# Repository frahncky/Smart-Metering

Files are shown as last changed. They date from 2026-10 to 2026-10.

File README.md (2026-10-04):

# Smart-Metering

Analisador trifásico de energia e qualidade de energia com interface gráfica touchscreen.

## Objetivo

Desenvolver um instrumento completo para medição, visualização e registro de grandezas elétricas em sistemas monofásicos e trifásicos, incluindo:

- tensões e correntes RMS por fase;
- potência ativa, reativa e aparente;
- fator de potência;
- frequência;
- energia importada e exportada;
- demanda;
- diagrama fasorial;
- sequência de fases;
- desequilíbrio de tensão e corrente;
- formas de onda;
- THD;
- espectro harmônico;
- registro de afundamentos, elevações, interrupções e outros eventos de qualidade de energia;
- armazenamento histórico;
- comunicação Ethernet, Wi-Fi e RS-485/Modbus;
- interface local em touchscreen de 7".

## Arquitetura inicial

```text
Rede elétrica
   |
   +--> Proteção e condicionamento de tensão ----+
   |                                             |
   +--> TCs / condicionamento de corrente -------+--> ADE9430
                                                        |
                                                        | SPI
                                                        v
                                              MCU de metrologia
                                                        |
                                              Interface isolada
                                                        |
                                                        v
                                                   ESP32-P4
                                                        |
                                            Touchscreen 7" + LVGL

                     +--> microSD
                     +--> RTC
                     +--> Ethernet
                     +--> RS-485 / Modbus
                     +--> Wi-Fi / Bluetooth via coprocessador
```

## Componentes centrais

- **ADE9430** — front-end de medição polifásica e qualidade de energia.
- **MCU ARM** — aquisição do ADE9430, cálculo complementar, gerenciamento metrológico, calibração e eventos.
- **ESP32-P4** — interface gráfica, touchscreen e serviços de alto nível.
- **ESP32-C6** — opção para Wi-Fi/Bluetooth quando necessário.
- **Touchscreen 7"** — alvo inicial: 1024 × 600, interface capacitiva.

A seleção final do MCU ARM, TCs, display, isoladores, fontes e conectores será feita antes do fechamento do esquemático.

## Estrutura do repositório

```text
Smart-Metering/
├── hardware/
│   ├── README.md
│   └── Smart-Metering/
│       ├── Smart-Metering.kicad_pro
│       ├── Smart-Metering.kicad_sch      # folha raiz hierárquica
│       ├── 01_Power_Input.kicad_sch … 09_Power_Supplies.kicad_sch
│       ├── Smart-Metering.kicad_pcb      # layout roteado (todas as ligações feitas; DRC do KiCad pendente)
│       ├── Smart-Metering.kicad_dru      # regras de isolação (clearance/creepage)
│       ├── SmartMetering.kicad_sym       # símbolos próprios
│       ├── sym-lib-table
│       └── 3d/                           # modelos 3D simplificados do projeto (gen3d.py)
├── modelo 3D/                            # gabinete: Onshape (FeatureScripts) e Fusion (montagem, STEP)
├── docs/                                 # arquitetura, requisitos, decisões, layout, revisões
├── AGENTS.md                             # papéis e regras de trabalho dos agentes
└── README.md
```

## Estado

**Fase 2 — esquemático completo da placa de metrologia (rev. 0.1, a revisar no KiCad).**

Todas as 9 folhas estão desenhadas e os sinais entre folhas foram conferidos (223 componentes):

| Folha | Conteúdo |
|---|---|
| `01_Power_Input` | Alimentação pelas fases medidas (OU de diodos, qualquer fase presente) ou entrada auxiliar, por montagem; AC/DC isolado RECOM RAC20-05SK/277 (85–305 VAC, 5 V / 4 A) → `VIN_ACDC` |
| `02_Voltage_Sensing` | 3 fases: fusível + varistor, divisor 1/1001 (5 × 200 kΩ + 1 kΩ), anti-aliasing 7,2 kHz; R201 liga neutro ao GND metrológico |
| `03_Current_Sensing` | IA/IB/IC/IN configuráveis por montagem: TC 333 mV (padrão), Rogowski ou SCT-013 de 1 V; TVS, anti-aliasing 7,2 kHz, pino de identificação; headers internos para conectores M8 de painel |
| `04_ADE9430` | ADE9430 (U401), desacoplamento, cristal 24,576 MHz, reset |
| `05_Metrology_MCU` | STM32F413RHT6 (mesma família da referência da biblioteca ADSW-PQ-CLS), HSE 8 MHz, RTC com LSE + CR2032, EEPROM de calibração 24LC64, SWD, LEDs |
| `06_Isolation` | Barreira reforçada logo após o ADE9430: ISO7762 + ISO7761, MCP3204 (ID dos sensores), ADuM6000 + TPS7A20 → `+3V3_ADE` |
| `07_HMI_Interface` | Conector para a placa HMI (ESP32-P4): +5V com PTC, UART, IRQ e EN |
| `08_Communications` | RS-485/Modbus isolada (ADM2587E) e USB-C de serviço (USB FS + carga) |
| `09_Power_Supplies` | OU de entradas 5 V, carregador chaveado BQ25895 (entrada até 3 A, I2C), `+3V3` (TPS63001) e `+5V` (TPS61022) |

A HMI (ESP32-P4 + ESP32-C6, display 7", Ethernet, Wi-Fi/BT, microSD) fica em placa separada (REQ-010). No protótipo: Espressif ESP32-P4-Function-EV-Board.

Componentes de terceiros usam os símbolos oficiais da biblioteca KiCad 10; a biblioteca `SmartMetering` guarda só os símbolos próprios. Referências numeradas por folha (1xx na folha 01, 2xx na 02, …).

### Próximos passos

Revisão completa em [`docs/REVISAO_ESQUEMATICO.md`](docs/REVISAO_ESQUEMATICO.md); as pendências P1–P9 estão resolvidas.

- Rodar o ERC no KiCad e revisar.
- Confirmações de compra: variante CP-40 do ADE9430, certificação reforçada do ADuM6000, encapsulamento do RAC20-05SK/277.
- Firmware: configurar o BQ25895 por I2C (ICHG, VREG, VINDPM) e desabilitar o VBUS sensing do OTG no STM32.
- Layout da PCB (ver [`docs/LAYOUT.md`](docs/LAYOUT.md)): placa roteada (domínio quente, lado seguro e ilha RS-485) com creepage de 8 mm na barreira; todas as ligações feitas (rev. 0.6); falta preencher as zonas e rodar o DRC do KiCad (inclui creepage); os avisos de largura esperados estão listados no LAYOUT. Todos os componentes têm modelo 3D.

## Bateria interna

Bateria Li-Po plana 1S recarregável, com NTC, carregada pelo BQ25895 com o medidor ligado à rede (folha 09, J901). Autonomia a definir; a meta anterior de 13 horas foi retirada. Ver [bateria e alimentação](docs/INTERNAL_BATTERY.md).

## Método de trabalho

Papéis dos agentes e regras de colaboração: [AGENTS.md](AGENTS.md). Etapas, revisão e rastreabilidade: [docs/WORKFLOW.md](docs/WORKFLOW.md). Decisões de projeto: [docs/DECISIONS.md](docs/DECISIONS.md). Dimensionamentos: [entradas de tensão](docs/VOLTAGE_SENSING.md), [fonte metrológica e clock](docs/POWER_CLOCK.md).

## Referências principais

- Analog Devices ADE9430: https://www.analog.com/en/products/ade9430.html
- Espressif ESP32-P4: https://documentation.espressif.com/esp32-p4_datasheet_en.html

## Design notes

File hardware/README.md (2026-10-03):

# Hardware

## Projeto KiCad

O projeto principal está em:

```text
hardware/Smart-Metering/
```

Arquivos principais:

- `Smart-Metering.kicad_pro`
- `Smart-Metering.kicad_sch`
- `Smart-Metering.kicad_pcb`

## Organização planejada do esquemático

O esquemático será hierárquico.

Folhas previstas:

1. `Power_Input`
2. `Voltage_Sensing`
3. `Current_Sensing`
4. `ADE9430`
5. `Metrology_MCU`
6. `Isolation`
7. `HMI_Interface`
8. `Communications`
9. `Power_Supplies`

A primeira implementação deverá começar por `Power_Supplies`, `Voltage_Sensing`, `Current_Sensing` e `ADE9430`.

## Regras

- manter símbolos e footprints personalizados dentro do repositório;
- não usar caminhos absolutos para bibliotecas próprias;
- registrar no Git os arquivos `.kicad_pro`, `.kicad_sch` e `.kicad_pcb`;
- não registrar backups e arquivos locais do KiCad;
- documentar alterações importantes de hardware antes de iniciar layout.

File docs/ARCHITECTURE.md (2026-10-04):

# Arquitetura do sistema

## 1. Princípio de projeto

O instrumento será dividido em dois domínios funcionais:

1. **domínio metrológico**, responsável pela aquisição elétrica, cálculos e eventos;
2. **domínio HMI/comunicação**, responsável pela tela, gráficos, armazenamento de alto nível e conectividade.

Essa separação evita que carga gráfica, rede ou interface do usuário interfiram na medição.

## 2. Cadeia de medição

### Tensão

Entradas previstas:

- VA;
- VB;
- VC;
- VN.

A entrada deverá conter proteção contra surtos/transientes, limitação, divisor resistivo de precisão e filtro anti-aliasing compatível com o ADE9430.

### Corrente

Entradas previstas:

- IA;
- IB;
- IC;
- IN opcional.

A solução inicial será baseada em transformadores de corrente (TCs). O circuito deverá permitir escolha posterior do TC e do burden sem alterar a arquitetura geral.

### Conversão e metrologia

O ADE9430 será o núcleo de aquisição.

Funções previstas:

- aquisição simultânea polifásica;
- tensão e corrente RMS;
- potências;
- energias;
- frequência;
- fator de potência;
- ângulos;
- formas de onda;
- grandezas necessárias para qualidade de energia.

Comunicação ADE9430 ↔ MCU: **SPI**.

## 3. Processador de metrologia

MCU: **STM32F413RHT6** (Cortex-M4F, 100 MHz, 1,5 MB flash, 320 KB RAM, LQFP-64).

Escolhido por ser da mesma família da plataforma de referência da biblioteca ADSW-PQ-CLS (IEC 61000-4-30 Classe S) da Analog Devices, a NUCLEO-F413ZH, o que reduz o risco de portar a biblioteca.

Responsabilidades:

- configuração e leitura do ADE9430 (SPI1 isolado) e do ADC de identificação dos sensores;
- calibração;
- processamento de formas de onda e análise harmônica complementar;
- sequência e desequilíbrio;
- detecção e registro de eventos com timestamp (RTC interno + LSE + CR2032);
- protocolo com a HMI (USART2) e Modbus RTU (USART3 + RS-485 isolada);
- USB de serviço (USB FS);
- watchdog e autodiagnóstico.

## 4. Isolação

A barreira de isolação reforçada fica **logo após o ADE9430** (folha `06_Isolation`).

- **Domínio metrológico** (potencial da rede, GND = neutro): entradas de tensão e corrente, ADE9430, ADC de identificação dos sensores.
- **Domínio seguro** (`GND_SYS`): MCU de metrologia, ESP32-P4, display, USB-C, Ethernet, RS-485, microSD.

Elementos da barreira:

- isoladores digitais reforçados (ISO7762 + ISO7761, 5 kVrms) para SPI, IRQ0/IRQ1, DREADY, ZX, CF1/CF2 e RESET;
- DC/DC isolado reforçado (≥ 4 kVAC, tensão de trabalho ≥ 300 VAC) + LDO gerando `+3V3_ADE`;
- distância de escoamento ≥ 8 mm sob a barreira, a confirmar pela IEC 61010-1 para CAT III 300 V.

Com isso o MCU pode ser gravado e depurado sem isolação de bancada, e todas as interfaces acessíveis ao usuário ficam no domínio seguro.

## 5. HMI

A HMI fica em **placa separada** (REQ-010), ligada à placa de metrologia pelo conector J701 (+5V, UART, IRQ, EN).

Processador: **ESP32-P4**, com **ESP32-C6** para Wi-Fi 6 e Bluetooth 5.

Protótipo: **Espressif ESP32-P4-Function-EV-Board** com o kit de LCD 7" 1024 × 600 MIPI-DSI. A placa já inclui Ethernet, microSD e USB, cobrindo REQ-007 e REQ-008 do lado da HMI.

Funções:

- LVGL;
- touchscreen;
- gráficos em tempo real;
- formas de onda;
- diagrama fasorial;
- espectro harmônico;
- histórico;
- menus de configuração;
- diagnóstico;
- atualização de firmware.

## 6. Telas planejadas

### Visão geral

- VA/VB/VC;
- IA/IB/IC;
- P/Q/S;
- FP;
- frequência;
- energia;
- demanda;
- THD;
- sequência de fases.

### Formas de onda

- tensões;
- correntes;
- seleção por fase;
- zoom;
- congelamento;
- evento capturado.

### Fasores

- vetores VA/VB/VC;
- vetores IA/IB/IC;
- ângulos;
- sequência ABC/ACB;
- desequilíbrio.

### Harmônicos

- seleção de tensão ou corrente;
- harmônicos por ordem;
- THD;
- tabela e gráfico de barras.

### Qualidade de energia

- sag;
- swell;
- interrupção;
- desequilíbrio;
- eventos;
- tendência;
- registro associado de forma de onda.

### Energia e demanda

- energia ativa;
- energia reativa;
- importação/exportação;
- demanda;
- máximos;
- histórico.

## 7. Interfaces externas

Previstas:

- Ethernet;
- RS-485 / Modbus RTU;
- USB-C de serviço;
- microSD;
- RTC;
- Wi-Fi;
- Bluetooth.

## 8. Ordem de desenvolvimento

1. requisitos elétricos;
2. alimentação;
3. entrada de tensão;
4. entrada de corrente;
5. ADE9430;
6. MCU de metrologia;
7. isolação;
8. comunicação entre placas;
9. ESP32-P4;
10. display/touch;
11. Ethernet/RS-485/Wi-Fi;
12. PCB;
13. firmware metrológico;
14. HMI;
15. calibração e ensaios.

## 9. Alternativas avaliadas

Em 2026-10-03 foi registrada no `main` uma arquitetura de referência alternativa. A rev. 0.1 do esquemático e do layout mantém os componentes já implementados; a tabela fica como registro para revisões futuras.

| Função | Implementado (rev. 0.1) | Alternativa avaliada |
|---|---|---|
| MCU de metrologia | STM32F413RHT6 | MAX32650 |
| Isolamento SPI/sinais | ISO7762 + ISO7761 | ADuM4152 |
| Alimentação isolada do domínio metrológico | ADuM6000 + TPS7A20 | ADuM6424A |
| RS-485 isolado | ADM2587E | ADM2867E |
| RTC | RTC interno do STM32 com LSE e CR2032 | MAX31343 |
| Wi-Fi/Bluetooth (placa HMI) | ESP32-C6 (placa de avaliação do ESP32-P4) | ESP32-C5 |
| Ethernet PHY (placa HMI) | da placa de avaliação do ESP32-P4 | DP83825I |

Os itens da placa HMI (Wi-Fi/Bluetooth, Ethernet, display MIPI-DSI) não afetam a placa de metrologia e podem ser adotados quando a HMI própria for projetada.

## 10. Alimentação e bateria interna

Entrada de 127/220 V AC pelo AC/DC RAC20-05SK/277 (folha 01). Li-Po plana 1S interna e protegida, com carregador BQ25895 com power path; `VSYS` alimenta o `+3V3` (TPS63001), o `+5V` (TPS61022) da HMI e o DC/DC isolado (ADuM6000) do domínio metrológico. Capacidade e autonomia em aberto; a proposta antiga de 13 h com pack 4S foi substituída. O `GND_SYS` (bateria, carregador, HMI) não se liga ao GND metrológico. Detalhes e pendências em `INTERNAL_BATTERY.md`.

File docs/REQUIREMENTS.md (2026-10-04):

# Requisitos iniciais

Documento de requisitos preliminar. Valores metrológicos definitivos serão fechados após a definição da classe de precisão e dos sensores.

## REQ-001 — Topologias elétricas

O instrumento deverá suportar, como objetivo de projeto:

- monofásico;
- trifásico 3 fios;
- trifásico 4 fios.

## REQ-002 — Redes alvo

O primeiro protótipo será orientado às redes:

- 127/220 V;
- 220/380 V;
- 60 Hz.

A faixa final de entrada será definida no dimensionamento do front-end.

## REQ-003 — Canais

Mínimo:

- 3 canais de tensão de fase;
- 3 canais de corrente;
- neutro como referência de tensão.

Desejável:

- canal de corrente de neutro.

## REQ-004 — Grandezas

O equipamento deverá medir ou calcular:

- tensão RMS;
- corrente RMS;
- potência ativa;
- potência reativa;
- potência aparente;
- fator de potência;
- frequência;
- energia ativa;
- energia reativa;
- demanda;
- ângulo de fase;
- sequência de fases;
- desequilíbrio.

## REQ-005 — Qualidade de energia

O projeto deverá prever:

- formas de onda;
- THD de tensão;
- THD de corrente;
- harmônicos individuais;
- afundamentos;
- elevações;
- interrupções;
- eventos com timestamp;
- captura de forma de onda associada ao evento.

O suporte integral à IEC 61000-4-30 Classe S dependerá da implementação e, quando aplicável, da biblioteca específica da Analog Devices.

## REQ-006 — Interface local

O equipamento deverá possuir:

- touchscreen colorido;
- alvo inicial de 7";
- resolução alvo de 1024 × 600;
- interface gráfica responsiva;
- operação sem necessidade de computador externo.

## REQ-007 — Armazenamento

Deverá haver armazenamento local para:

- histórico;
- eventos;
- configurações;
- registros de calibração;
- capturas de formas de onda.

Tecnologia inicial: microSD + memória não volátil interna.

## REQ-008 — Comunicação

Previstas:

- Ethernet;
- RS-485 / Modbus RTU;
- Wi-Fi;
- Bluetooth;
- USB-C para manutenção.

Protocolos adicionais poderão ser definidos posteriormente.

## REQ-009 — Segurança

O projeto deverá contemplar:

- proteção de entrada;
- isolamento adequado;
- fusíveis/proteções quando aplicável;
- separação física entre alta e baixa tensão;
- distâncias de isolação adequadas;
- gabinete que impeça acesso do usuário às partes energizadas.

## REQ-010 — Modularidade

A placa de metrologia deverá ser funcionalmente separável da placa de HMI, permitindo:

- desenvolvimento independente;
- substituição futura da HMI;
- ensaios metrológicos sem interface gráfica;
- redução da interferência entre subsistemas.

## REQ-011 — Alimentação e bateria interna

Entrada nominal de 127 V ou 220 V AC, 60 Hz, sem seletor manual. Bateria interna Li-Po plana recarregável, com proteção própria, sensor de temperatura e gerenciamento automático entre fonte e bateria. Capacidade, dimensões, peso e autonomia serão definidos pelo gabinete e pelo consumo reais. A exigência anterior de 13 horas foi retirada; o uso não fica limitado a salvar dados ou desligar.

O pack deve ser acessível para manutenção, acomodado sem compressão e com folga mecânica conforme o fabricante. Configuração 1S, com tensão de carga compatível com a célula escolhida. Bateria e HMI pertencem ao domínio seguro (`GND_SYS`), sem ligação direta ao GND metrológico referenciado à rede. Carga e descarga devem respeitar os limites térmicos e elétricos do pack.

Implementação: folha 09 (J901, BQ25895, TPS63001, TPS61022) e AC/DC RAC20-05SK/277 na folha 01. Ver `INTERNAL_BATTERY.md`.

## Pendências de definição

- classe de precisão alvo;
- corrente nominal e corrente máxima;
- modelo e relação dos TCs;
- necessidade de corrente de neutro;
- MCU ARM definitivo;
- modelo exato do display;
- estratégia de alimentação;
- topologia de isolação;
- requisitos de certificação;
- gabinete e dimensões mecânicas.

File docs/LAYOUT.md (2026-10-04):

# Layout da placa de metrologia — rev. 0.6 (placa roteada, todas as ligações feitas)

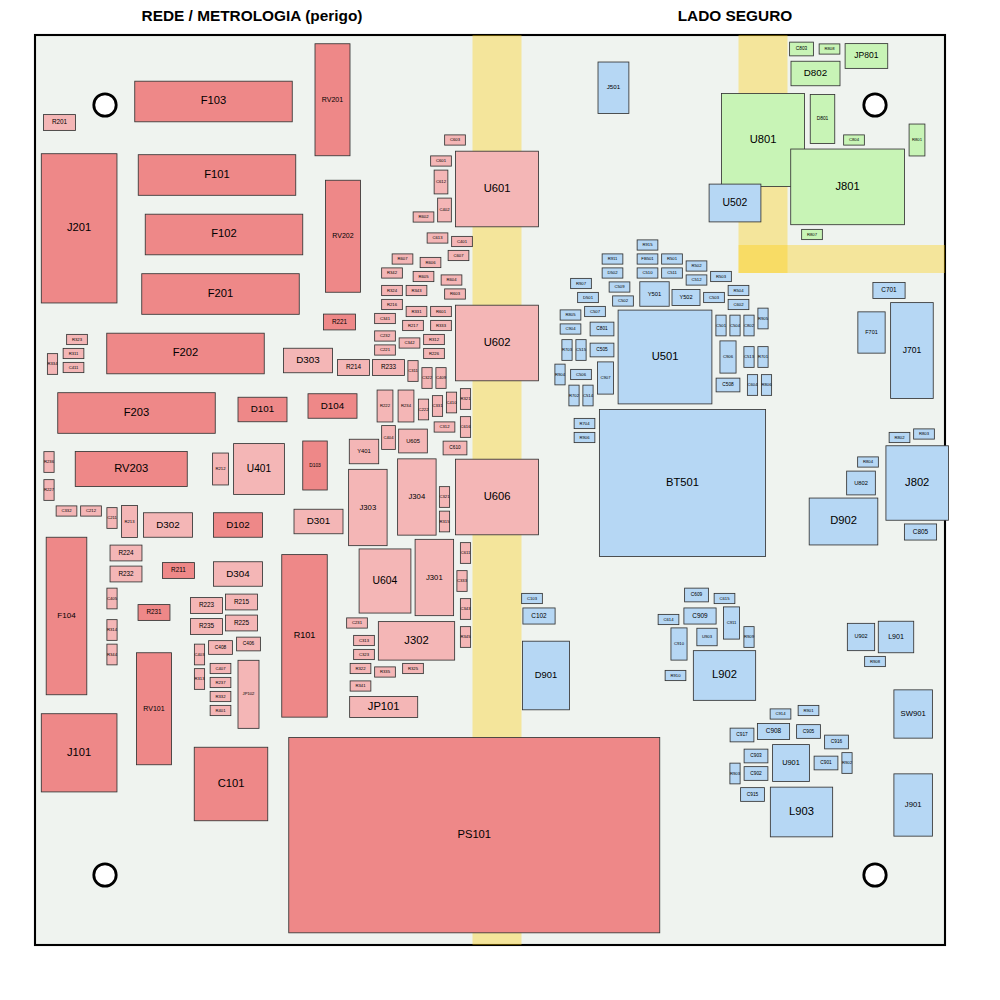
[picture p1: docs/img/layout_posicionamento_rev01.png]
Posicionamento inicial (rev. 0.1, antes dos ajustes para o roteamento)


*Vermelho escuro: nets de rede. Vermelho claro: domínio metrológico (potencial da rede). Azul: domínio seguro. Verde: RS-485 isolada. Amarelo: faixas da barreira (sem cobre).*

## Placa roteada (rev. 0.6)

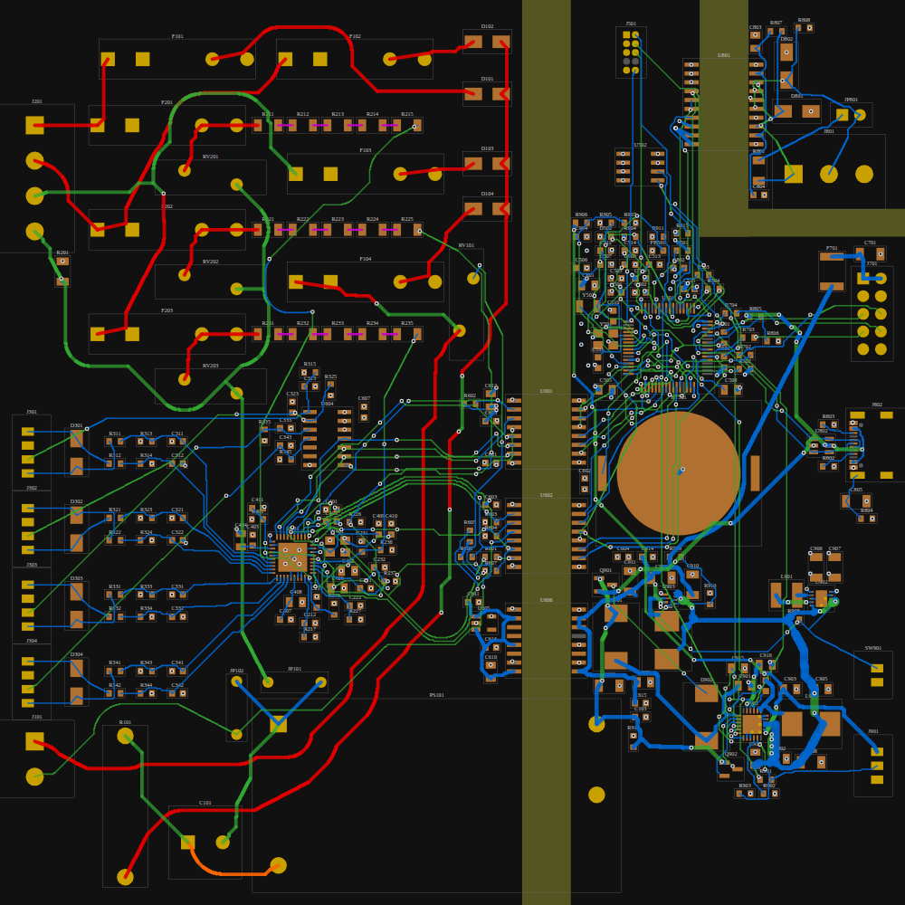
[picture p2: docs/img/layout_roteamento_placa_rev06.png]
Placa inteira


Domínio quente e lado seguro (com a ilha RS-485) roteados com as regras abaixo, a creepage de 8 mm na barreira e as correções da revisão do PR #1. Na rev. 0.5 todas as ligações do esquemático estão feitas (ver "Ligações da rev. 0.5" abaixo).

| Domínio quente | Lado seguro e ilha RS-485 |
|---|---|
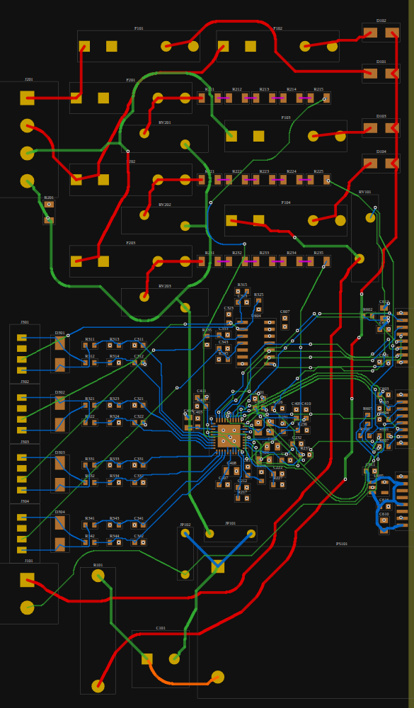
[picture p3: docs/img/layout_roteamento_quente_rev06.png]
Domínio quente
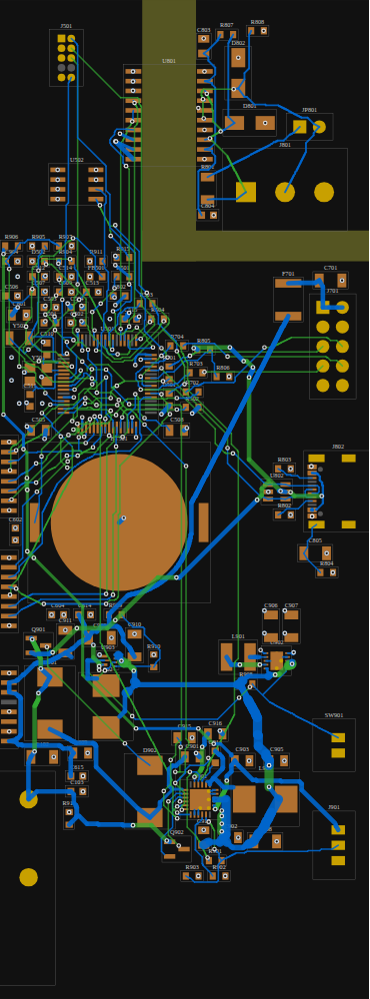
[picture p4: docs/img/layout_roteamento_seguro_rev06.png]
Lado seguro
|  |  |

No lado seguro: GND_SYS e GND_485 em In1.Cu, +3V3 em In2.Cu, trilhas de potência (POWER) de 0,6 mm, estreitadas para a largura do pad (0,2 mm) na saída dos CIs de passo fino (U901, U902, U903, J802). Os CIs de passo fino foram deslocados até 0,05 mm para os pads caírem na grade de roteamento. Alguns trechos curtos usam In2.Cu como camada de sinal quando não havia outro caminho (149 trechos na placa); o plano de In2 é preenchido em volta deles. Nas ligações feitas nos reparos há 100 vias menores (0,45/0,2 mm); as demais vias são de 0,6/0,3 mm. As regras da placa (`.kicad_pro`) aceitam essas vias: diâmetro mínimo 0,45 mm, furo mínimo 0,2 mm.

### Rev. 0.2 (só o domínio quente)

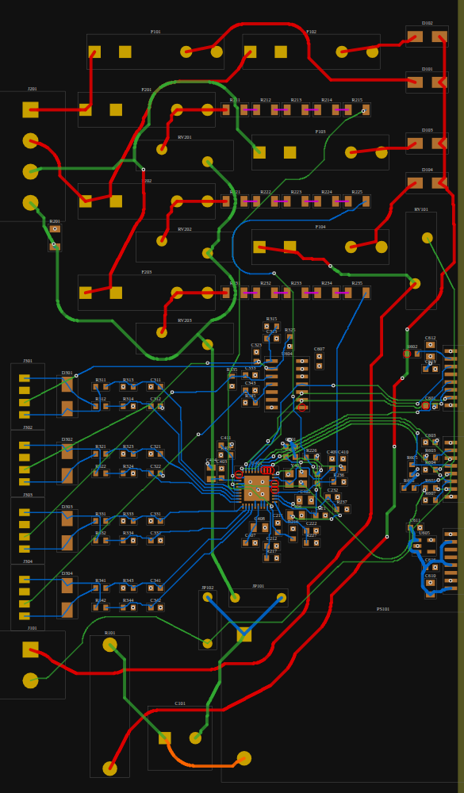
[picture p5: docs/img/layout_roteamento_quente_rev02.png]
Roteamento do domínio quente, rev. 0.2


*Vermelho: rede (MAINS/HVBUS). Magenta: nós internos dos divisores. Azul: sinais do domínio metrológico em F.Cu. Verde: B.Cu. Círculos vermelhos: pads ainda sem ligação.*

O **domínio quente** (à esquerda da barreira) está **roteado em parte**: entradas de rede, fusíveis, varistores, divisores de tensão, entradas de corrente, ADE9430 com desacoplamento, cristal e filtros, lado quente dos isoladores e entrada do PS101, com as ligações pendentes listadas abaixo. O lado seguro e a ilha RS-485 ficam para a próxima etapa.

Regras usadas pelo roteador (iguais ou mais rígidas que as do `.kicad_dru`):

| Situação | Distância mínima |
|---|---|
| Rede ↔ rede de outra fase, rede ↔ domínio metrológico | 3,0 mm (roteado com 3,2 mm) |
| Divisor ↔ divisor de outra fase | 3,0 mm |
| Divisor ↔ sinais do domínio metrológico | 2,0 mm (0,5 mm na mesma fase) |
| Sinais do domínio metrológico entre si | 0,2 mm |
| Trilhas | rede 0,5 mm; divisores 0,3 mm; NEUTRAL/HV_RTN/+5V_ISO 0,5 mm; +3V3_ADE/GND 0,4 mm; sinais 0,2 mm (0,25 mm nos pinos de alimentação do ADE9430) |
| Vias | 0,6 / 0,3 mm |

Decisões de layout:

- **Neutro** em espinha na B.Cu, ligando RV201–RV203, J201 e JP101 por baixo das linhas de fase (que ficam na F.Cu).
- **Retificadores D101–D104** agrupados ao lado de F101–F104, com o catodo comum voltado para a barreira. O barramento retificado desce por uma coluna própria (x ≈ 61 mm) entre os filtros das entradas de tensão e o grupo U604/pull-ups, sem cruzar o ADE9430.
- **ADE9430**: entradas de corrente pelo lado esquerdo (pinos 7–14), tensões pelo lado de baixo e direito, sinais digitais por cima. Pinos de GND ligados direto ao pad exposto, com 5 vias no EP para o plano GND (In1.Cu).
- **Planos**: GND em In1.Cu e +3V3_ADE em In2.Cu no domínio quente; ligações por vias junto de cada pad.

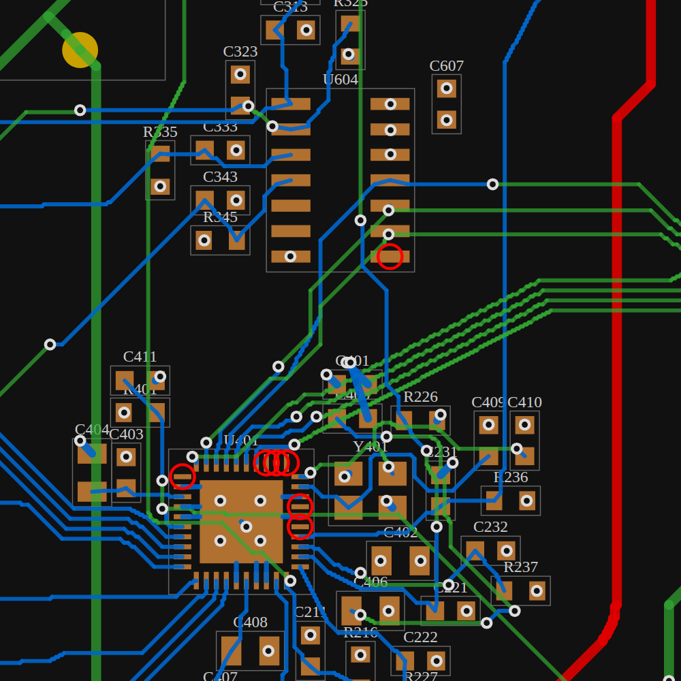
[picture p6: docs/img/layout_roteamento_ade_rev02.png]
Entorno do ADE9430


### Verificação

Verificação geométrica própria da placa inteira (trilha/via contra todo cobre de outro net, barreiras e borda): **0 violações** com as distâncias da tabela acima. Menor distância entre cobre quente e cobre seguro através da barreira (fora as fileiras de pads dos próprios isoladores): **8,02 mm**.

**Falta preencher as zonas (tecla B) e rodar o DRC do KiCad** (inclui creepage e as regras do `.kicad_dru`). O KiCad não roda no ambiente usado para o roteamento; essas duas etapas precisam ser feitas no KiCad local, com os resultados classificados aqui antes de fabricar (`WORKFLOW.md`).

### Rev. 0.6: cristal do MCU e boost de 5 V

Sete componentes mudaram de lugar, sem mexer nos demais. A fonte de verdade das posições e do roteamento é o próprio `Smart-Metering.kicad_pcb`: o gerador e o roteador usados para produzi-lo não estão no repositório, então as próximas mudanças devem ser feitas no KiCad sobre este arquivo.

- **Y501** (cristal HSE de 8 MHz) girado 180° e baixado 0,75 mm, para o HSE_IN (pino 5) e o HSE_OUT (pino 6) do U501 chegarem ao cristal sem se cruzar.
- **C510 e C511** (15 pF, carga do HSE) agora ficam a ~1,7 mm dos pads do Y501; antes estavam a 10–12 mm. HSE_IN tem 1,5 mm e HSE_OUT 5,4 mm, só na F.Cu e sem vias (antes ~10 mm com 3 vias e 3 camadas).
- **C906 e C907** (22 µF, saída de +3V3) saíram de perto do Y501 e foram para o lado do U902, que gera o +3V3.
- **L902** girado e encostado no U903. O SW_5V tem agora 5,7 mm na F.Cu, sem vias: 0,3 mm dentro do courtyard do U903 (saída do pino 2, entre os pinos 1 e 3 com passo de 0,55 mm), um degrau de 0,4 mm na borda e 0,6 mm daí até o pad do indutor. Antes eram ~9 mm de 0,25–0,35 mm com duas vias. O +5V do pino 3 desce para a B.Cu por duas vias de 0,45 mm em paralelo, passando por baixo do SW.

As trilhas que ficaram sob os componentes movidos foram refeitas. Verificação: 0 ligações abertas, 0 violações e 8,02 mm na barreira.

**Saída VSYS do U901:** o L903 foi deslocado 1 mm para a direita, abrindo espaço entre os pinos SYS (15/16) do BQ25895 e o pad CHG_SW do indutor. A saída tem agora 0,75 mm sobre os dois pinos (dentro do courtyard) e 1,2 mm na F.Cu até o C902, em paralelo com o caminho de 1,2 mm da B.Cu (4 vias). Antes, o primeiro trecho tinha 0,4 mm.

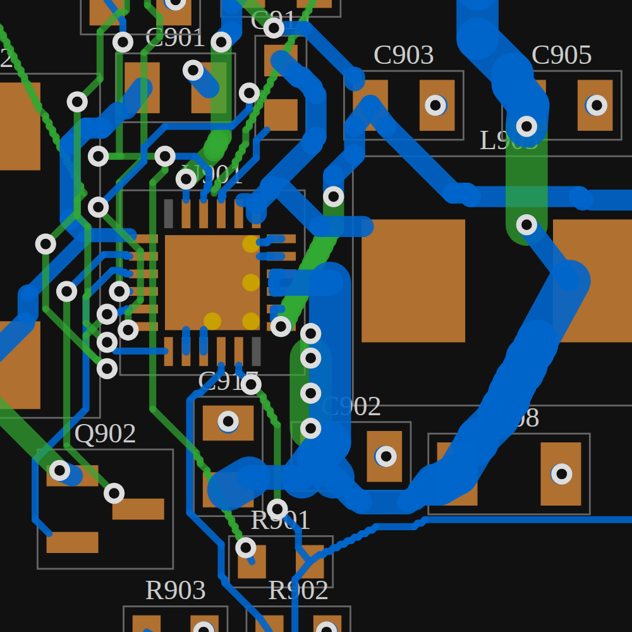
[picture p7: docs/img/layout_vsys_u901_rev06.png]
Saída VSYS do U901


| Cristal do MCU (Y501, C510, C511) | Boost de 5 V (U903, L902) |
|---|---|
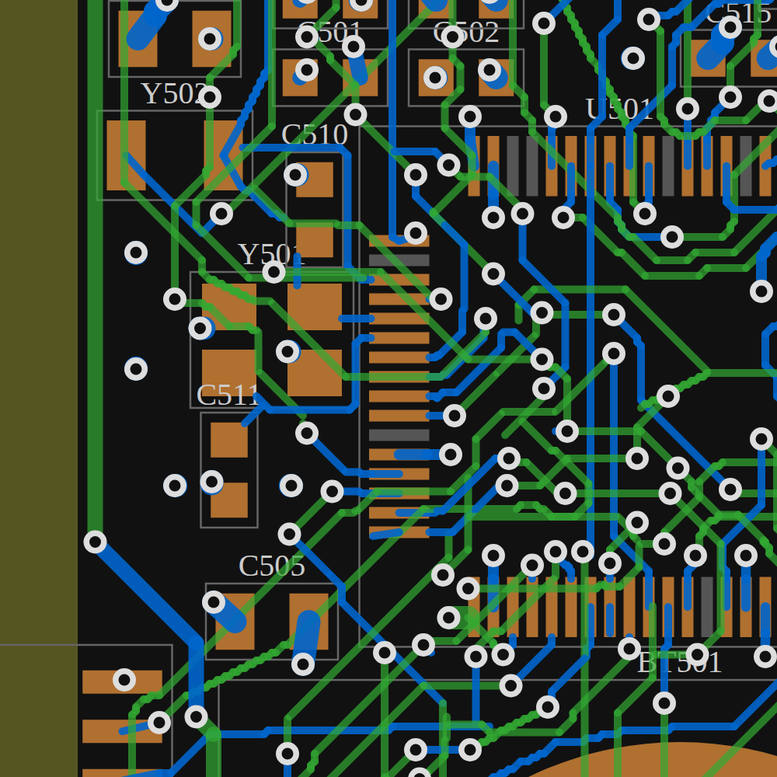
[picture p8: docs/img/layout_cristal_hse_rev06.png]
Cristal HSE
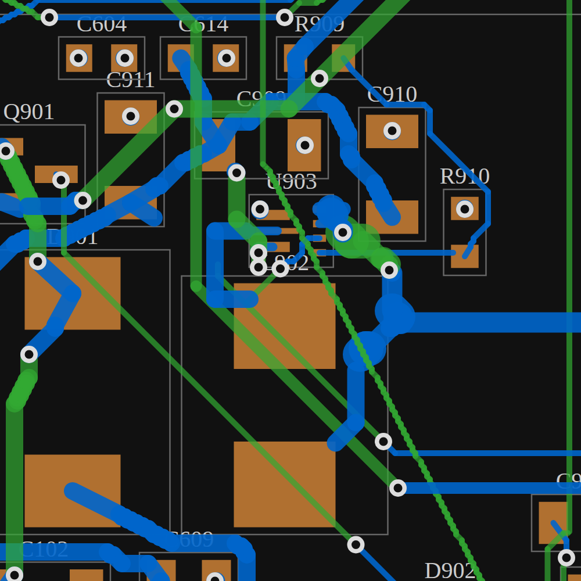
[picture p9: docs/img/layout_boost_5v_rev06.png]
Boost 5 V
|  |  |

### Ligações da rev. 0.5

Na rev. 0.4 havia 10 pads listados como pendentes. Uma verificação de conectividade da placa inteira (cobre de cada net agrupado por contato, vias e planos) achou mais 5 ligações abertas que o roteador tinha dado como feitas: VSYS (U901.15/16 isolados do resto), VBUS (pinos do J802), HSE_IN (C510), VDDA (C506) e +3V3_ADE (R605/R606 sem via para o plano). As 15 foram ligadas por um roteador local em grade de 0,05 mm, que remove e refaz as trilhas vizinhas quando o caminho está fechado (pinos de passo fino do U401, U501 e U901). Cerca de 40 nets vizinhos foram refeitos nessas regiões.

Depois disso: 0 ligações abertas, 0 violações de distância na verificação própria e 8,02 mm de distância mínima entre cobre quente e seguro.

Pontos a revisar no KiCad:

| Net | Situação | Sugestão |
|---|---|---|
| /Power Supplies/VSYS | resolvido na rev. 0.6 (L903 deslocado; saída de 0,75 mm sobre os pinos e 1,2 mm até o C902) | — |
| /Power Supplies/SW_5V | resolvido na rev. 0.6 (L902 junto do U903, 5,7 mm sem vias) | — |
| /Power Supplies/VBAT | ramo até o divisor R906 com ~83 mm de trilha de 0,4 mm (corrente de µA) | aceitável; encurtar se R906 for aproximado do U901 |
| CHG_N | ~73 mm entre U901.4 e o MCU | aceitável (sinal lento) |

As trilhas de VSYS e SW_5V foram alargadas até a maior largura que respeita as distâncias (a maior parte do VSYS ficou com 0,7–1,2 mm).

Regra de largura das trilhas de potência (`.kicad_dru`): mínimo de 0,6 mm para a classe POWER, com exceção de 0,2 mm só dentro do courtyard dos CIs de passo fino (U901, U902, U903, J802), onde o estreitamento até o pad é obrigatório. As demais trilhas POWER foram alargadas para 0,6 mm onde as distâncias permitiam, sem reduzir os 8 mm da barreira.

O DRC do KiCad deve acusar estes trechos POWER abaixo de 0,6 mm (69 trechos na rev. 0.6, para revisar e classificar):

| Net | Trechos | Comprimento | Larguras | Situação |
|---|---|---|---|---|
| /Power Supplies/VBAT | 14 | 80,5 mm | 0,4 mm | ramo até o divisor R906 (µA); aceitável ou mover R906 |
| GND_SYS | 20 | 14,4 mm | 0,25–0,4 mm | ligações curtas a vias do plano; conferir |
| +3V3 | 20 | 10,2 mm | 0,2–0,4 mm | ligações curtas a vias do plano e pinos do MCU; conferir |
| +5V | 8 | 4,5 mm | 0,51–0,54 mm | estreitamento junto a pads; conferir |
| /Power Supplies/VIN_CHG | 1 | 2,4 mm | 0,4 mm | conferir |
| CHG_SW, VSYS, VIN_ACDC | 6 | 0,6 mm | 0,54 mm | estreitamento na entrada de pads |

Próximos passos: preencher as zonas (**B**), rodar o DRC, revisar os pontos onde a rede cruza o domínio metrológico em camadas diferentes (o plano GND em In1.Cu e o +3V3_ADE em In2.Cu passam sob essas trilhas; avaliar recortar os planos sob as trilhas de rede) e conferir os laços de comutação de U606 e U605.

## Estado do posicionamento

`hardware/Smart-Metering/Smart-Metering.kicad_pcb` contém:

- contorno de **130 × 130 mm**, 4 camadas (F.Cu, In1.Cu = GND, In2.Cu = PWR, B.Cu);
- **4 furos M3** a 10 mm das bordas (espaçamento de 110 × 110 mm);
- **226 componentes** com footprints oficiais do KiCad, nets nos pads e vínculo com o esquemático (`path`), de modo que *Tools → Update PCB from Schematic* reconhece todos;
- **posicionamento inicial** por domínio: cada componente fica perto do CI ao qual se liga;
- **faixas de barreira** como áreas proibidas para cobre: 7 mm entre metrologia e lado seguro (x = 75 a 82 mm; os pads dos isoladores SOIC-16W ficam a 7,3 mm entre fileiras) e 7/4 mm em volta da ilha RS-485;
- **planos de terra por domínio** em In1.Cu e B.Cu (GND, GND_SYS, GND_485), ainda sem preenchimento (pressionar **B** no KiCad);
- placa inteira roteada (domínio quente, lado seguro e ilha RS-485), com todas as ligações feitas (rev. 0.6).

Componentes que atravessam a barreira:

| Ref | Função | Lado da rede / isolado | Lado seguro |
|---|---|---|---|
| U601, U602 | isoladores ISO776x | lado 2 / lado 1 | lado 1 / lado 2 |
| U606 | ADuM6000 (alimentação isolada) | pinos 9–16 | pinos 1–8 |
| PS101 | AC/DC RAC20 | entrada (pinos 1, 2) | saída (pinos 4, 5) |
| U801 | ADM2587E (RS-485) | — | lógica (pinos 1–10); barramento (11–20) na ilha |

## Classes de net e regras

Classes definidas em `Smart-Metering.kicad_pro`:

| Classe | Conteúdo | Trilha |
|---|---|---|
| MAINS | fases, nós dos fusíveis, barramento HV, entrada auxiliar | 0,5 mm |
| DIVIDER_A, DIVIDER_B, DIVIDER_C | nós internos das cadeias de resistores dos divisores, uma classe por fase | 0,3 mm |
| HVBUS | barramento retificado da fonte auxiliar (HV_DC) | 0,5 mm |
| HOT | domínio metrológico (GND = neutro) | 0,2 mm |
| ISO485 | barramento RS-485 isolado | 0,25 mm |
| POWER | alimentação do lado seguro (VSYS, +5V, +3V3, comutação dos conversores) | 0,6 mm |
| Default | sinais do lado seguro | 0,2 mm |

Regras em `Smart-Metering.kicad_dru` (valores iniciais, **conferir na IEC 61010-1, CAT III 300 V, grau de poluição 2**):

| Regra | Clearance | Creepage |
|---|---|---|
| Barreira reforçada: HOT/MAINS/HVBUS/DIVIDER_x ↔ lado seguro/ISO485 | 6,0 mm | 8,0 mm |
| Entre as fileiras de pads de U601/U602/U606 (isolação do próprio componente; avaliar fenda sob o encapsulamento) | 6,0 mm | 7,2 mm |
| Rede entre fases e neutro: MAINS ↔ MAINS/HOT | 3,0 mm | 3,0 mm |
| Barramento HV ↔ MAINS/HOT/DIVIDER_x | 3,0 mm | 3,0 mm |
| Divisores de fases diferentes: DIVIDER_x ↔ DIVIDER_y | 3,0 mm | 3,0 mm |
| Divisor ↔ domínio metrológico (exceto o VxP da mesma fase) | 2,0 mm | 2,0 mm |
| Divisor ↔ rede de outras fases | 3,0 mm | 3,0 mm |
| RS-485 isolada ↔ lado seguro | 3,0 mm | — |

Os nós internos dos divisores ficam nas classes DIVIDER_A, DIVIDER_B e DIVIDER_C (uma por fase), para que o DRC do KiCad confira as distâncias entre fases. Na barreira, o roteador mantém o cobre quente até x = 73,65 mm e o seguro a partir de x = 83,2 mm (eixo das trilhas e vias), o que dá ≥ 8 mm também até os pads dos isoladores.

## Antes do roteamento (ajustes manuais)

1. **Placa e gabinete:** ajustar o FeatureScript `modelo 3D/Onshape/SmartMeter_PCBSupports.fs` (metrologia): largura 130 mm, altura 130 mm, furos 110 × 110 mm.
2. **Conectores de borda:** conferir o lado de entrada dos fios dos bornes (J201, J101, J801) e a abertura do USB-C (J802), que devem ficar voltados para fora da placa.
3. **Cadeias dos divisores (R211–R237):** alinhar em linha reta, uma cadeia por fase, com pelo menos 3 mm entre cadeias de fases diferentes.
4. **ADE9430 (U401):**
   - desacoplamentos C401–C408 encostados nos pinos;
   - cristal Y401 a menos de 5 mm;
   - filtros anti-aliasing (C2x1/C2x2, C3x1/C3x2) perto dos pinos de entrada;
   - EP com vias para o GND.
5. **Conversores chaveados** (U901, U902, U903, U606): laço de comutação curto, conforme o layout recomendado de cada datasheet. Vias térmicas nos pads expostos.
6. **ADuM6000 (isoPower):** seguir as regras de EMI do datasheet (capacitância de costura entre GND e GND_SYS através da barreira, se a norma permitir).
7. **Retorno do AC/DC (HV_RTN):** trilha própria até o borne do neutro, sem passar pelo plano GND metrológico.

## Ordem sugerida de roteamento

1. Rede e fonte: entradas, fusíveis, varistores e PS101, com trilhas largas e distâncias de rede.
2. Núcleo metrológico: ADE9430, divisores, entradas de corrente e filtros.
3. Barreira: isoladores, U606 e LDO U605.
4. Lado seguro: MCU, alimentação (BQ25895, TPS63001, TPS61022), USB, HMI, RS-485.
5. Preencher zonas (B), rodar DRC (inclui creepage) e corrigir.

## Modelos 3D

Todos os footprints de componentes têm modelo 3D; só os furos de fixação H1–H4 não têm. No KiCad: Ver → Visualizador 3D; para o gabinete no Onshape: Arquivo → Exportar → STEP.

- modelos oficiais da biblioteca do KiCad (`${KICAD10_3DMODEL_DIR}`) para a maioria dos componentes;
- U401 (ADE9430), U902 (TPS63001) e F701 usam modelos equivalentes da biblioteca oficial (QFN-40 6×6, VSON-10 3×3 e caixa 1812), porque os modelos próprios desses footprints não existem na biblioteca;
- PS101 (RAC20-xxSK), F101–F104/F201–F203 (clipes Littelfuse 111 com fusível 5×20), L902/L903 (Bourns SRP7028A) e U903 (VQFN-7 2×2) usam modelos simplificados do projeto em `hardware/Smart-Metering/3d/`, gerados por `gen3d.py` (CadQuery) a partir das dimensões de datasheet. Altura do PS101 adotada: 23 mm (conferir no datasheet da RECOM antes de fechar o gabinete).

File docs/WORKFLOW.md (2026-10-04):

# Método de desenvolvimento

## Etapas e critérios de saída

| Etapa | Evidência necessária para concluir |
| --- | --- |
| Requisitos | Faixas, topologias, precisão alvo e condições de uso definidas; incertezas identificadas |
| Dimensionamento | Cálculos de nominal/pior caso, tolerâncias e limites dos componentes com fontes oficiais |
| Esquemático | Revisão visual, pinagem e netlist conferidas; ERC classificado; erros de conexão resolvidos |
| Layout | Footprints conferidos; regras de isolação e mecânica definidas; DRC e revisão de retorno de corrente |
| Protótipo | Plano de ensaios, pontos de teste e critérios de aceitação registrados; condições para energização verificadas |
| Firmware e calibração | Aquisição e protocolos testados; ganho/fase calibrados com referência conhecida; resultados registrados |

O avanço é por bloco: uma folha concluída não libera todo o instrumento. Requisitos ainda abertos devem permanecer identificados, com impacto e próxima ação.

## Ciclo de trabalho

1. Coordenador registra objetivo e arquivos atribuídos, após verificar alterações locais.
2. Executor implementa uma alteração funcional delimitada e registra decisões.
3. Revisor independente examina evidências, cálculos e conexões, sem editar o trabalho revisado.
4. Executor corrige achados; coordenador repete apenas os checks afetados e integra os resultados.
5. Registrar resultado, limitações e próximo passo. Commits funcionais são preparados quando solicitados; não incluir mudanças locais não relacionadas.

## Prioridades de revisão

- **P0:** risco imediato ou ação que deve ser interrompida.
- **P1:** erro que bloqueia funcionamento, layout ou energização do bloco.
- **P2:** precisão, robustez ou coerência que precisa ser corrigida antes da conclusão da etapa.
- **P3:** melhoria de documentação ou organização.

Um aviso ERC pode representar problema real e um comando com código de saída zero pode conter erros. Não silenciar regras para obter um relatório limpo. Exceções devem ter justificativa específica.

## Rastreabilidade

Estado da `main` (PRs #1 e #2).

| Requisito | Implementação/evidência | Estado |
| --- | --- | --- |
| REQ-001 topologias | Folha 02; `VOLTAGE_SENSING.md` | 3P4W implementado; 3 fios (sem R201) pendente de validação |
| REQ-002 redes | Divisor 5 × 200 kΩ + 1 kΩ (1/1001), 127/220 V fase-neutro | Dimensionado e roteado; sem ensaio físico |
| REQ-003 canais | VAP/VAN, VBP/VBN, VCP/VCN; IA/IB/IC/IN (folha 03) | Tensão e corrente implementadas; TCs a escolher |
| REQ-004/005 metrologia e qualidade | ADE9430 (folha 04), MCU STM32F413 (folha 05) | Hardware completo; firmware e ensaios pendentes |
| REQ-009 segurança | Folhas 01, 02 e 06; regras de isolação em `Smart-Metering.kicad_dru` | Barreira com creepage de 8 mm no layout; DRC do KiCad e IEC 61010-1 pendentes |
| REQ-010 modularidade | Placa HMI separada (J701) | Interface implementada |
| REQ-011 alimentação/bateria | Folha 09, J901; `INTERNAL_BATTERY.md` | Carregador e power path implementados; pack e ~CE (D-011) pendentes |
| Layout | `Smart-Metering.kicad_pcb`; `LAYOUT.md` | Roteado, todas as ligações feitas (rev. 0.6); zonas e DRC do KiCad pendentes |

## Decisões

Registrar escolhas em `DECISIONS.md`, com contexto, alternativa relevante, consequência e condição de revisão. Para testes de bancada, registrar fonte/instrumento, configuração, resultado medido e limite de aceitação; não substituir medição por cálculo ideal.

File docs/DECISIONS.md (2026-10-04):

# Registro de decisões

Estado de cada decisão em relação ao esquemático e ao layout da `main` (PRs #1 e #2, outubro de 2026).

## D-001 — Separar metrologia e HMI

Estado: implementado.

ADE9430 e MCU de metrologia (STM32F413) fazem a aquisição; a HMI (ESP32-P4) fica em placa separada, ligada por J701. Objetivo: reduzir a interferência da carga gráfica e da rede na aquisição. Ver `ARCHITECTURE.md`.

## D-002 — Iniciar tensão em 3P4W

Estado: implementado no esquemático e no layout, sem ensaio físico.

Três canais fase-neutro com divisor 5 × 200 kΩ + 1 kΩ (1/1001) e filtros de 22 nF (~7,2 kHz). Ganho de tensão 1. Neutro ligado ao GND metrológico por R201 (0 Ω). A versão anterior usava 3 × 330 kΩ (1/991). A topologia sem neutro (R201 não montado) continua pendente de validação. Ver `VOLTAGE_SENSING.md`.

## D-003 — Revisão independente e edição exclusiva por arquivo

Estado: adotado.

Executores e revisores têm responsabilidades separadas. O coordenador integra as mudanças; um único executor modifica cada arquivo KiCad por vez. Isso evita conflitos em arquivos estruturados e permite conferir a implementação com evidência independente. Ver `AGENTS.md` e `WORKFLOW.md`.

## D-004 — Regulador dedicado ao ADE9430

Estado: implementado.

U605 TPS7A2033PDBVR gera `+3V3_ADE` a partir de `+5V_ISO`, a saída do DC/DC isolado U606 ADuM6000. O conector de alimentação externa de protótipo (J1) da versão anterior saiu. Ver `POWER_CLOCK.md`.

## D-005 — Cristal 3225 com CL de 8 pF

Estado: implementado no esquemático (Y401, C409/C410 = 10 pF C0G); confirmação comercial pendente.

Y401: Abracon ABM8-24.576MHZ-8-D1X-T, com sinais nos pinos 1/3 e terra nos pinos 2/4. C409/C410 de 10 pF pressupõem 2 pF de parasita por pino; ajustar depois do layout e do ensaio. Disponibilidade, carga e erro total de frequência ainda precisam ser confirmados.

## D-006 — Li-Po plana interna, sem meta de 13 h

Estado: carregador e power path implementados; pack, capacidade e autonomia pendentes.

Pack 1S protegido com NTC no J901, carregador BQ25895 com power path, `VSYS` alimentando os conversores. Substitui a proposta anterior de pack LiFePO4 4S externo. Ver `INTERNAL_BATTERY.md`.

## D-007 — MCU de metrologia STM32F413

Estado: implementado.

STM32F413RHT6 (mesma família da referência da biblioteca ADSW-PQ-CLS da ADI), com RTC próprio (LSE + CR2032), EEPROM de calibração 24LC64 e SWD. O MAX32650 foi avaliado como alternativa (`ARCHITECTURE.md`, seção 9).

## D-008 — Barreira logo após o ADE9430

Estado: implementado.

ISO7762 + ISO7761 (sinais) e ADuM6000 + TPS7A2033 (alimentação) isolam o domínio metrológico. O MCU, o USB e a HMI ficam no domínio seguro. Creepage mínima de 8 mm na barreira, conferida no layout. As alternativas ADuM4152/ADuM6424A estão em `ARCHITECTURE.md`, seção 9.

## D-009 — AC/DC RECOM RAC20-05SK/277

Estado: implementado.

A RAC20 aceita 85–305 VAC e cobre 220 V +20 % (264 V) com margem. A HLK-20M05 (85–265 VAC) foi considerada e não foi adotada.

## D-010 — Prioridade do AC/DC e detecção da fonte USB

Estado: implementado (revisão do PR #1).

Q901 corta o VBUS quando o AC/DC está presente; Q902 une D+/D− do BQ25895 só com o AC/DC (DCP, 3 A). Só pelo USB-C, a entrada fica limitada a 500 mA por hardware.

## D-011 — Carga desabilitada até a configuração (proposta)

Estado: pendente (P1).

Hoje ~CE está em GND e o BQ25895 carrega com os valores padrão antes do firmware. Proposta: ~CE em GPIO do MCU com pull-up. Ver `INTERNAL_BATTERY.md`.

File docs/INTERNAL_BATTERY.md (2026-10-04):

# Bateria interna e alimentação

## Decisão confirmada

Bateria Li-Po plana, integrada ao gabinete e recarregada com o medidor ligado à rede de 127/220 V. Não existe mais o requisito de 13 h. Capacidade e autonomia continuam abertas; o projeto não pressupõe tela sempre apagada nem uso apenas para salvar dados no desligamento.

Configuração: pack 1S protegido (tipicamente 3,7 V nominal, 4,2 V de carga), com NTC de 10 kΩ. Não usar pack 4S de 12,8 V nem bateria externa de 20 Ah como referência.

## Arquitetura implementada (folhas 01, 06, 07 e 09)

Rede → fusíveis e varistores → PS101 RECOM RAC20-05SK/277 (85–305 VAC, 5 V / 4 A) → `VIN_ACDC` → U901 BQ25895 (carregador chaveado com power path NVDC) → `VSYS` →
- U902 TPS63001 (buck-boost) → `+3V3` (MCU e lógica do lado seguro);
- U903 TPS61022 (boost) → `+5V` → F701 (PTC 2 A) → `+5V_HMI` (placa HMI, J701) e U606 ADuM6000 → domínio metrológico isolado.

- **Bateria:** J901 (JST PH de 3 vias): 1 = BAT+ (`VBAT`), 2 = NTC (`BAT_NTC`), 3 = BAT− (`GND_SYS`). Os polos são os terminais protegidos do pack (P+/P−), não a célula bruta.
- **NTC:** divisor do TS a partir do REGN, R901 = 5,23 kΩ (REGN-TS) e R903 = 30,1 kΩ (TS-GND), para NTC 103AT de 10 kΩ.
- **Limite de entrada:** R902 = 120 Ω no ILIM, ~3,0 A.
- **Detecção da fonte:** Q902 une D+/D− do BQ25895 só com o AC/DC presente (DCP, 3 A); só pelo USB-C a entrada fica em 500 mA. Q901 corta o VBUS quando o AC/DC está presente.
- **Medição:** `VBAT_SENSE` = VBAT/2 (R906/R907) para o ADC do MCU, além do ADC interno do BQ25895.
- **Liga/desliga:** SW901 desliga os conversores (PWR_EN).
- **Domínios:** bateria, carregador e HMI ficam no `GND_SYS`, o domínio seguro (o `GND_HMI` da proposta anterior). Nenhuma ligação direta com o GND metrológico, que é o neutro.

O sistema funciona sem bateria quando há rede (NVDC).

## Pendências

- **P1 — carga habilitada por hardware na partida:** hoje ~CE do BQ25895 está em GND, então o carregador começa com os valores padrão (ICHG 2,048 A, VREG 4,208 V) antes de o firmware configurar o pack. Proposta: ligar ~CE a um GPIO do MCU com pull-up, deixando a carga desabilitada até a configuração por I2C, com readback e watchdog.
- **P2 — corte físico de carga:** com EN baixo, o TPS61022 não desconecta a saída (o caminho indutor + diodo de corpo mantém `+5V` ≈ VSYS). Avaliar uma chave de carga em `+5V_HMI` se a HMI precisar ficar realmente desligada.
- **P2 — pack e NTC:** escolher pack, capacidade, conector (corrente nominal e polarização) e a curva real do NTC; conferir os limites do TS.
- **P2 — consumo real:** medir consumo e picos da HMI (tela e backlight) para fechar autonomia, corrente de carga e dimensionamento de conectores e trilhas.

## Candidatos avaliados

| Função | Implementado | Alternativa avaliada |
| --- | --- | --- |
| AC/DC | RECOM RAC20-05SK/277: 85–305 VAC, cobre 264 VAC (+20 %) | Hi-Link HLK-20M05: 85–265 VAC, margem pequena em 220 V +20 % |
| Carregador 1S | BQ25895RTW | — |
| Boost 5 V | TPS61022: chave de 8 A, compensação interna | TPS61088 |

## Partida e firmware

Configurar ICHG, VREG e VINDPM por I2C (sugestão: ICHG 1,0 A, VREG 4,20 V, VINDPM absoluto 4,2 V por causa da queda nos diodos D901/D902). Não substituir o NTC por resistor fixo. Implementar supervisão de bateria baixa, histerese e desligamento controlado antes do corte da proteção do pack. Testar a transição rede/bateria sem perda de aquisição, sem assumir.

## Exemplo de autonomia

A 10 W de carga, 3 V de bateria e 85 % de eficiência, a corrente é ~3,9 A antes de perdas e picos. Um pack 1S de 3 Ah a 3,7 V tem 11,1 Wh: ~0,94 h ideais a 10 W, antes de reserva, corte, envelhecimento e temperatura. Isto não fixa capacidade nem garante duração.

## Histórico

A proposta anterior (branch `minhas-alteracoes`) criava uma folha `10_Battery_Interface` só com os conectores do pack (J2) e do NTC (J3), sem carregador. Na versão implementada, a interface da bateria é o J901 da folha 09, já ligado ao BQ25895.

## Fontes oficiais

- [TI BQ25895, limites e registradores](https://www.ti.com/lit/ds/symlink/bq25895.pdf).
- [TI TPS61022](https://www.ti.com/lit/ds/symlink/tps61022.pdf).
- [RECOM RAC20-K](https://recom-power.com/pdf/Powerline_AC-DC/RAC20-K.pdf).
- [Hi-Link HLK-20M05](https://www.hlktech.net/index.php?id=125).
- [TI, caminho de descarga do boost com EN baixo](https://e2e.ti.com/support/power-management-group/power-management/f/power-management-forum/649719/tps61088-shut-down-problem).

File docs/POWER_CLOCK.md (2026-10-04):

# Fonte metrológica e clock do ADE9430

## Alimentação do domínio metrológico

Cadeia implementada (folhas 06 e 09):

`+5V` (domínio seguro, U903 TPS61022) → U606 ADuM6000 (DC/DC isolado isoPower, 5 kVrms) → `+5V_ISO` → U605 TPS7A2033PDBVR → `+3V3_ADE`

- U605 (SOT-23-5): 1 IN e 3 EN em `+5V_ISO`, 2 GND, 5 OUT em `+3V3_ADE`. Capacitores: C611 1 µF na entrada, C612 10 µF e C613 100 nF na saída. Desacoplamentos do ADE9430 (C401–C408) junto dos pinos.
- O TPS7A20 opera com entrada até 6 V e tem tolerância de saída de ±1,5 % (3,2505–3,3495 V), dentro dos 2,97–3,63 V do ADE9430.
- Consumo do domínio metrológico (ADE9430 + lado 2 dos isoladores + MCP3204) estimado abaixo de 100 mA; o ADuM6000 fornece até ~500 mW.
- Estimativa térmica do U605 (RθJA = 187,1 °C/W da placa de referência TI): a 5,25 V e 50 mA, ~97,5 mW e ΔT ~18 °C; a 100 mA, ~195 mW e ΔT ~36 °C. Recalcular com a corrente real e o gabinete.

O GND do domínio metrológico é o neutro (ver `VOLTAGE_SENSING.md`). Nenhum retorno da HMI ou do USB se liga a ele: toda comunicação passa por U601/U602 e a alimentação pelo U606.

## Cristal

Y401: Abracon ABM8-24.576MHZ-8-D1X-T, 3,2 × 2,5 mm, quatro pads (sinais 1/3, terras 2/4). Configuração da família Abracon: CL 8 pF, fundamental, ESR máx. 50 Ω, C0 máx. 3 pF, tolerância ±10 ppm, estabilidade ±20 ppm (−40/+85 °C), drive máx. 100 µW. Confirmar disponibilidade e land pattern antes da compra.

C409/C410: 10 pF C0G 1 % (decisão D-005). Hipótese: capacitância interna de 4 pF e parasita de 2 pF por pino, CL = (10 + 4 + 2)/2 = 8 pF. Ajustar se os parasitas medidos forem outros. Pelo manual da ADI, gmcrit ~0,577 mA/V com ESR 50 Ω e CL + C0 = 11 pF; com gm mínimo de 5 mA/V, margem ~8,7×. Isso não valida partida ou drive em bancada.

Tolerância + estabilidade somam 30 ppm; envelhecimento (±2 ppm) e erro de carga são adicionais. A calibração de frequência continua necessária conforme a precisão final.

## Reset

R401 10 kΩ de pull-up e C411 1 µF: constante de ~10 ms na partida. O MCU também pode reiniciar o ADE9430 pelo isolador U602 (RESET_DRV → R601 1 kΩ → RESET_ADE). Validar com as rampas reais da fonte.

## Histórico

Na versão anterior (branch `minhas-alteracoes`), o ADE9430 era alimentado por 5 V externo num conector de protótipo (J1) com o mesmo regulador TPS7A2033. A versão implementada alimenta o domínio metrológico pelo ADuM6000 a partir do lado seguro.

## Fontes oficiais

- [TI TPS7A20 Rev. H, seções 4, 5 e 6](https://www.ti.com/lit/ds/symlink/tps7a20.pdf): pinagem DBV, capacitores, limites e térmica.
- [ADE9430 Rev. 0, tabela 1](https://www.analog.com/media/en/technical-documentation/data-sheets/ade9430.pdf): alimentação, consumo e clock.
- [Manual ADI, Crystal Selection e Load Capacitor Calculation](https://wiki.analog.com/resources/eval/user-guides/ade9430).
- [Abracon ABM8, especificações e part numbering](https://abracon.com/Resonators/abm8.pdf).

Nenhuma simulação ou medição física foi executada.

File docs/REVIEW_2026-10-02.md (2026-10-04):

# Revisão independente — 2026-10-02

> **Histórico.** Esta revisão se refere à versão anterior do esquemático (branch `minhas-alteracoes`, antes do PR #1), com U1/Y1 e divisores de 330 kΩ. O esquemático atual da `main` foi revisado em `REVISAO_ESQUEMATICO.md`. A decisão sobre o cristal (D-005) foi incorporada à `main`.

Dois agentes trabalharam somente em leitura: um revisou hardware e cálculos; outro classificou o ERC. O coordenador integrou a correção e repetiu ERC e netlist no KiCad 10.0.3. Não houve revisão do PCB, simulação ou ensaio de bancada.

## Correção integrada

P1: os pads GND 2/4 do cristal Y1 estavam desconectados por inversão vertical no símbolo. Corrigida a geometria na biblioteca local e na cópia incorporada. A netlist XML confirma ambos em GND e os seis sinais de tensão ligados a U1. O ERC passou de 147 (18 erros, 129 avisos) para 142 (13 erros, 129 avisos): eliminados uma etiqueta solta, dois pinos desconectados e dois erros de alimentação associados a Y1.

## ERC restante

| Tipo | Erros | Avisos | Ação |
| --- | --- | --- | --- |
| pin_not_driven | 11 | 0 | Implementar oito entradas de corrente e três entradas SPI do MCU |
| power_pin_not_driven | 2 | 0 | Implementar/verificar fonte real de 3V3 e GND; não inserir flags para esconder ausência de fonte |
| endpoint_off_grid | 0 | 72 | Normalizar grade sem alterar conectividade; passo 1,905 mm no ADE exige revisão |
| footprint_link_issues | 0 | 35 | Resolver configuração das bibliotecas padrão e conferir footprints antes do layout |
| isolated_pin_label | 0 | 21 | Completar interfaces de corrente, MCU e conectores de tensão; decidir saídas opcionais |
| multiple_net_names | 0 | 1 | VN_SENSE e GND são a mesma rede por decisão documentada; padronizar nomenclatura |

Os avisos de bibliotecas vieram da configuração do ambiente de validação e não demonstram, por si só, ausência dos arquivos na instalação. Quatro checks constam como ignorados no relatório: etiqueta global única, junção de quatro pontos, modelo SPICE e filtros de footprint. Folhas vazias sem violações não são blocos concluídos.

## Achados ainda abertos

- P1: alimentação, MCU/SPI, correntes, conectores, proteção e isolação ainda incompletos; bloqueiam liberação do instrumento.
- P2: Y1 precisa de fabricante/modelo, tolerância, ESR e capacitância de carga. C9/C10 de 18 pF dependem do cristal e dos parasitas; não aprovados nesta revisão.
- P2: reset RC de 10 kΩ/1 µF tem constante nominal de 10 ms; validar partida com rampas da fonte e reinicialização pelo MCU.
- P2: fechar MPN dos resistores de alta tensão e qualificações de pulso, tensão e derating antes da BOM final.

## Conferências positivas

Pinagem ADE9430 1–41 conferida contra tabela 6 do datasheet. Divisor 1/991, saída ideal a 264 V de 266,40 mV RMS / 376,75 mV pico, corte nominal de 7,24 kHz e dissipação aproximada de 23,4 mW por resistor de 330 kΩ conferidos. Não representam precisão medida ou aprovação para energização.

Fonte técnica: [ADE9430 datasheet Rev. 0, tabelas 1 e 6](https://www.analog.com/media/en/technical-documentation/data-sheets/ade9430.pdf).

Próxima tarefa: definir fonte metrológica e cristal exato; depois implementar MCU/SPI e dimensionar TCs/burden. Não avançar ao layout com estas pendências de conexão.

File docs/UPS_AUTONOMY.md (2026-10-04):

# Dimensionamento UPS anterior — substituído

A meta de 13 horas e a proposta LiFePO4 4S 20 Ah foram retiradas pelo usuário. Não usar estes números para BOM, compra, gabinete ou validação. O requisito atual é bateria LiPo plana interna leve, com autonomia a definir. Ver [INTERNAL_BATTERY.md](INTERNAL_BATTERY.md) e REQ-011.

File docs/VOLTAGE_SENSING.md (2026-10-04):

# Entradas de tensão — dimensionamento

Implementadas na folha `02_Voltage_Sensing.kicad_sch`: três canais fase-neutro para sistemas 3P4W de 127/220 V e 220/380 V, 60 Hz. As etiquetas VAP/VAN, VBP/VBN e VCP/VCN ligam os divisores aos canais de tensão do ADE9430 (U401).

## Dimensionamento

Por fase:
- fusível (F201–F203) e varistor (RV201–RV203) na entrada, folha 02;
- cadeia de cinco resistores de 200 kΩ, 0,1 %, 1206 (R2k1–R2k5), e resistor inferior de 1 kΩ, 0,1 % (R2k6). Razão ideal 1/1001;
- capacitor de 22 nF C0G (C2k1) na entrada positiva; a entrada negativa recebe 1 kΩ (R2k7) e 22 nF (C2k2) para casar impedância e fase;
- ganho do PGA de tensão: 1.

A cadeia de cinco resistores divide a tensão de trabalho e aumenta a distância de escoamento ao longo do divisor no layout (ver `LAYOUT.md`). A resistência de Thévenin vista pela entrada é ~999 Ω, o que dá corte nominal de ~7,24 kHz com 22 nF. A impedância do ADC, as tolerâncias e os parasitas exigem calibração de ganho e fase.

| Tensão fase-neutro | Saída ideal RMS | Pico senoidal ideal |
| --- | --- | --- |
| 127 V | 126,9 mV | 179,4 mV |
| 220 V | 219,8 mV | 310,8 mV |
| 242 V (+10 %) | 241,8 mV | 341,9 mV |
| 264 V (+20 %) | 263,7 mV | 373,0 mV |

O datasheet especifica ±0,6 V por pino e ±1 V diferencial com ganho 1. Os cálculos consideram senoide e não qualificam o circuito para transientes. Em 264 V, cada resistor de 200 kΩ dissipa ~13,9 mW e fica com ~52,7 V RMS (~74,6 V de pico). Especificação: 1206, ≥ 0,25 W, tensão de trabalho ≥ 200 V, TC ≤ 25 ppm/K. Confirmar tensão de pulso e derating no datasheet do resistor escolhido antes de fechar a BOM.

## Referência e pendências

O neutro liga ao GND metrológico por R201 (0 Ω), montado em 3F+N e 1F+N: todo o domínio do ADE9430 fica referenciado à rede. Em rede de três fios sem neutro, R201 não é montado e o GND assume o neutro artificial formado pelos divisores; essa topologia ainda precisa de validação. O valor 380 V é fase-fase no sistema 220/380 V, não a tensão destas entradas.

Antes de energizar: conferir categoria de medição, proteção de surtos, classificação dos componentes e as distâncias no PCB (regras em `Smart-Metering.kicad_dru`).

## Histórico

A versão anterior desta folha (branch `minhas-alteracoes`, 02/10) usava três resistores de 330 kΩ por fase (razão 1/991). A versão implementada usa 5 × 200 kΩ + 1 kΩ, com o mesmo filtro de 7,2 kHz.

## Fontes

- [ADE9430 — datasheet Rev. 0, tabela 1](https://www.analog.com/media/en/technical-documentation/data-sheets/ade9430.pdf).
- [Manual técnico — configuração analógica, filtros e exemplo de calibração](https://wiki.analog.com/resources/eval/user-guides/ade9430).

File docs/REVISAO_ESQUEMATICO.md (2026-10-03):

# Revisão do esquemático — rev. 0.1

Data: 2026-10-03. Escopo: as 9 folhas de `hardware/Smart-Metering/` (placa de metrologia).

## 1. Método

O KiCad não está disponível no ambiente onde a revisão foi feita, então o ERC do KiCad **ainda precisa ser rodado**. No lugar dele:

1. **Netlist global** montado diretamente dos arquivos `.kicad_sch` (215 componentes, 680 pinos, 176 nets), com labels globais entre folhas e labels locais por folha.
2. **Verificações automáticas**: pinos sem ligação, nets de alimentação sem fonte, saídas em conflito, entradas sem acionamento, domínios de terra (isolação) e footprints inexistentes.
3. **Conferência com a biblioteca oficial do KiCad** (símbolos e footprints, gitlab.com/kicad/libraries).
4. **Revisão de engenharia** folha por folha: faixas, valores, orçamento de potência e segurança.

## 2. Resultado das verificações automáticas (após correções)

| Verificação | Resultado |
|---|---|
| Pinos sem ligação e sem flag de não conectado | nenhum |
| Nets de alimentação sem fonte (ERC "power input not driven") | nenhuma (PWR_FLAG adicionados) |
| Nets com mais de uma saída | nenhuma (MISO do ADE9430 marcado como tri-state) |
| Entradas sem acionamento | nenhuma |
| Isolação: componentes que unem terras diferentes | só as barreiras previstas: PS101, PS601, U601, U602, U801 |
| Footprints inexistentes na biblioteca oficial | nenhum |
| Referências duplicadas | nenhuma |

Domínios de terra encontrados:

- `GND` + `HV_RTN`: domínio metrológico e entrada de energia, no potencial da rede;
- `GND_SYS`: domínio seguro;
- `GND_485`: barramento RS-485 isolado.

## 3. Correções feitas nesta revisão

| # | Folha | Problema | Correção |
|---|---|---|---|
| 1 | 04 | Footprint do ADE9430 (`LFCSP-40-1EP_6x6mm…EP4.5x4.5mm`) **não existe** na biblioteca KiCad | Trocado por `QFN-40-1EP_6x6mm_P0.5mm_EP4.6x4.6mm` (ver pendência P1) |
| 2 | 04/06 | MISO do ADE9430 e Dout do MCP3204 no mesmo net, ambos como saída (conflito no ERC) | Pino MISO do símbolo ADE9430 passa a tri-state |
| 3 | 01 | Símbolo genérico do AC/DC com AC/L e AC/N trocados em relação ao IRM-10-5 real | Símbolo e footprint oficiais `Converter_ACDC:IRM-10-5` |
| 4 | 01, 05, 08, 09 | Seis nets de alimentação sem fonte declarada (HV_DC, HV_RTN, VBAT_RTC, VDDA, GND_485, VIN_CHG) | PWR_FLAG em cada uma |
| 5 | 01, 02 | Fusíveis e varistores sem footprint | Porta-fusível 5×20 mm (fusíveis cerâmicos de 500 VAC) e varistor de disco 15,5 mm |
| 6 | 09 | Indutores sem footprint | L901 Bourns SRN4018 (2,2 µH), L902 Bourns SRP7028A (2,2 µH, Isat alto) |
| 7 | 09 | SW901 sem footprint | Chave no painel, ligada por conector JST PH de 2 vias |
| 8 | 08 | RS-485 sem polarização de fail-safe | R807/R808 (680 Ω, não montados por padrão) |
| 9 | 01 | Retorno do AC/DC (ruído de comutação) compartilha o neutro com o GND metrológico | Nota de layout: HV_RTN em trilha própria até o borne |
| 10 | 08 | Detecção de VBUS do STM32 espera 5 V em PA9, mas o divisor entrega 3,3 V | Nota de firmware: desabilitar VBUS sensing do OTG e ler PA9 como GPIO |

Antes desta revisão, já tinham sido corrigidos ao trocar símbolos desenhados de memória pelos oficiais:

- BQ24074, pino 15: era ITERM, não SYSOFF; agora tem R911;
- ISO774x, TPS63021 e TPS61023 substituídos por equivalentes com símbolo oficial.

## 4. Revisão de engenharia por folha

### 01 — Entrada de energia
- OU de diodos: o instrumento segue alimentado com qualquer fase presente. ✔
- R101 (22 Ω): energia de partida em C101 ≈ V²C/2R = 0,012 A²s, abaixo do I²t de um fusível T250mA. ✔
- **Risco — tensão máxima do IRM-10-5:** em CC ele aceita até 370 V. Uma elevação de 20 % sobre 220 V (264 V) dá 373 V de pico no barramento, no limite. Ver P5.

### 02 — Tensão
- Divisor de 1/1001: 220 V dá 0,311 V de pico no pino. O limite de projeto de 0,5 V de pico permite medir até cerca de 354 Vrms. ✔
- Cinco resistores 1206 em série: cada um vê no máximo cerca de 100 V de pico na faixa de medição, abaixo dos 200 V nominais. ✔
- Filtro anti-aliasing: 999 Ω com 22 nF, corte em 7,2 kHz, igual ao dos canais de corrente. ✔

### 03 — Corrente
- Ra // Rb ≈ 1 kΩ nas três opções de sensor, então o filtro fica em 7,2 kHz em todas. ✔
- SCT-013 de 1 V: o divisor 2k49/1k65 atenua por 0,40, deixando folga de 1,8× sobre a corrente nominal. ✔
- Os contatos de J301–J304 ficam no potencial da rede, então o conector precisa ser à prova de toque. Ver P3.

### 04 — ADE9430
- PM0/PM1 em GND (modo normal) e PULL_HIGH em +3V3_ADE. ✔
- IRQ0/IRQ1 e CFx têm pull-ups na folha 06. ✔
- Ver P1 e P2.

### 05 — MCU
- O STM32F413 tem SPI1, timers, USART2/3 e USB FS nos pinos atribuídos.
- Para o USB, o HSE de 8 MHz permite gerar 48 MHz pelo PLL.
- RTC com LSE de 32,768 kHz e CR2032 direto no pino VBAT (faixa de 1,65 a 3,6 V). ✔
- Calibração: sem EEPROM externa, os coeficientes ficam na flash interna. Ver P9.

### 06 — Isolação
- ISO7762 + ISO7761 reforçados de 5 kVrms. Sem alimentação, as saídas ficam em nível alto: SS desativado e RESET solto. ✔
- TPS7A2033 (300 mA) para menos de 100 mA de carga. ✔
- Ver P4 (PS601).

### 07 — Interface HMI
- +5V protegido por PTC de 2 A; linhas de sinal com 33 Ω. ✔
- Ver P8: a placa ESP32-P4-Function-EV-Board precisa aceitar 5 V pelo conector.

### 08 — Comunicações
- ADM2587E: alimentação isolada interna (Visoout → Visoin), DE e ~RE unidos. ✔
- USB-C com CC de 5,1 kΩ: recebe só 5 V, sem negociação PD. ✔

### 09 — Alimentação
- **Orçamento de potência:**

  | Item | Potência |
  |---|---|
  | Placa HMI com LCD | ~3,5 W em +5V |
  | PS601 | ~0,4 W |
  | +3V3 (MCU, isoladores, ADM2587E) | ~0,9 W |
  | **Total em VSYS** | **~5,2 W ≈ 1,16 A a 4,5 V** |

  O BQ24074 limita a entrada em 1,48 A, então sobram só cerca de 0,3 A para carregar a bateria: uma carga completa leva mais de 8 h com a tela ligada. Em picos de consumo a bateria complementa a entrada. **Não é falha de segurança, mas limita o uso portátil.** Ver P6.
- **Dissipação do BQ24074:** cerca de (4,55 − 3,7) V × 0,89 A ≈ 0,8 W no VQFN-16. Precisa de vias térmicas no pad.
- **Margem do TPS61089:** com entrada de 4,55 V e saída de 5,04 V, a margem é pequena, mas o conversor ainda trabalha como boost. ✔
- Ver P7 (valores do TPS61089).

## 5. Pendências — situação

| # | Item | Situação |
|---|---|---|
| P1 | Pad exposto do ADE9430 | **Resolvida por projeto:** footprint com EP de 4,15 mm (Texas RHA0040B VQFN-40 6×6), compatível com as variantes CP-40 de 6×6 mm da ADI (EP de 3,9 a 4,7 mm). Ainda vale confirmar a variante no datasheet antes de pedir a PCB. |
| P2 | MISO do ADE9430 e NC1/NC2 | **Resolvida:** com SS alto, o ADE9430 para de acionar o MISO e liga um pull-up fraco de 100 kΩ, então compartilhar com o MCP3204 é seguro. O datasheet recomenda NC1/NC2 em GND, como já está. |
| P3 | Conector dos sensores de corrente | **Resolvida:** J301–J304 são headers internos JST PH de 4 vias, cabeados até conectores M8 fêmea de 4 vias no painel (IEC 61076-2-104, contatos à prova de toque). |
| P4 | DC/DC isolado do domínio metrológico | **Resolvida:** U606 ADuM6000 (isoPower, 5 kVrms, até 500 mW; símbolo oficial). Os módulos 5 V → 5 V da biblioteca têm só 1–3 kVDC. Confirmar no datasheet a certificação reforçada e a tensão de trabalho. |
| P5 | Faixa de entrada do AC/DC | **Resolvida:** PS101 = RECOM RAC20-05SK/277 (85–305 VAC / 120–430 VDC, 20 W). 264 VAC (+20 %) dá 373 Vpk, dentro do limite. Fusíveis T500mA, R101 de 3 W e C101 de 10 µF/450 V. Confirmar com a RECOM que a /277 usa o mesmo encapsulamento. |
| P6 | Carregador | **Resolvida** (BQ25895, seção 6). Com o RAC20, o limite de entrada subiu para 3 A (R902 = 120 Ω). |
| P7 | Valores do TPS61089 | **Resolvida:** substituído pelo TPS61022 (chave de 8 A, compensação interna). Só usa divisor de realimentação (732k/100k → 5,0 V), indutor de 1 µH e capacitores. |
| P8 | Alimentar a placa EV pela interface | **Resolvida:** o J1 da ESP32-P4-Function-EV-Board tem 5 V nos pinos 2 e 4, previstos para embarcar a placa num sistema maior. Alimentar por eles com o USB-C da placa EV desconectado. O mapeamento J701 → J1 segue o esquema da placa EV. |
| P9 | EEPROM de calibração | **Resolvida:** U502 24LC64 (0x50) no I2C1, junto com o BQ25895 (0x6A). |
| P10 | ERC e labels globais | **Parcial:** labels globais usados numa só folha viraram locais (0 restantes). O ERC do KiCad ainda precisa ser rodado. |

## 6. Alterações após a revisão

### Carregador: BQ24074 → BQ25895 (resolve P6)

| | Antes (BQ24074) | Depois (BQ25895) |
|---|---|---|
| Tipo | linear | chaveado, 1,5 MHz, power path NVDC |
| Limite de entrada | 1,48 A | ≈ 3,0 A (R902 = 120 Ω; RAC20-05SK/277 fornece 4 A) |
| Carga com a tela ligada | ~0,3 A (> 8 h para 2500 mAh) | ~0,85 A (~3 h) |
| Dissipação no CI | ~0,8 W | baixa (conversão chaveada) |
| Configuração | resistores | registradores via I2C (MCU PB6/PB7) |
| Telemetria | ~PGOOD, ~CHG | ~INT, STAT e ADC interno (VBUS, VBAT, VSYS, ICHG) |

Detalhes:

- **Detecção de carregador:** D+ e D− do BQ25895 unidos (CHG_DPDM), para ele se reconhecer ligado a um carregador dedicado (DCP) e não ficar limitado em 500 mA.
- **Sensor de temperatura:** divisor do NTC (R901 30,1 kΩ / R903 5,23 kΩ, a partir de REGN) para um NTC de 10 kΩ. Conferir com a tabela do datasheet.
- **Componentes externos:** L903 2,2 µH, C914 bootstrap 47 nF, REGN 4,7 µF, PMID 10 µF, SYS 2 × 10 µF, BAT 10 µF.
- **Diodos de entrada:** D901/D902 trocados para SS54 em SMC, de 5 A, para a corrente maior.
- **ERC:** PWR_FLAG em VSYS, porque o pino SYS do símbolo oficial é passivo.
- **Firmware:** na inicialização, configurar por I2C:
  - corrente de carga (sugestão: 1,0 A);
  - tensão de fim de carga (4,20 V);
  - VINDPM absoluto em cerca de 4,2 V, por causa da queda nos diodos de entrada.

  Também ler ~INT para eventos de entrada e bateria.
- **Folha 05:** PC2 passa a receber CHG_INT_N, e PB6/PB7 viram I2C1.

Alternativa não adotada: usar o boost OTG do BQ25895 para gerar o +5V e eliminar o TPS61089. Isso exige que o MCU troque de modo quando a rede cai, o que deixa a HMI sem alimentação por alguns milissegundos.

### Resolução das pendências P1–P10

- 01: PS101 → RAC20-05SK/277; F101–F104 T500mA; R101 22 Ω 3 W; C101 10 µF/450 V.
- 03: J301–J304 com footprint JST PH 4 vias (cabo até o M8 do painel).
- 04: footprint do ADE9430 com EP de 4,15 mm; AVDDOUT, DVDDOUT, REF_ADE, XIN_ADE e XOUT_ADE como labels locais.
- 05: U502 24LC64 + C515.
- 06: PS601 → U606 ADuM6000 (RC_SEL em VDD1, RC_IN em GND1, V_SEL em V_ISO) com desacoplamento.
- 09: U903 TPS61089 → TPS61022 (L902 de 1 µH, 3 × 22 µF na saída); R902 = 120 Ω (entrada de 3 A).
- Projeto: 223 componentes; todas as verificações automáticas sem erro; todos os footprints existem na biblioteca oficial.

## 7. Correções da revisão do PR #1

| Ponto | Problema | Correção |
|---|---|---|
| Divisor do TS (U901) | R901 (REGN-TS) e R903 (TS-GND) estavam trocados: com o NTC de 10 kΩ, TS ficava em ~10 % de REGN e o BQ25895 suspendia a carga por sobretemperatura | R901 = 5,23 kΩ (REGN-TS) e R903 = 30,1 kΩ (TS-GND, em paralelo com o NTC), como na aplicação típica: TS ≈ 59 % de REGN a 25 °C |
| Detecção da fonte pelo BQ25895 | D+/D- unidos sempre: qualquer fonte virava DCP (3 A), inclusive uma porta USB de PC (500/900 mA) | Q902 (2N7002) une D+/D- só com VIN_ACDC presente. Só pelo USB-C: D+/D- soltos, detecção SDP/desconhecida, 500 mA |
| OU de diodos AC/DC + USB | Com as duas fontes, a de maior tensão supria a placa, podendo ser a porta USB | Q901 (AO3401A) corta o VBUS quando VIN_ACDC está presente (R912 = 100 kΩ mantém Q901 ligado e Q902 desligado sem o AC/DC) |
| Regras do DRC | Divisores sem regra entre fases nem contra o domínio metrológico; barramento HV só com clearance; creepage da barreira 6,4 mm contra os 8 mm documentados | Classes DIVIDER_A/B/C, regras 3,0 mm entre fases e 2,0 mm contra o domínio metrológico, HVBUS com clearance e creepage, creepage da barreira 8,0 mm (ver `docs/LAYOUT.md`) |
| Projeto KiCad | `top_level_sheets` apontava para `creepage.kicad_sch` (resto do modelo) | Aponta para `Smart-Metering.kicad_sch` |

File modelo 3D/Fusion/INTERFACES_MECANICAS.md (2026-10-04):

# Smart Metering — interfaces mecânicas

Versão de referência: montagens/20261003_173930_283634.
Arquivo principal: SmartMeter_Interfaces_Mecanicas.f3d.

## Resultado verificado no Autodesk Fusion

11 componentes, 12 corpos com volume positivo. Os 55 pares de componentes foram analisados pela API de interferência do Fusion e apresentaram volume de sobreposição zero. Contatos entre faces são permitidos. O relatório completo está em interferencias.json na pasta versionada. Esta verificação geométrica não comprova resistência, isolamento elétrico ou adequação à fabricação.

## Alterações

- Bandeja: quatro furos de 3,2 mm e apoios correspondentes no gabinete, com alojamentos de insertos de 4,6 mm.
- Três suportes separados: metrologia, HMI e comunicação. Furações de fixação compatíveis com a bandeja; comunicação sobre apoios da HMI.
- Moldura: abertura de 202 × 127 mm e fixação correspondente no painel frontal e gabinete.
- Pés: posicionados sob o gabinete, com furos correspondentes na parede inferior.
- Grade: posicionada sobre o gabinete, com abertura e furações correspondentes na parede superior.

Os suportes são adaptadores mecânicos provisórios, não modelos das placas eletrônicas reais. A distância livre entre a base da HMI e o suporte de comunicação é de 9 mm; depende das alturas dos componentes e conectores. As folgas laterais entre suportes e divisória são geométricas, não distâncias de isolamento elétrico certificadas.

## Arquivos e edição

A pasta oficial é `modelo 3D/Fusion` (relativa à raiz do repositório).
O gerador da montagem é SmartMeterAssembly/SmartMeterAssembly.py; suas dimensões ficam em geometry_interfaces.json e as posições em mounting.json, na mesma subpasta. Executar esse script no Fusion cria um novo documento e exporta uma nova pasta versionada em montagens. Alterações manuais no F3D não retornam automaticamente ao gerador.

geometry.json preserva a geometria de origem; geometry_fit.json preserva a revisão anterior. Os arquivos originais do GitHub e suas exportações continuam separados desta variante.

## Pendências para fechar os encaixes

Selecionar os modelos e obter desenhos dimensionais da tela, das placas e da bateria interna leve. Verificar conectores, cabos, alturas e acesso aos parafusos. Definir material, tolerâncias de impressão, parafusos, insertos e espessura do painel de instalação antes de fabricar. Os diâmetros atuais dos alojamentos são provisórios e devem seguir o fabricante dos insertos escolhidos.

## Ordem preliminar de montagem

Com o gabinete aberto pela frente, instalar fixações dos pés e da grade que precisem de acesso interno. Fixar a bandeja nos quatro apoios; instalar suporte de metrologia, suporte HMI e, depois, suporte de comunicação. Instalar a tela e seu suporte após definir o módulo real. Fechar o painel frontal e montar a moldura. Confirmar o acesso às ferramentas e aos cabos com os componentes reais antes de liberar a fabricação.

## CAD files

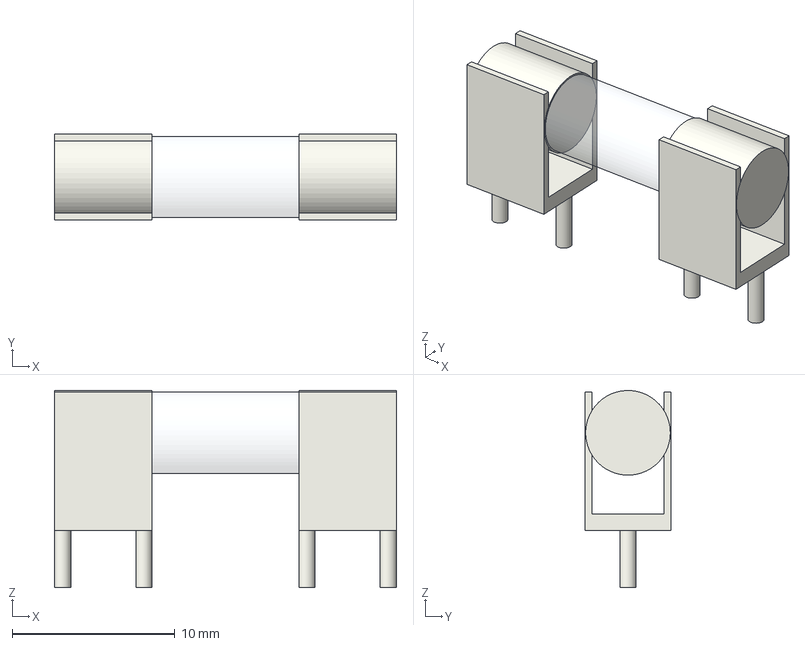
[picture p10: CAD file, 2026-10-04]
hardware/Smart-Metering/3d/Fuseholder_Littelfuse_111_5x20.step
21.0 x 5.30 x 12.1 mm
clipe-0.5
pino0.0
pino5.0
clipe14.5
pino15.0
pino20.0
vidro
tampa1
tampa2

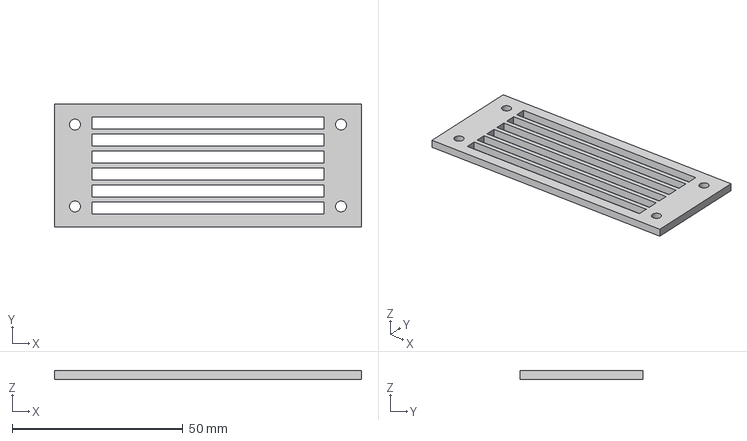
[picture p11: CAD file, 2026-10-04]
modelo 3D/Fusion/exportados/20261003_144653_400378/SmartMeter_VentilationGrille.step
90.0 x 36.0 x 2.50 mm

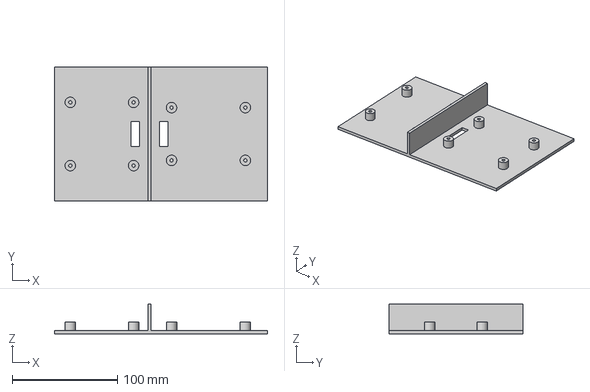
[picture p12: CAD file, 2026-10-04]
modelo 3D/Fusion/historico/exportacao_inicial_20261003_144724/SmartMeter_InternalTray.step
202.0 x 127.0 x 28.0 mm

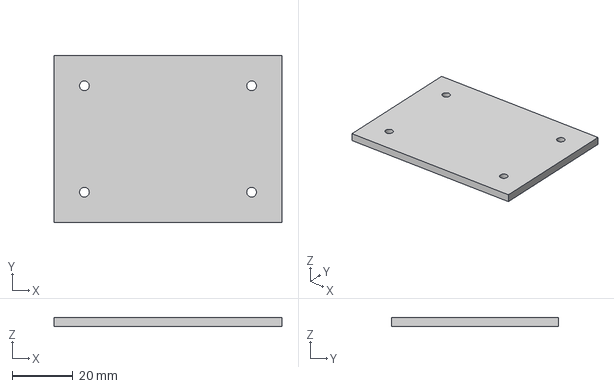
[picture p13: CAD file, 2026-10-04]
modelo 3D/Fusion/montagens/20261003_151619_561311/SmartMeter_CommCarrier.step
75.0 x 55.0 x 3.00 mm

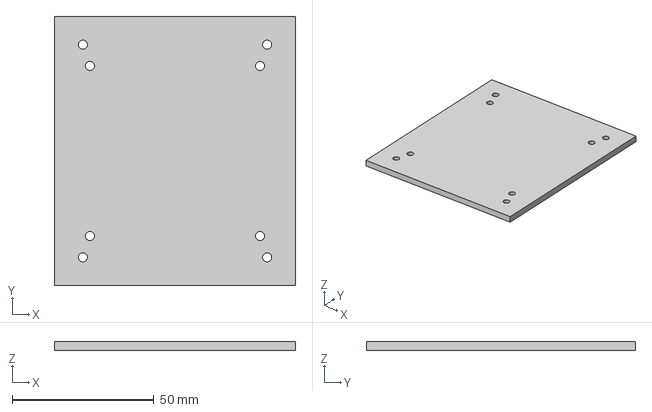
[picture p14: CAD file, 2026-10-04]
modelo 3D/Fusion/montagens/20261003_173930_283634/SmartMeter_MetrologyCarrier.step
85.0 x 95.0 x 3.00 mm

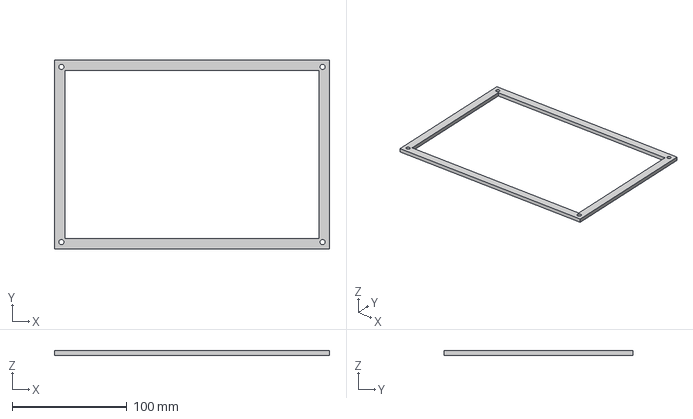
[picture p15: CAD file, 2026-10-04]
modelo 3D/Fusion/SmartMeter_PanelMountFrame.step
240.0 x 165.0 x 4.00 mm

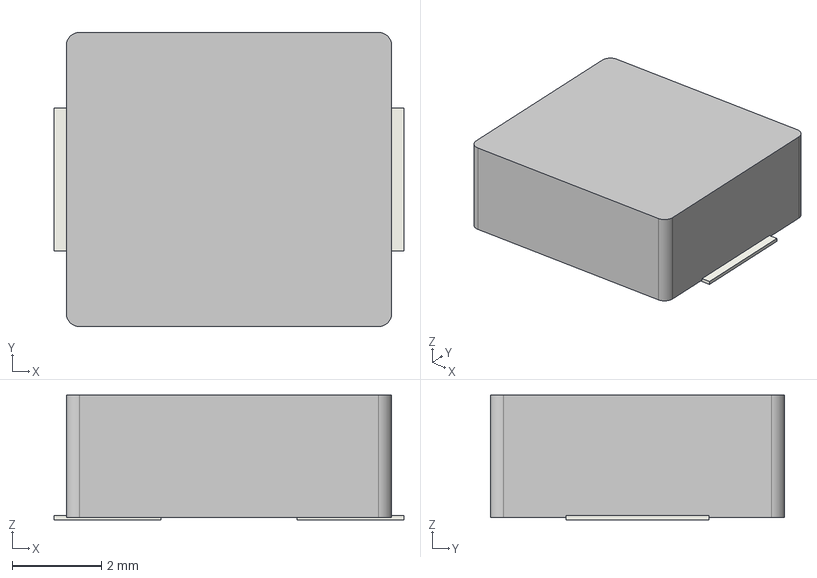
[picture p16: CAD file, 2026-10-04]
hardware/Smart-Metering/3d/Bourns_SRP7028A_7.3x6.6mm.step
7.85 x 6.60 x 2.80 mm
corpo
term-2.725
term2.725

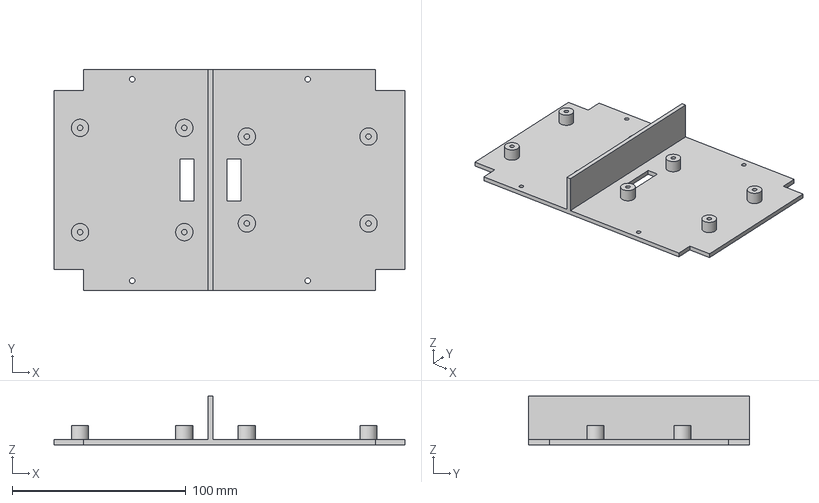
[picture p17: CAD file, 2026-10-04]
modelo 3D/Fusion/montagens/20261003_151619_561311/SmartMeter_InternalTray.step
202.0 x 127.0 x 28.0 mm

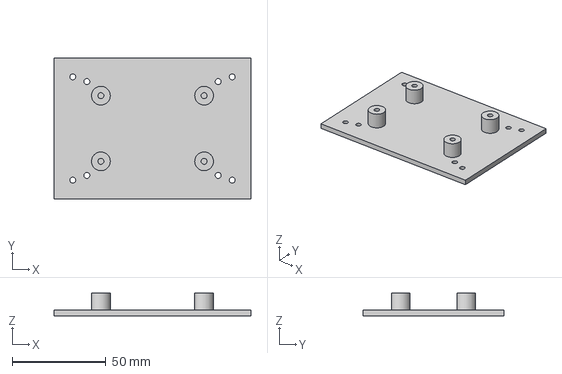
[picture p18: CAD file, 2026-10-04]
modelo 3D/Fusion/montagens/20261003_173930_283634/SmartMeter_HmiCarrier.step
105.0 x 75.0 x 12.0 mm

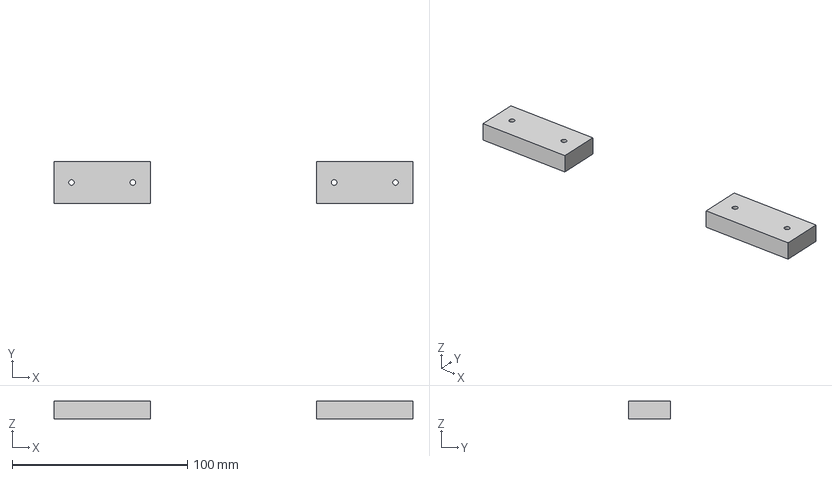
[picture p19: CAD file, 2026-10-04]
modelo 3D/Fusion/SmartMeter_DesktopFeet.step
205.0 x 24.0 x 10.0 mm

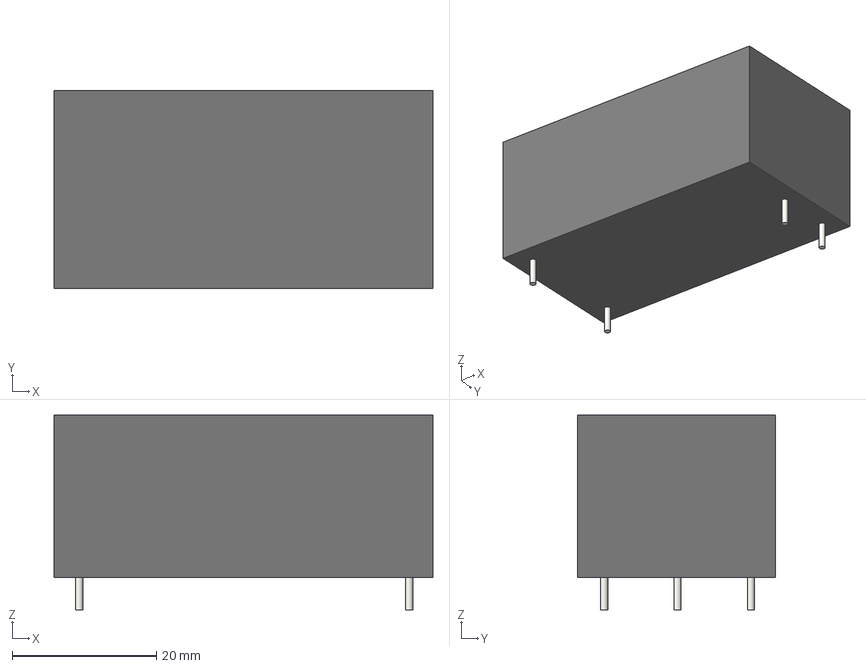
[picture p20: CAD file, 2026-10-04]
hardware/Smart-Metering/3d/Recom_RAC20-xxSK_THT.step
52.5 x 27.4 x 27.0 mm
corpo
pino0
pino1
pino2
pino3

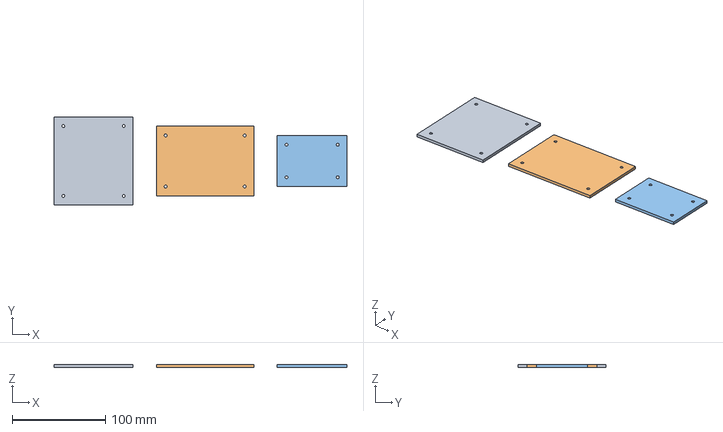
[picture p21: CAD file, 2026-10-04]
modelo 3D/Fusion/exportados/20261003_144653_400378/SmartMeter_PCBSupports.step
315.0 x 95.0 x 3.00 mm

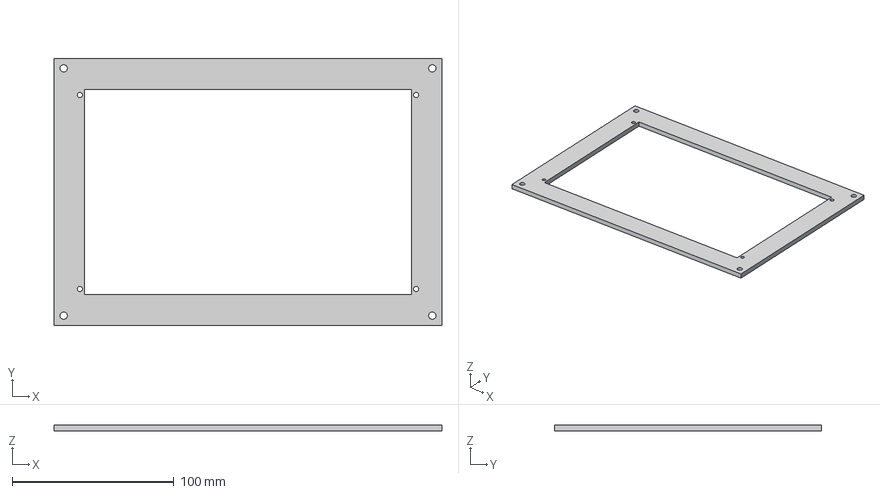
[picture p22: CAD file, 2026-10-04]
modelo 3D/Fusion/montagens/20261003_173930_283634/SmartMeter_PanelMountFrame.step
240.0 x 165.0 x 4.00 mm

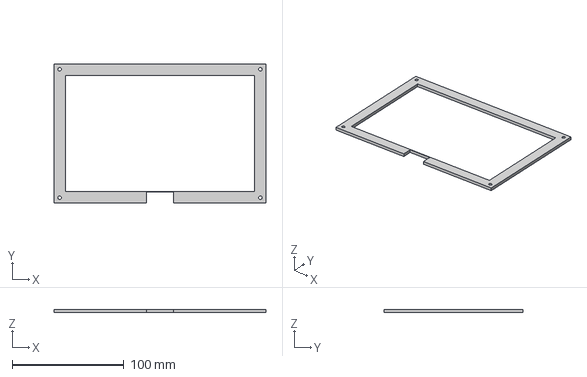
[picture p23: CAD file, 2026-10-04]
modelo 3D/Fusion/SmartMeter_DisplayBracket.step
190.0 x 125.0 x 3.00 mm

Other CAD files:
modelo 3D/Fusion/exportados/20261003_144653_400378/SmartMeter_InternalTray.step
modelo 3D/Fusion/historico/exportacao_inicial_20261003_144724/SmartMeter_VentilationGrille.step
modelo 3D/Fusion/historico/exportacao_inicial_20261003_144724/SmartMeter_PCBSupports.step
modelo 3D/Fusion/montagens/20261003_151619_561311/SmartMeter_HmiCarrier.step
hardware/Smart-Metering/3d/Texas_RWU0007A_VQFN-7_2x2mm.step
modelo 3D/Fusion/SmartMeter_FrontPanel.step
modelo 3D/Fusion/SmartMeter_Github.f3d
modelo 3D/Fusion/SmartMeter_Interfaces_Mecanicas.f3d
modelo 3D/Fusion/SmartMeter_InternalTray.step
modelo 3D/Fusion/SmartMeter_Montagem_Revisada.f3d
modelo 3D/Fusion/SmartMeter_RearHousing.step
modelo 3D/Fusion/SmartMeter_RearPanel.step
modelo 3D/Fusion/exportados/20261003_144653_400378/SmartMeter_FrontPanel.step
modelo 3D/Fusion/exportados/20261003_144653_400378/SmartMeter_Github.f3d
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

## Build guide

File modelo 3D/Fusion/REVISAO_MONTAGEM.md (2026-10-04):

# Revisão da montagem — resultado verificado

Pasta oficial: `modelo 3D/Fusion` (relativa à raiz do repositório).

## Versões

- Originais: nove FeatureScripts em Onshape e geometry.json. O gerador Fusion preserva sua geometria padrão.
- Montagem original diagnosticada: montagens/20261003_144344_814599; o Fusion confirmou interferências de 743,0495 mm³ entre carcaça e suporte da tela, e 942,4778 mm³ entre carcaça e bandeja.
- Variante revisada: montagens/20261003_144531_822532. Pilares recuados em 3 mm, alojamentos de insertos iniciando em Z3, quatro alívios de canto 17×12 mm na base da bandeja. Folga nominal mínima dos pilares à bandeja: 1 mm.

## Verificação

Todos os sólidos finais com volume positivo e posições registradas. Análise nativa do Fusion dos dez pares das cinco peças principais: zero interpenetração volumétrica na variante. Revisão independente confirmou coerência das dimensões e do relatório. Contatos coincidentes foram excluídos da análise.

## Correção do gerador

Cortes agora usam somente participantBodies do próprio componente. Uniões usam corpos e alvo explicitamente do próprio componente. A primeira versão afetava peças alheias e gerou exportações inválidas; as exportações antigas e os relatórios sem diagnóstico não devem ser usados para fabricação.

## Pendências

Não há montagem aprovada para fabricação. Fixação da bandeja, padrões dos suportes de PCB, retenção da moldura de painel, interfaces dos pés/grade, dimensões reais da eletrônica, display e bateria, tolerâncias e folgas elétricas continuam pendentes. Os quatro acessórios são mostrados ao lado, sem posição final definida.

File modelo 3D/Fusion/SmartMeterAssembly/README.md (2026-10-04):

# Gerador de montagem Smart Metering

Pasta oficial: `modelo 3D/Fusion/SmartMeterAssembly`.

Execute SmartMeterAssembly.py pelo painel Scripts e complementos do Autodesk Fusion. A versão atual lê geometry_interfaces.json e mounting.json, gera 11 componentes e exporta F3D, 11 arquivos STEP e interferencias.json para uma nova pasta montagens. O arquivo SmartMeter_Interfaces_Mecanicas.f3d contém a montagem; SmartMeter_Vista_Interna.f3d permite inspecionar os suportes.

A exportação verificada em 20261003_173930_283634 contém 12 sólidos válidos e 55 verificações sem sobreposição volumétrica. Leia ../INTERFACES_MECANICAS.md para as alterações e pendências.

geometry.json mantém a referência original e geometry_fit.json mantém a revisão anterior. Alterações manuais no F3D não são sincronizadas com os arquivos de parâmetros. Tela, placas e bateria reais ainda precisam de modelos e dimensões definidos.

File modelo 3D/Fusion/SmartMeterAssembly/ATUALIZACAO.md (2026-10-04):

Verificador atualizado para Design.analyzeInterference. O relatório anterior que declarou todas as peças sem interferência é inconclusivo: contradiz as dimensões das peças. O novo verificador marca contradições e falhas como não verificadas. Sintaxe verificada; execução da API pendente.

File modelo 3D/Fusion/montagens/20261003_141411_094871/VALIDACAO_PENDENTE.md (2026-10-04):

# Validação pendente
O relatório interferencias.json desta execução usou a primeira versão do verificador e não deve ser considerado aprovação de encaixe. Sua classificação sem sobreposição contradiz a revisão dimensional. O script oficial SmartMeterAssembly foi atualizado para a análise nativa do Fusion. É necessária nova execução para produzir um relatório válido; os modelos existentes foram preservados.

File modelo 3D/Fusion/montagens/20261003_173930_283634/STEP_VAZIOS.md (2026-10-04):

# STEP vazios nesta exportação

`SmartMeter_FrontPanel.step` e `SmartMeter_RearHousing.step` desta pasta (e de `20261003_151619_561311`) não têm sólido: o script ocultava essas duas peças para a vista interna antes de exportar os STEP.

O `SmartMeterAssembly.py` agora exporta todos os STEP antes de ocultar as peças. Rode o script de novo no Fusion para gerar uma exportação completa. Até lá, a geometria isolada das duas peças está nos STEP da raiz de `modelo 3D/Fusion/`.

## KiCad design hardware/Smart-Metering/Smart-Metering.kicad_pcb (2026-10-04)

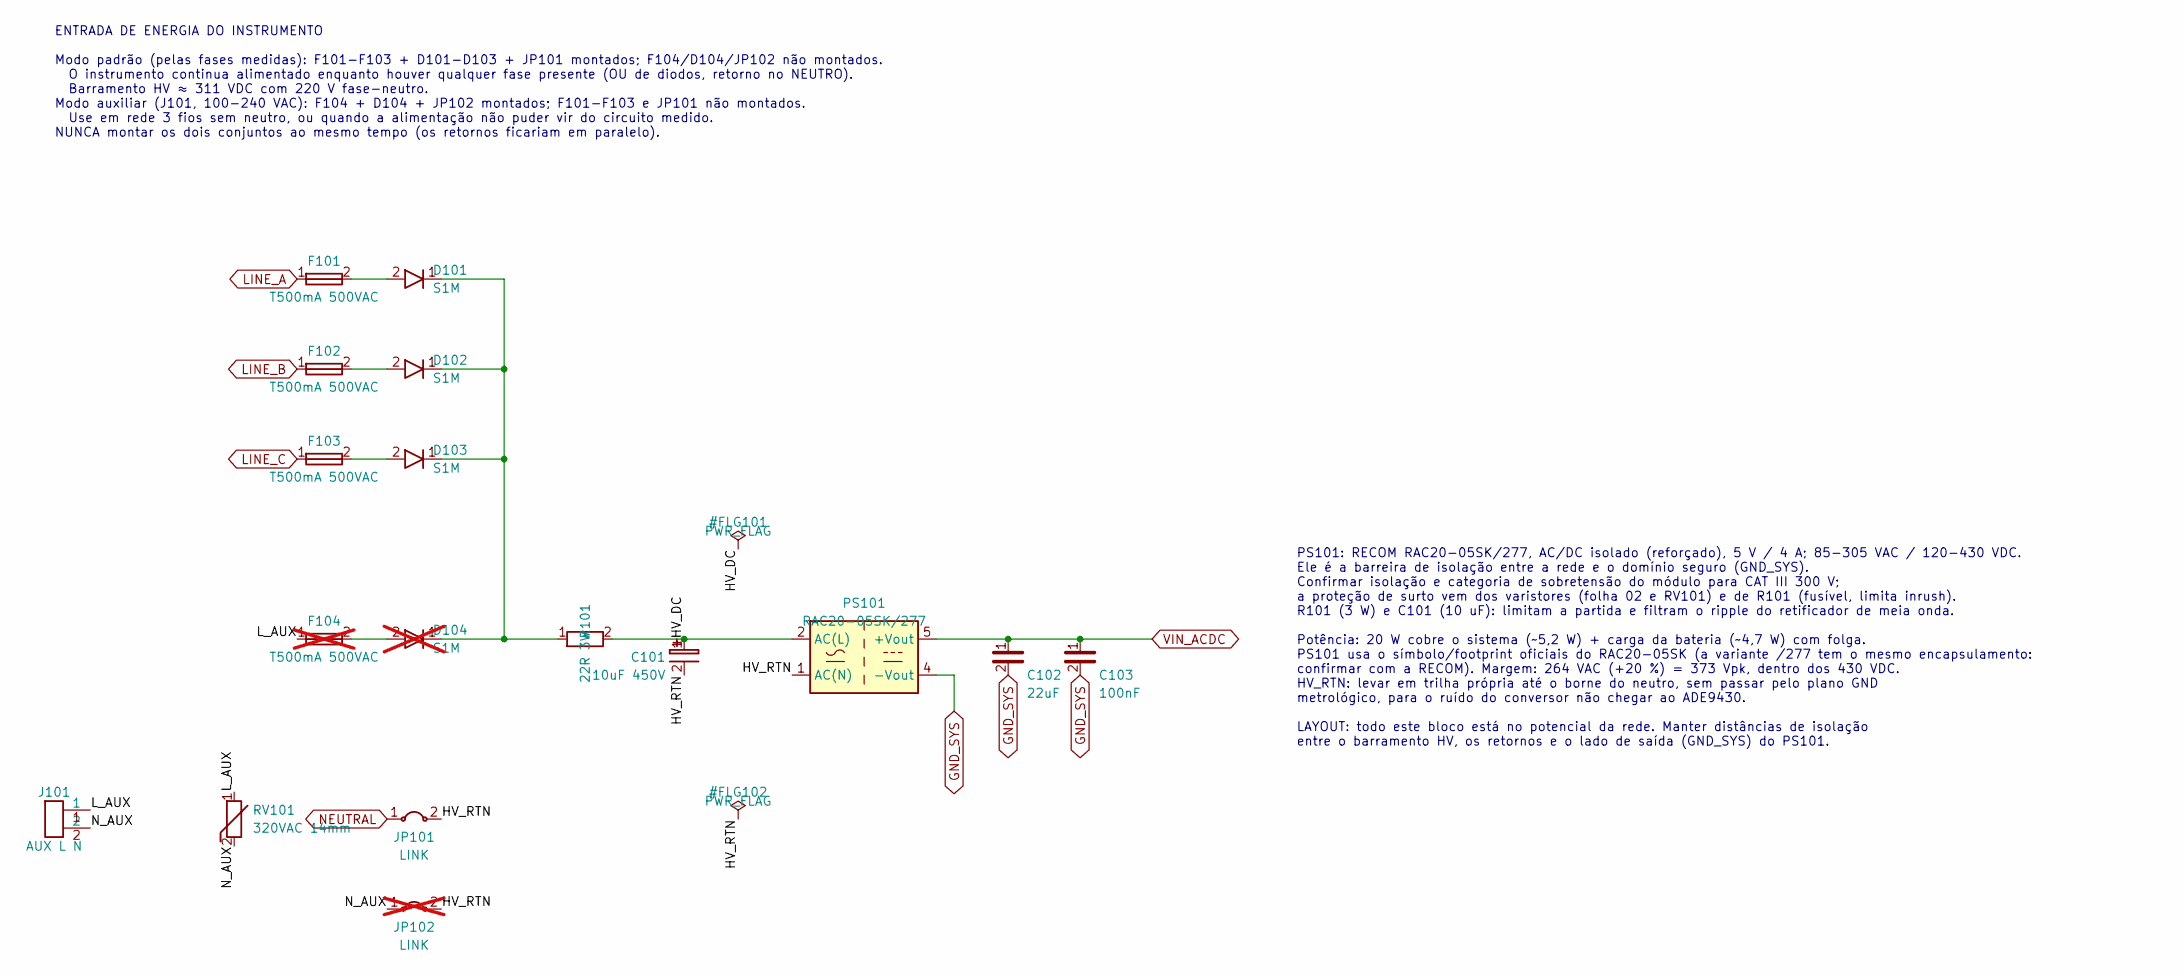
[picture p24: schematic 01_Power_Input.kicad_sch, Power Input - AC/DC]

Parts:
C101: 10uF 450V; CP_Radial_D10.0mm_P5.00mm
C102: 22uF; C_1206_3216Metric
C103: 100nF; C_0603_1608Metric
D101, D102, D103: S1M; D_SMA
D104: S1M; D_SMA; not fitted
F101, F102, F103: T500mA 500VAC; Fuseholder_Clip-5x20mm_Littelfuse_111_Inline_P20.00x5.00mm_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
F104: T500mA 500VAC; Fuseholder_Clip-5x20mm_Littelfuse_111_Inline_P20.00x5.00mm_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; not fitted
J101: AUX L N; TerminalBlock_Phoenix_MKDS-1,5-2-5.08_1x02_P5.08mm_Horizont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
JP101: LINK; R_Axial_DIN0207_L6.3mm_D2.5mm_P7.62mm_Horizontal
JP102: LINK; R_Axial_DIN0207_L6.3mm_D2.5mm_P7.62mm_Horizontal; not fitted
PS101: RAC20-05SK/277; Converter_ACDC_Recom_RAC20-xxSK_THT
R101: 22R 3W; R_Axial_DIN0617_L17.0mm_D6.0mm_P20.32mm_Horizontal
RV101: 320VAC 14mm; RV_Disc_D15.5mm_W4.5mm_P7.5mm

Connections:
/Power Input/HV_DC: C101.1 (+), PS101.2 (AC(L)), R101.2
/Power Input/HV_RTN: C101.2 (-), JP101.2, JP102.2, PS101.1 (AC(N))
/Power Input/L_AUX: F104.1, J101.1, RV101.1
/Power Input/N_AUX: J101.2, JP102.1, RV101.2
GND_SYS: C102.2, C103.2, PS101.4 (-Vout); also elsewhere on the board
LINE_A: F101.1; also elsewhere on the board
LINE_B: F102.1; also elsewhere on the board
LINE_C: F103.1; also elsewhere on the board
NEUTRAL: JP101.1; also elsewhere on the board
unnamed: D101.1 (K), D102.1 (K), D103.1 (K), D104.1 (K), R101.1
unnamed: D101.2 (A), F101.2
unnamed: D102.2 (A), F102.2
unnamed: D103.2 (A), F103.2
unnamed: D104.2 (A), F104.2
VIN_ACDC: C102.1, C103.1, PS101.5 (+Vout); also elsewhere on the board

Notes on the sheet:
ENTRADA DE ENERGIA DO INSTRUMENTO Modo padrão (pelas fases medidas): F101-F103 + D101-D103 + JP101 montados; F104/D104/JP102 não montados. O instrumento continua alimentado enquanto houver qualquer fase presente (OU de diodos, retorno no NEUTRO). Barramento HV ≈ 311 VDC com 220 V fase-neutro. Modo 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
PS101: RECOM RAC20-05SK/277, AC/DC isolado (reforçado), 5 V / 4 A; 85-305 VAC / 120-430 VDC. Ele é a barreira de isolação entre a rede e o domínio seguro (GND_SYS). Confirmar isolação e categoria de sobretensão do módulo para CAT III 300 V; a proteção de surto vem dos varistores (folha 02 e RV101) 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

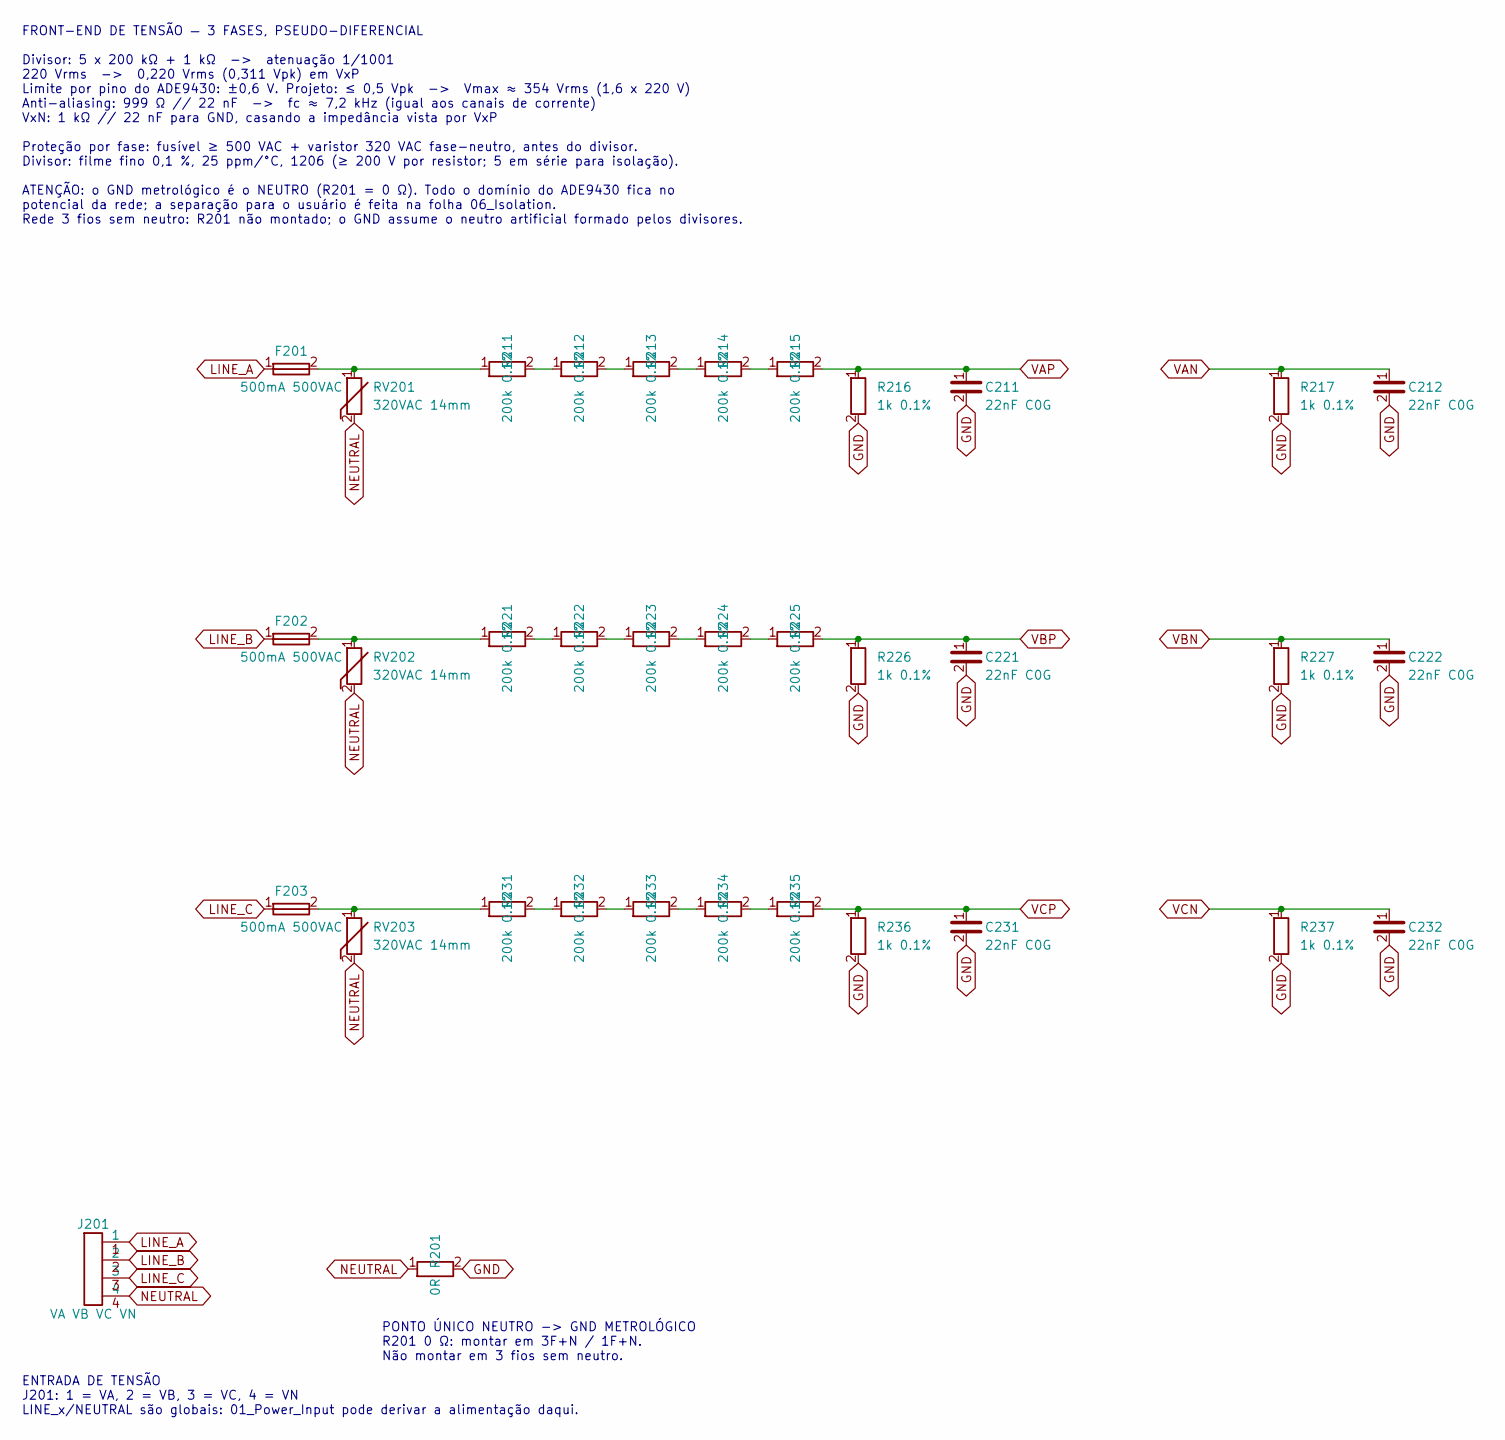
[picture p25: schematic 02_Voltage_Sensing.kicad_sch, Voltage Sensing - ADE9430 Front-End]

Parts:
C211, C212, C221, C222, C231, C232: 22nF C0G; C_0603_1608Metric
F201, F202, F203: 500mA 500VAC; Fuseholder_Clip-5x20mm_Littelfuse_111_Inline_P20.00x5.00mm_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
J201: VA VB VC VN; TerminalBlock_Phoenix_MKDS-1,5-4-5.08_1x04_P5.08mm_Horizont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
R201: 0R; R_1206_3216Metric
R211, R212, R213, R214, R215, R221, R222, R223, R224, R225, R231, R232, R233, R234, R235: 200k 0.1%; R_1206_3216Metric
R216, R217, R226, R227, R236, R237: 1k 0.1%; R_0603_1608Metric
RV201, RV202, RV203: 320VAC 14mm; RV_Disc_D15.5mm_W4.5mm_P7.5mm

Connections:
GND: C211.2, C212.2, C221.2, C222.2, C231.2, C232.2, R201.2, R216.2, R217.2, R226.2, R227.2, R236.2, R237.2; also elsewhere on the board
LINE_A: F201.1, J201.1; also elsewhere on the board
LINE_B: F202.1, J201.2; also elsewhere on the board
LINE_C: F203.1, J201.3; also elsewhere on the board
NEUTRAL: J201.4, R201.1, RV201.2, RV202.2, RV203.2; also elsewhere on the board
unnamed: F201.2, R211.1, RV201.1
unnamed: F202.2, R221.1, RV202.1
unnamed: F203.2, R231.1, RV203.1
unnamed: R211.2, R212.1
unnamed: R212.2, R213.1
unnamed: R213.2, R214.1
unnamed: R214.2, R215.1
unnamed: R221.2, R222.1
unnamed: R222.2, R223.1
unnamed: R223.2, R224.1
unnamed: R224.2, R225.1
unnamed: R231.2, R232.1
unnamed: R232.2, R233.1
unnamed: R233.2, R234.1
unnamed: R234.2, R235.1
VAN: C212.1, R217.1; also elsewhere on the board
VAP: C211.1, R215.2, R216.1; also elsewhere on the board
VBN: C222.1, R227.1; also elsewhere on the board
VBP: C221.1, R225.2, R226.1; also elsewhere on the board
VCN: C232.1, R237.1; also elsewhere on the board
VCP: C231.1, R235.2, R236.1; also elsewhere on the board

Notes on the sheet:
FRONT-END DE TENSÃO — 3 FASES, PSEUDO-DIFERENCIAL Divisor: 5 x 200 kΩ + 1 kΩ -> atenuação 1/1001 220 Vrms -> 0,220 Vrms (0,311 Vpk) em VxP Limite por pino do ADE9430: ±0,6 V. Projeto: ≤ 0,5 Vpk -> Vmax ≈ 354 Vrms (1,6 x 220 V) Anti-aliasing: 999 Ω // 22 nF -> fc ≈ 7,2 kHz (igual aos canais de corre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
ENTRADA DE TENSÃO J201: 1 = VA, 2 = VB, 3 = VC, 4 = VN LINE_x/NEUTRAL são globais: 01_Power_Input pode derivar a alimentação daqui.
PONTO ÚNICO NEUTRO -> GND METROLÓGICO R201 0 Ω: montar em 3F+N / 1F+N. Não montar em 3 fios sem neutro.

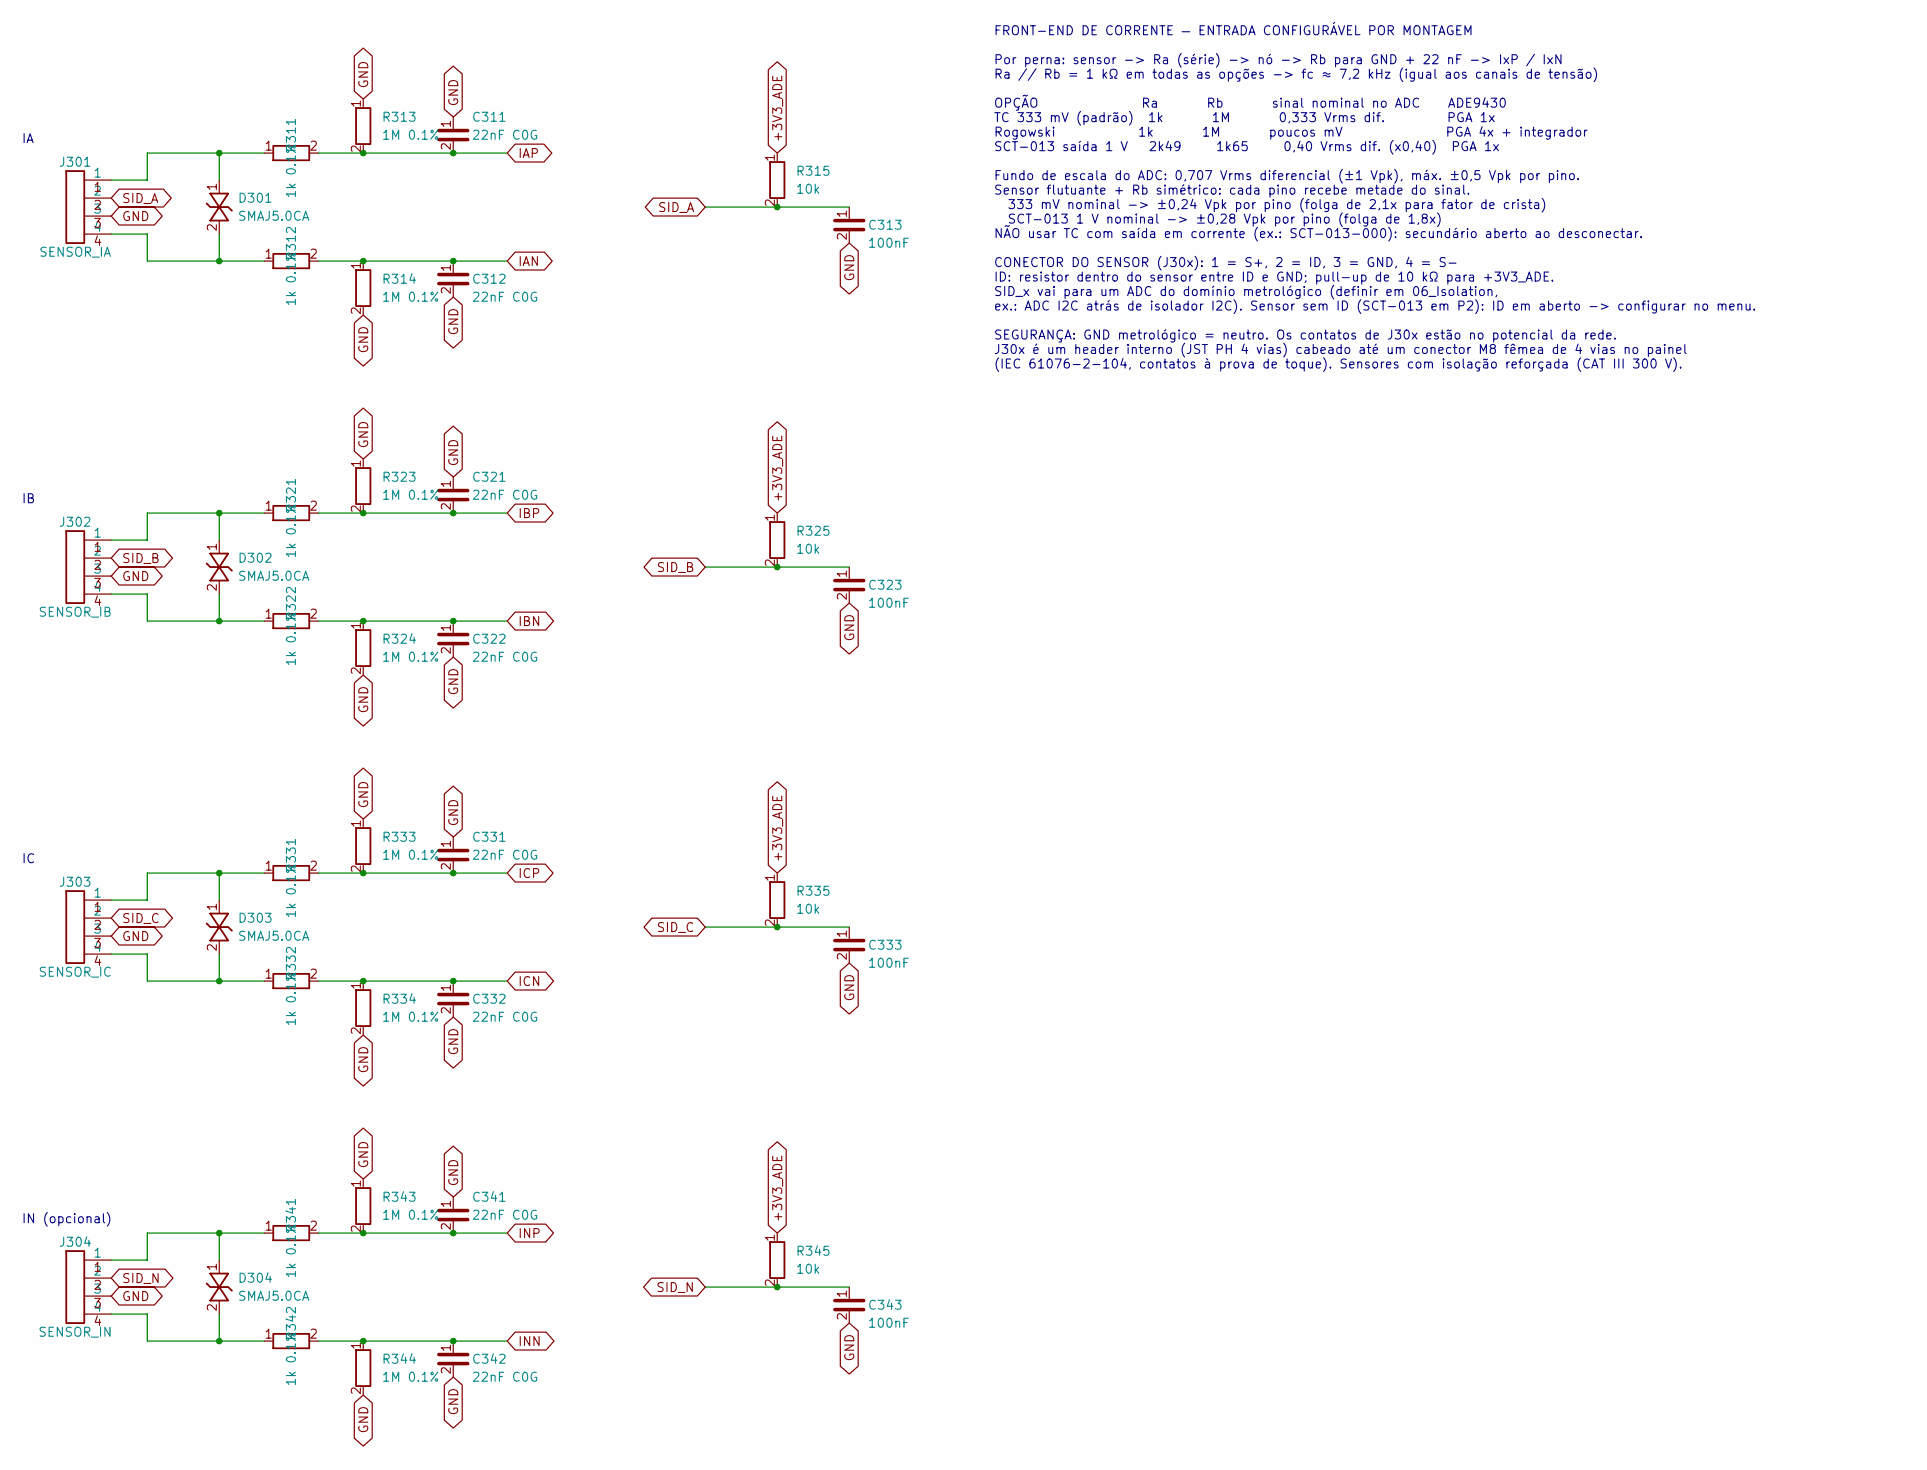
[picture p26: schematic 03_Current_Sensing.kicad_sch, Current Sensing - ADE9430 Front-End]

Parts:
C311, C312, C321, C322, C331, C332, C341, C342: 22nF C0G; C_0603_1608Metric
C313, C323, C333, C343: 100nF; C_0603_1608Metric
D301, D302, D303, D304: SMAJ5.0CA; D_SMA
J301: SENSOR_IA; JST_PH_B4B-PH-K_1x04_P2.00mm_Vertical
J302: SENSOR_IB; JST_PH_B4B-PH-K_1x04_P2.00mm_Vertical
J303: SENSOR_IC; JST_PH_B4B-PH-K_1x04_P2.00mm_Vertical
J304: SENSOR_IN; JST_PH_B4B-PH-K_1x04_P2.00mm_Vertical
R311, R312, R321, R322, R331, R332, R341, R342: 1k 0.1%; R_0603_1608Metric
R313, R314, R323, R324, R333, R334, R343, R344: 1M 0.1%; R_0603_1608Metric
R315, R325, R335, R345: 10k; R_0603_1608Metric

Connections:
+3V3_ADE: R315.1, R325.1, R335.1, R345.1; also elsewhere on the board
GND: C311.1, C312.2, C313.2, C321.1, C322.2, C323.2, C331.1, C332.2, C333.2, C341.1, C342.2, C343.2, J301.3, J302.3, J303.3, J304.3, R313.1, R314.2, R323.1, R324.2, R333.1, R334.2, R343.1, R344.2; also elsewhere on the board
IAN: C312.1, R312.2, R314.1; also elsewhere on the board
IAP: C311.2, R311.2, R313.2; also elsewhere on the board
IBN: C322.1, R322.2, R324.1; also elsewhere on the board
IBP: C321.2, R321.2, R323.2; also elsewhere on the board
ICN: C332.1, R332.2, R334.1; also elsewhere on the board
ICP: C331.2, R331.2, R333.2; also elsewhere on the board
INN: C342.1, R342.2, R344.1; also elsewhere on the board
INP: C341.2, R341.2, R343.2; also elsewhere on the board
unnamed: D301.1, J301.1, R311.1
unnamed: D301.2, J301.4, R312.1
unnamed: D302.1, J302.1, R321.1
unnamed: D302.2, J302.4, R322.1
unnamed: D303.1, J303.1, R331.1
unnamed: D303.2, J303.4, R332.1
unnamed: D304.1, J304.1, R341.1
unnamed: D304.2, J304.4, R342.1
SID_A: C313.1, J301.2, R315.2; also elsewhere on the board
SID_B: C323.1, J302.2, R325.2; also elsewhere on the board
SID_C: C333.1, J303.2, R335.2; also elsewhere on the board
SID_N: C343.1, J304.2, R345.2; also elsewhere on the board

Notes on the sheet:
FRONT-END DE CORRENTE — ENTRADA CONFIGURÁVEL POR MONTAGEM Por perna: sensor -> Ra (série) -> nó -> Rb para GND + 22 nF -> IxP / IxN Ra // Rb = 1 kΩ em todas as opções -> fc ≈ 7,2 kHz (igual aos canais de tensão) OPÇÃO Ra Rb sinal nominal no ADC ADE9430 TC 333 mV (padrão) 1k 1M 0,333 Vrms dif. PGA 1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
IN (opcional)

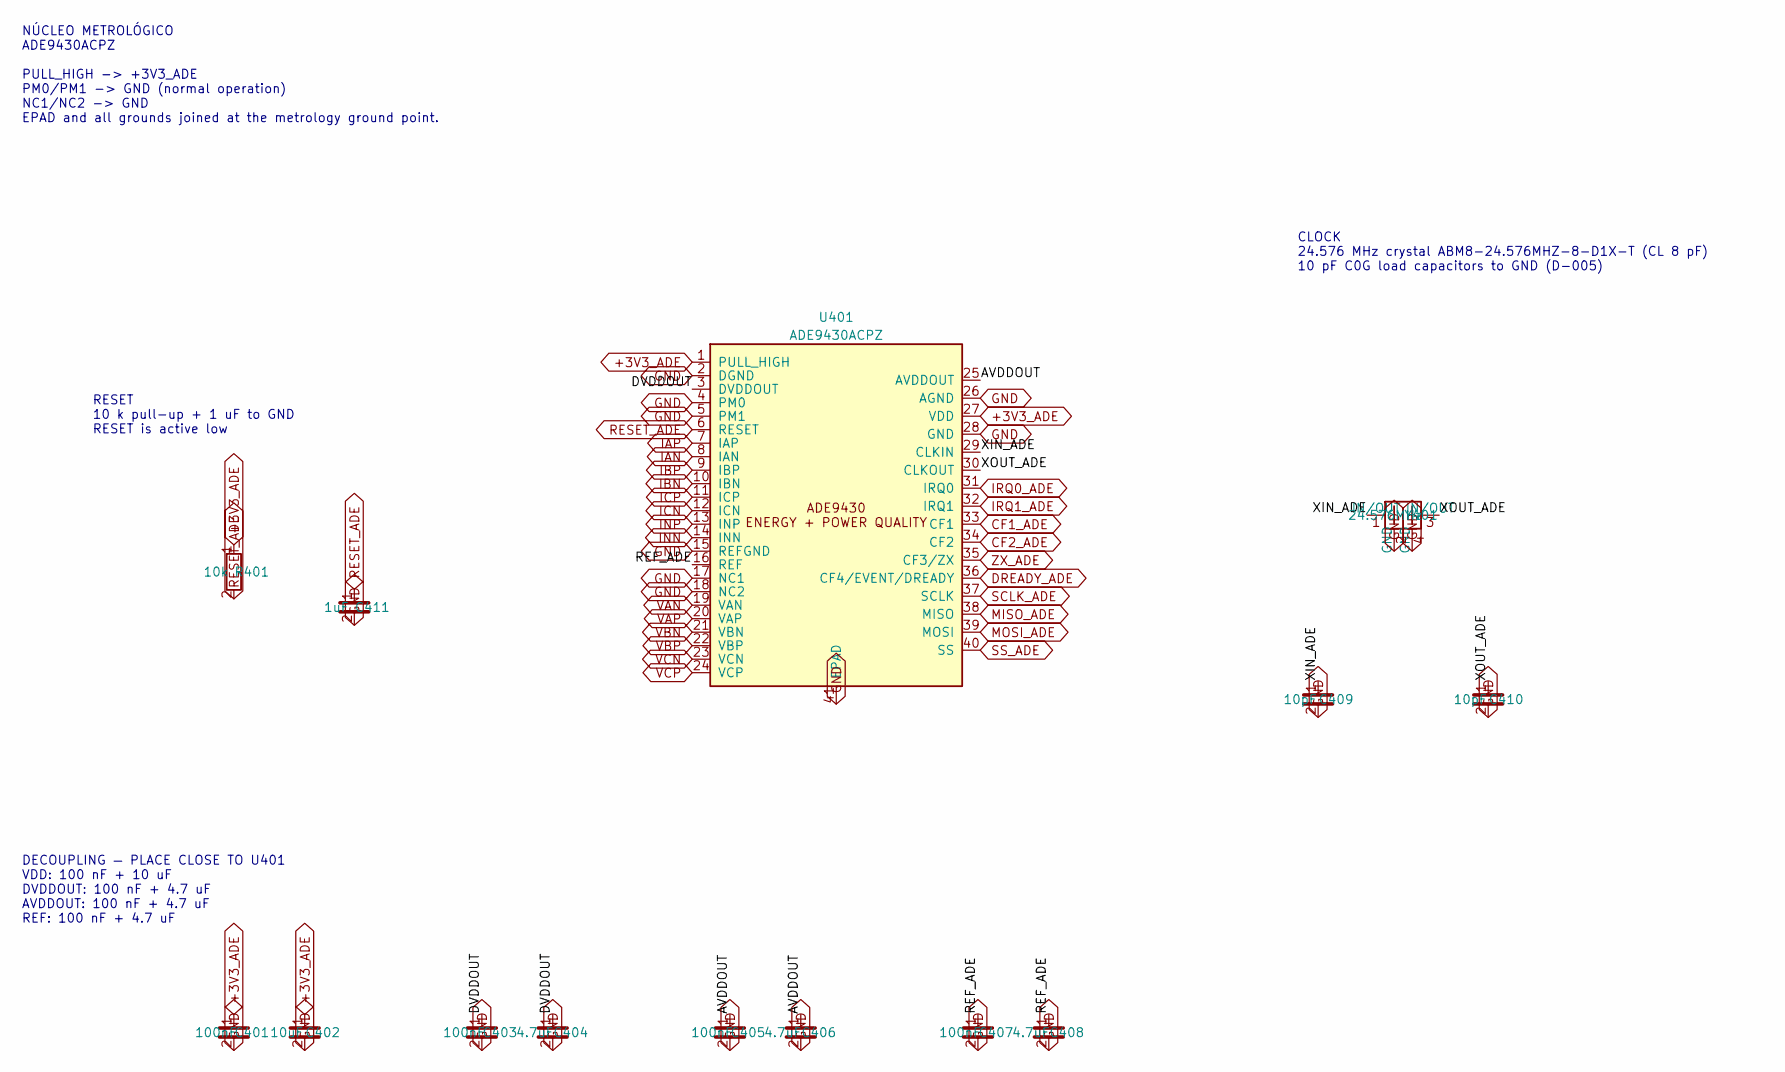
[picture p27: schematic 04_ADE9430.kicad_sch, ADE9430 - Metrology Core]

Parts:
C401, C403, C405, C407: 100nF; C_0603_1608Metric
C402: 10uF; C_0805_2012Metric
C404, C406, C408: 4.7uF; C_0805_2012Metric
C409, C410: 10pF; C_0603_1608Metric
C411: 1uF; C_0603_1608Metric
R401: 10k; R_0603_1608Metric
U401: ADE9430ACPZ; Texas_RHA0040B_VQFN-40-1EP_6x6mm_P0.5mm_EP4.15x4.15mm
Y401: 24.576MHz; Crystal_SMD_3225-4Pin_3.2x2.5mm

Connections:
+3V3_ADE: C401.1, C402.1, R401.1, U401.1 (PULL_HIGH), U401.27 (VDD); also elsewhere on the board
/ADE9430/AVDDOUT: C405.1, C406.1, U401.25 (AVDDOUT)
/ADE9430/DVDDOUT: C403.1, C404.1, U401.3 (DVDDOUT)
/ADE9430/REF_ADE: C407.1, C408.1, U401.16 (REF)
/ADE9430/XIN_ADE: C409.1, U401.29 (CLKIN), Y401.1 (IN/OUT)
/ADE9430/XOUT_ADE: C410.1, U401.30 (CLKOUT), Y401.3 (IN/OUT)
CF1_ADE: U401.33 (CF1); also elsewhere on the board
CF2_ADE: U401.34 (CF2); also elsewhere on the board
DREADY_ADE: U401.36 (CF4/EVENT/DREADY); also elsewhere on the board
GND: C401.2, C402.2, C403.2, C404.2, C405.2, C406.2, C407.2, C408.2, C409.2, C410.2, C411.2, U401.2 (DGND), U401.4 (PM0), U401.5 (PM1), U401.15 (REFGND), U401.17 (NC1), U401.18 (NC2), U401.26 (AGND), U401.28 (GND), U401.41 (EPAD), Y401.2 (GND), Y401.4 (GND); also elsewhere on the board
IAN: U401.8 (IAN); also elsewhere on the board
IAP: U401.7 (IAP); also elsewhere on the board
IBN: U401.10 (IBN); also elsewhere on the board
IBP: U401.9 (IBP); also elsewhere on the board
ICN: U401.12 (ICN); also elsewhere on the board
ICP: U401.11 (ICP); also elsewhere on the board
INN: U401.14 (INN); also elsewhere on the board
INP: U401.13 (INP); also elsewhere on the board
IRQ0_ADE: U401.31 (IRQ0); also elsewhere on the board
IRQ1_ADE: U401.32 (IRQ1); also elsewhere on the board
MISO_ADE: U401.38 (MISO); also elsewhere on the board
MOSI_ADE: U401.39 (MOSI); also elsewhere on the board
RESET_ADE: C411.1, R401.2, U401.6 (RESET); also elsewhere on the board
SCLK_ADE: U401.37 (SCLK); also elsewhere on the board
SS_ADE: U401.40 (SS); also elsewhere on the board
VAN: U401.19 (VAN); also elsewhere on the board
VAP: U401.20 (VAP); also elsewhere on the board
VBN: U401.21 (VBN); also elsewhere on the board
VBP: U401.22 (VBP); also elsewhere on the board
VCN: U401.23 (VCN); also elsewhere on the board
VCP: U401.24 (VCP); also elsewhere on the board
ZX_ADE: U401.35 (CF3/ZX); also elsewhere on the board

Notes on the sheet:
NÚCLEO METROLÓGICO ADE9430ACPZ PULL_HIGH -> +3V3_ADE PM0/PM1 -> GND (normal operation) NC1/NC2 -> GND EPAD and all grounds joined at the metrology ground point.
DECOUPLING — PLACE CLOSE TO U401 VDD: 100 nF + 10 uF DVDDOUT: 100 nF + 4.7 uF AVDDOUT: 100 nF + 4.7 uF REF: 100 nF + 4.7 uF
CLOCK 24.576 MHz crystal ABM8-24.576MHZ-8-D1X-T (CL 8 pF) 10 pF C0G load capacitors to GND (D-005)
RESET 10 k pull-up + 1 uF to GND RESET is active low

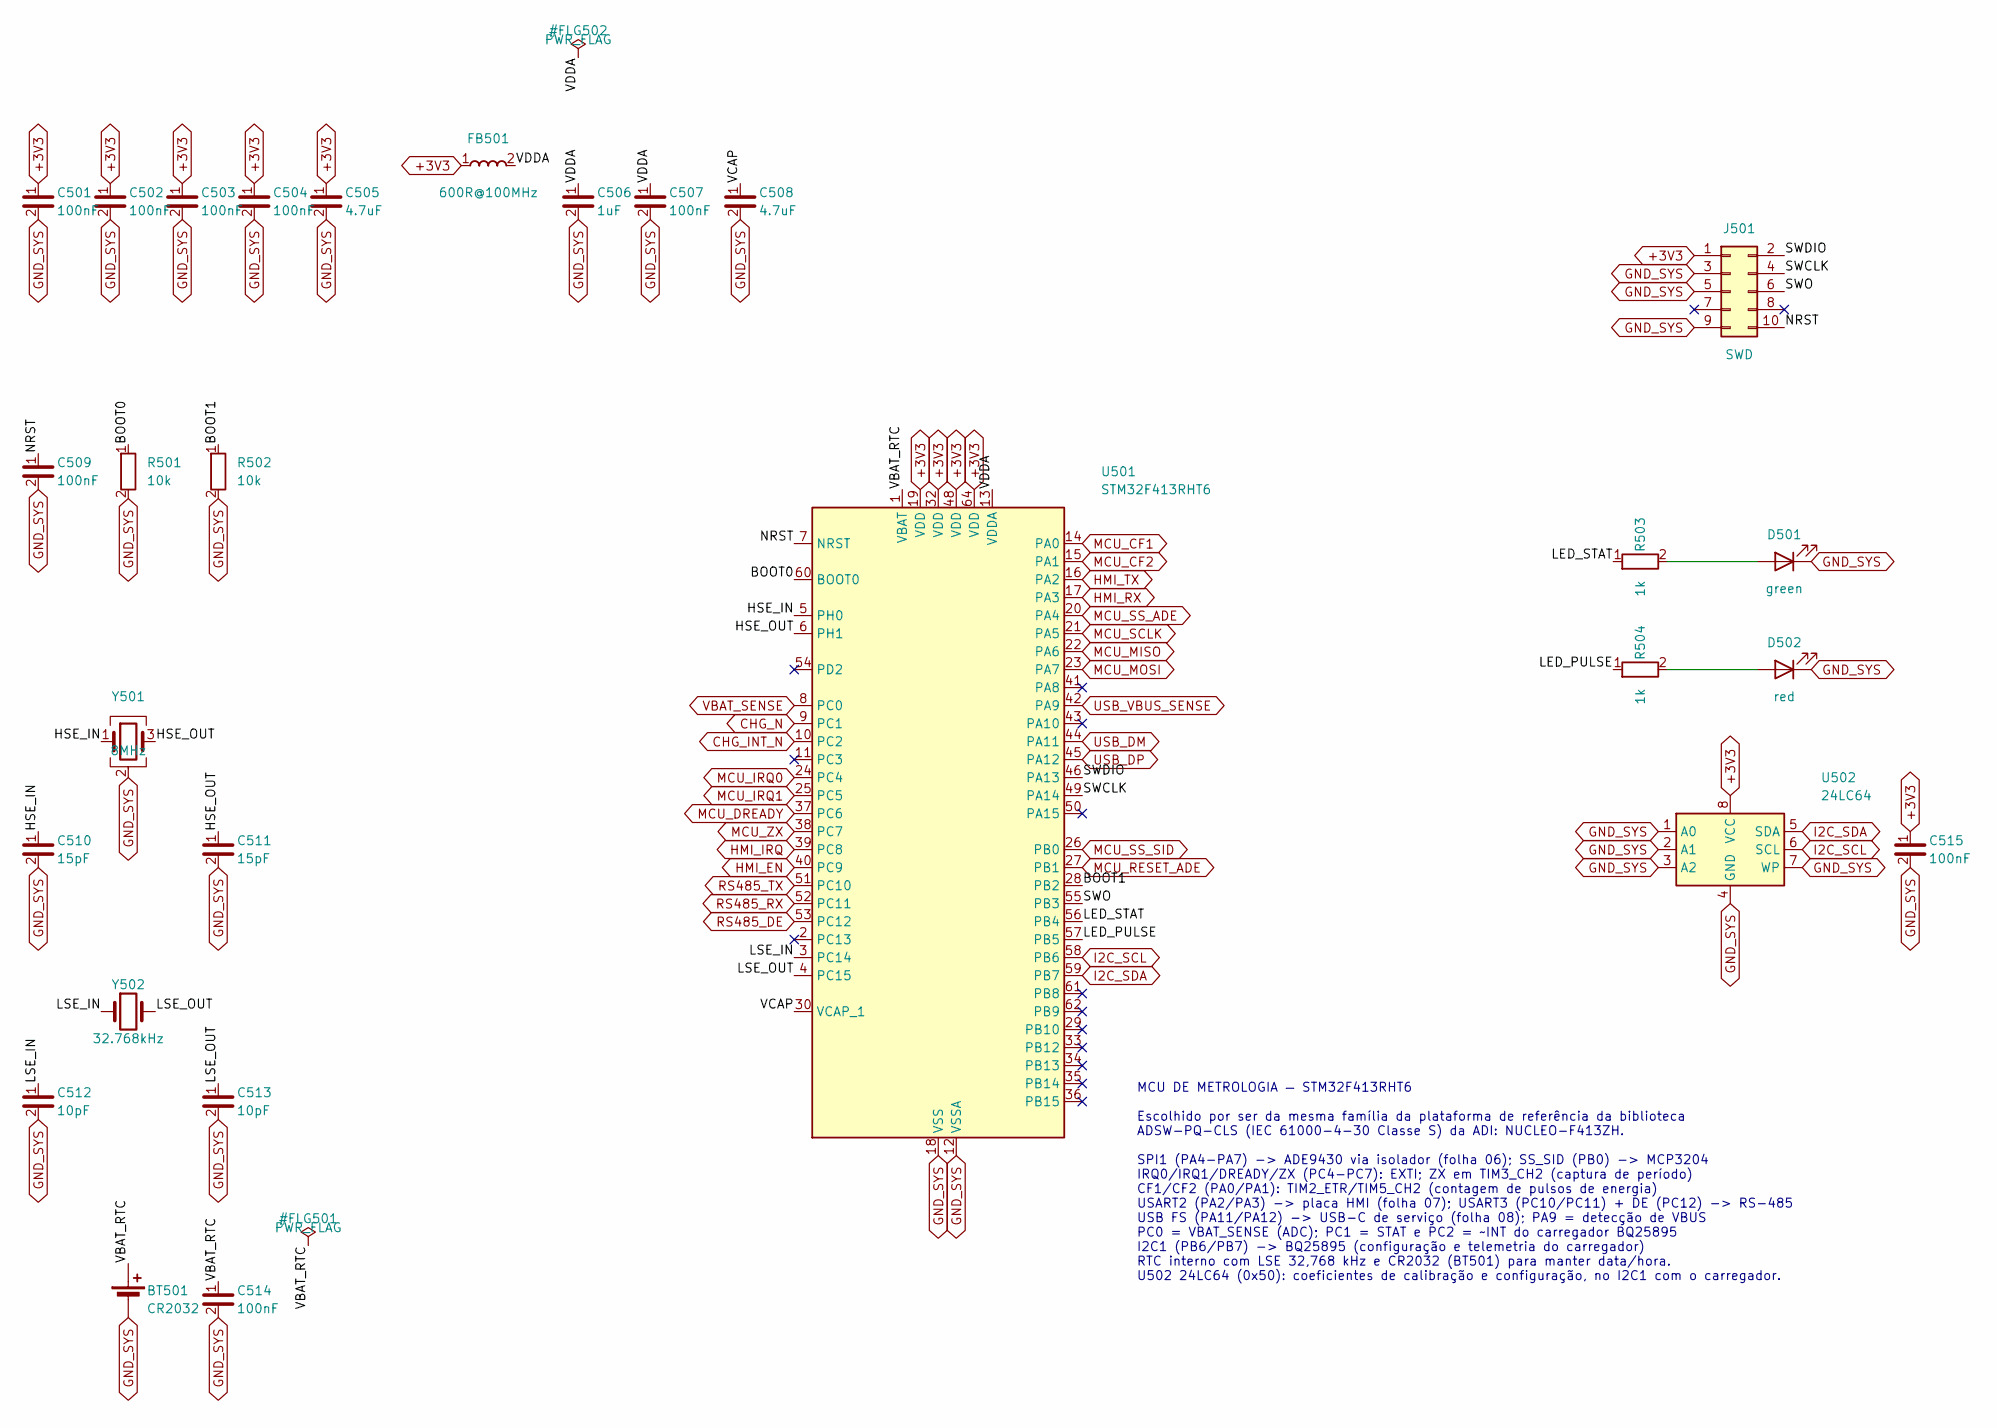
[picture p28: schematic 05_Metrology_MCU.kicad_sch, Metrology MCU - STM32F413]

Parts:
BT501: CR2032; BatteryHolder_Keystone_3034_1x20mm
C501, C502, C503, C504, C507, C509, C514, C515: 100nF; C_0603_1608Metric
C505, C508: 4.7uF; C_0805_2012Metric
C506: 1uF; C_0603_1608Metric
C510, C511: 15pF; C_0603_1608Metric
C512, C513: 10pF; C_0603_1608Metric
D501: green; LED_0603_1608Metric
D502: red; LED_0603_1608Metric
FB501: 600R@100MHz; L_0603_1608Metric
J501: SWD; PinHeader_2x05_P1.27mm_Vertical
R501, R502: 10k; R_0603_1608Metric
R503, R504: 1k; R_0603_1608Metric
U501: STM32F413RHT6; LQFP-64_10x10mm_P0.5mm
U502: 24LC64; SOIC-8_3.9x4.9mm_P1.27mm
Y501: 8MHz; Crystal_SMD_3225-4Pin_3.2x2.5mm
Y502: 32.768kHz; Crystal_SMD_3215-2Pin_3.2x1.5mm

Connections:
+3V3: C501.1, C502.1, C503.1, C504.1, C505.1, C515.1, FB501.1, J501.1, U501.19 (VDD), U501.32 (VDD), U501.48 (VDD), U501.64 (VDD), U502.8 (VCC); also elsewhere on the board
/Metrology MCU/BOOT0: R501.1, U501.60 (BOOT0)
/Metrology MCU/BOOT1: R502.1, U501.28 (PB2)
/Metrology MCU/HSE_IN: C510.1, U501.5 (PH0), Y501.1
/Metrology MCU/HSE_OUT: C511.1, U501.6 (PH1), Y501.3
/Metrology MCU/LED_PULSE: R504.1, U501.57 (PB5)
/Metrology MCU/LED_STAT: R503.1, U501.56 (PB4)
/Metrology MCU/LSE_IN: C512.1, U501.3 (PC14), Y502.1
/Metrology MCU/LSE_OUT: C513.1, U501.4 (PC15), Y502.2
/Metrology MCU/NRST: C509.1, J501.10, U501.7 (NRST)
/Metrology MCU/SWCLK: J501.4, U501.49 (PA14)
/Metrology MCU/SWDIO: J501.2, U501.46 (PA13)
/Metrology MCU/SWO: J501.6, U501.55 (PB3)
/Metrology MCU/VBAT_RTC: BT501.1 (+), C514.1, U501.1 (VBAT)
/Metrology MCU/VCAP: C508.1, U501.30 (VCAP_1)
/Metrology MCU/VDDA: C506.1, C507.1, FB501.2, U501.13 (VDDA)
CHG_INT_N: U501.10 (PC2); also elsewhere on the board
CHG_N: U501.9 (PC1); also elsewhere on the board
GND_SYS: BT501.2 (-), C501.2, C502.2, C503.2, C504.2, C505.2, C506.2, C507.2, C508.2, C509.2, C510.2, C511.2, C512.2, C513.2, C514.2, C515.2, D501.1 (K), D502.1 (K), J501.3, J501.5, J501.9, R501.2, R502.2, U501.12 (VSSA), U501.18 (VSS), U501.31 (VSS), U501.47 (VSS), U501.63 (VSS), U502.1 (A0), U502.2 (A1), U502.3 (A2), U502.4 (GND), U502.7 (WP), Y501.2 (G), Y501.4 (G); also elsewhere on the board
HMI_EN: U501.40 (PC9); also elsewhere on the board
HMI_IRQ: U501.39 (PC8); also elsewhere on the board
HMI_RX: U501.17 (PA3); also elsewhere on the board
HMI_TX: U501.16 (PA2); also elsewhere on the board
I2C_SCL: U501.58 (PB6), U502.6 (SCL); also elsewhere on the board
I2C_SDA: U501.59 (PB7), U502.5 (SDA); also elsewhere on the board
MCU_CF1: U501.14 (PA0); also elsewhere on the board
MCU_CF2: U501.15 (PA1); also elsewhere on the board
MCU_DREADY: U501.37 (PC6); also elsewhere on the board
MCU_IRQ0: U501.24 (PC4); also elsewhere on the board
MCU_IRQ1: U501.25 (PC5); also elsewhere on the board
MCU_MISO: U501.22 (PA6); also elsewhere on the board
MCU_MOSI: U501.23 (PA7); also elsewhere on the board
MCU_RESET_ADE: U501.27 (PB1); also elsewhere on the board
MCU_SCLK: U501.21 (PA5); also elsewhere on the board
MCU_SS_ADE: U501.20 (PA4); also elsewhere on the board
MCU_SS_SID: U501.26 (PB0); also elsewhere on the board
MCU_ZX: U501.38 (PC7); also elsewhere on the board
unnamed: D501.2 (A), R503.2
unnamed: D502.2 (A), R504.2
RS485_DE: U501.53 (PC12); also elsewhere on the board
RS485_RX: U501.52 (PC11); also elsewhere on the board
RS485_TX: U501.51 (PC10); also elsewhere on the board
USB_DM: U501.44 (PA11); also elsewhere on the board
USB_DP: U501.45 (PA12); also elsewhere on the board
USB_VBUS_SENSE: U501.42 (PA9); also elsewhere on the board
VBAT_SENSE: U501.8 (PC0); also elsewhere on the board

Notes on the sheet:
MCU DE METROLOGIA — STM32F413RHT6 Escolhido por ser da mesma família da plataforma de referência da biblioteca ADSW-PQ-CLS (IEC 61000-4-30 Classe S) da ADI: NUCLEO-F413ZH. SPI1 (PA4-PA7) -> ADE9430 via isolador (folha 06); SS_SID (PB0) -> MCP3204 IRQ0/IRQ1/DREADY/ZX (PC4-PC7): EXTI; ZX em TIM3_CH2 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

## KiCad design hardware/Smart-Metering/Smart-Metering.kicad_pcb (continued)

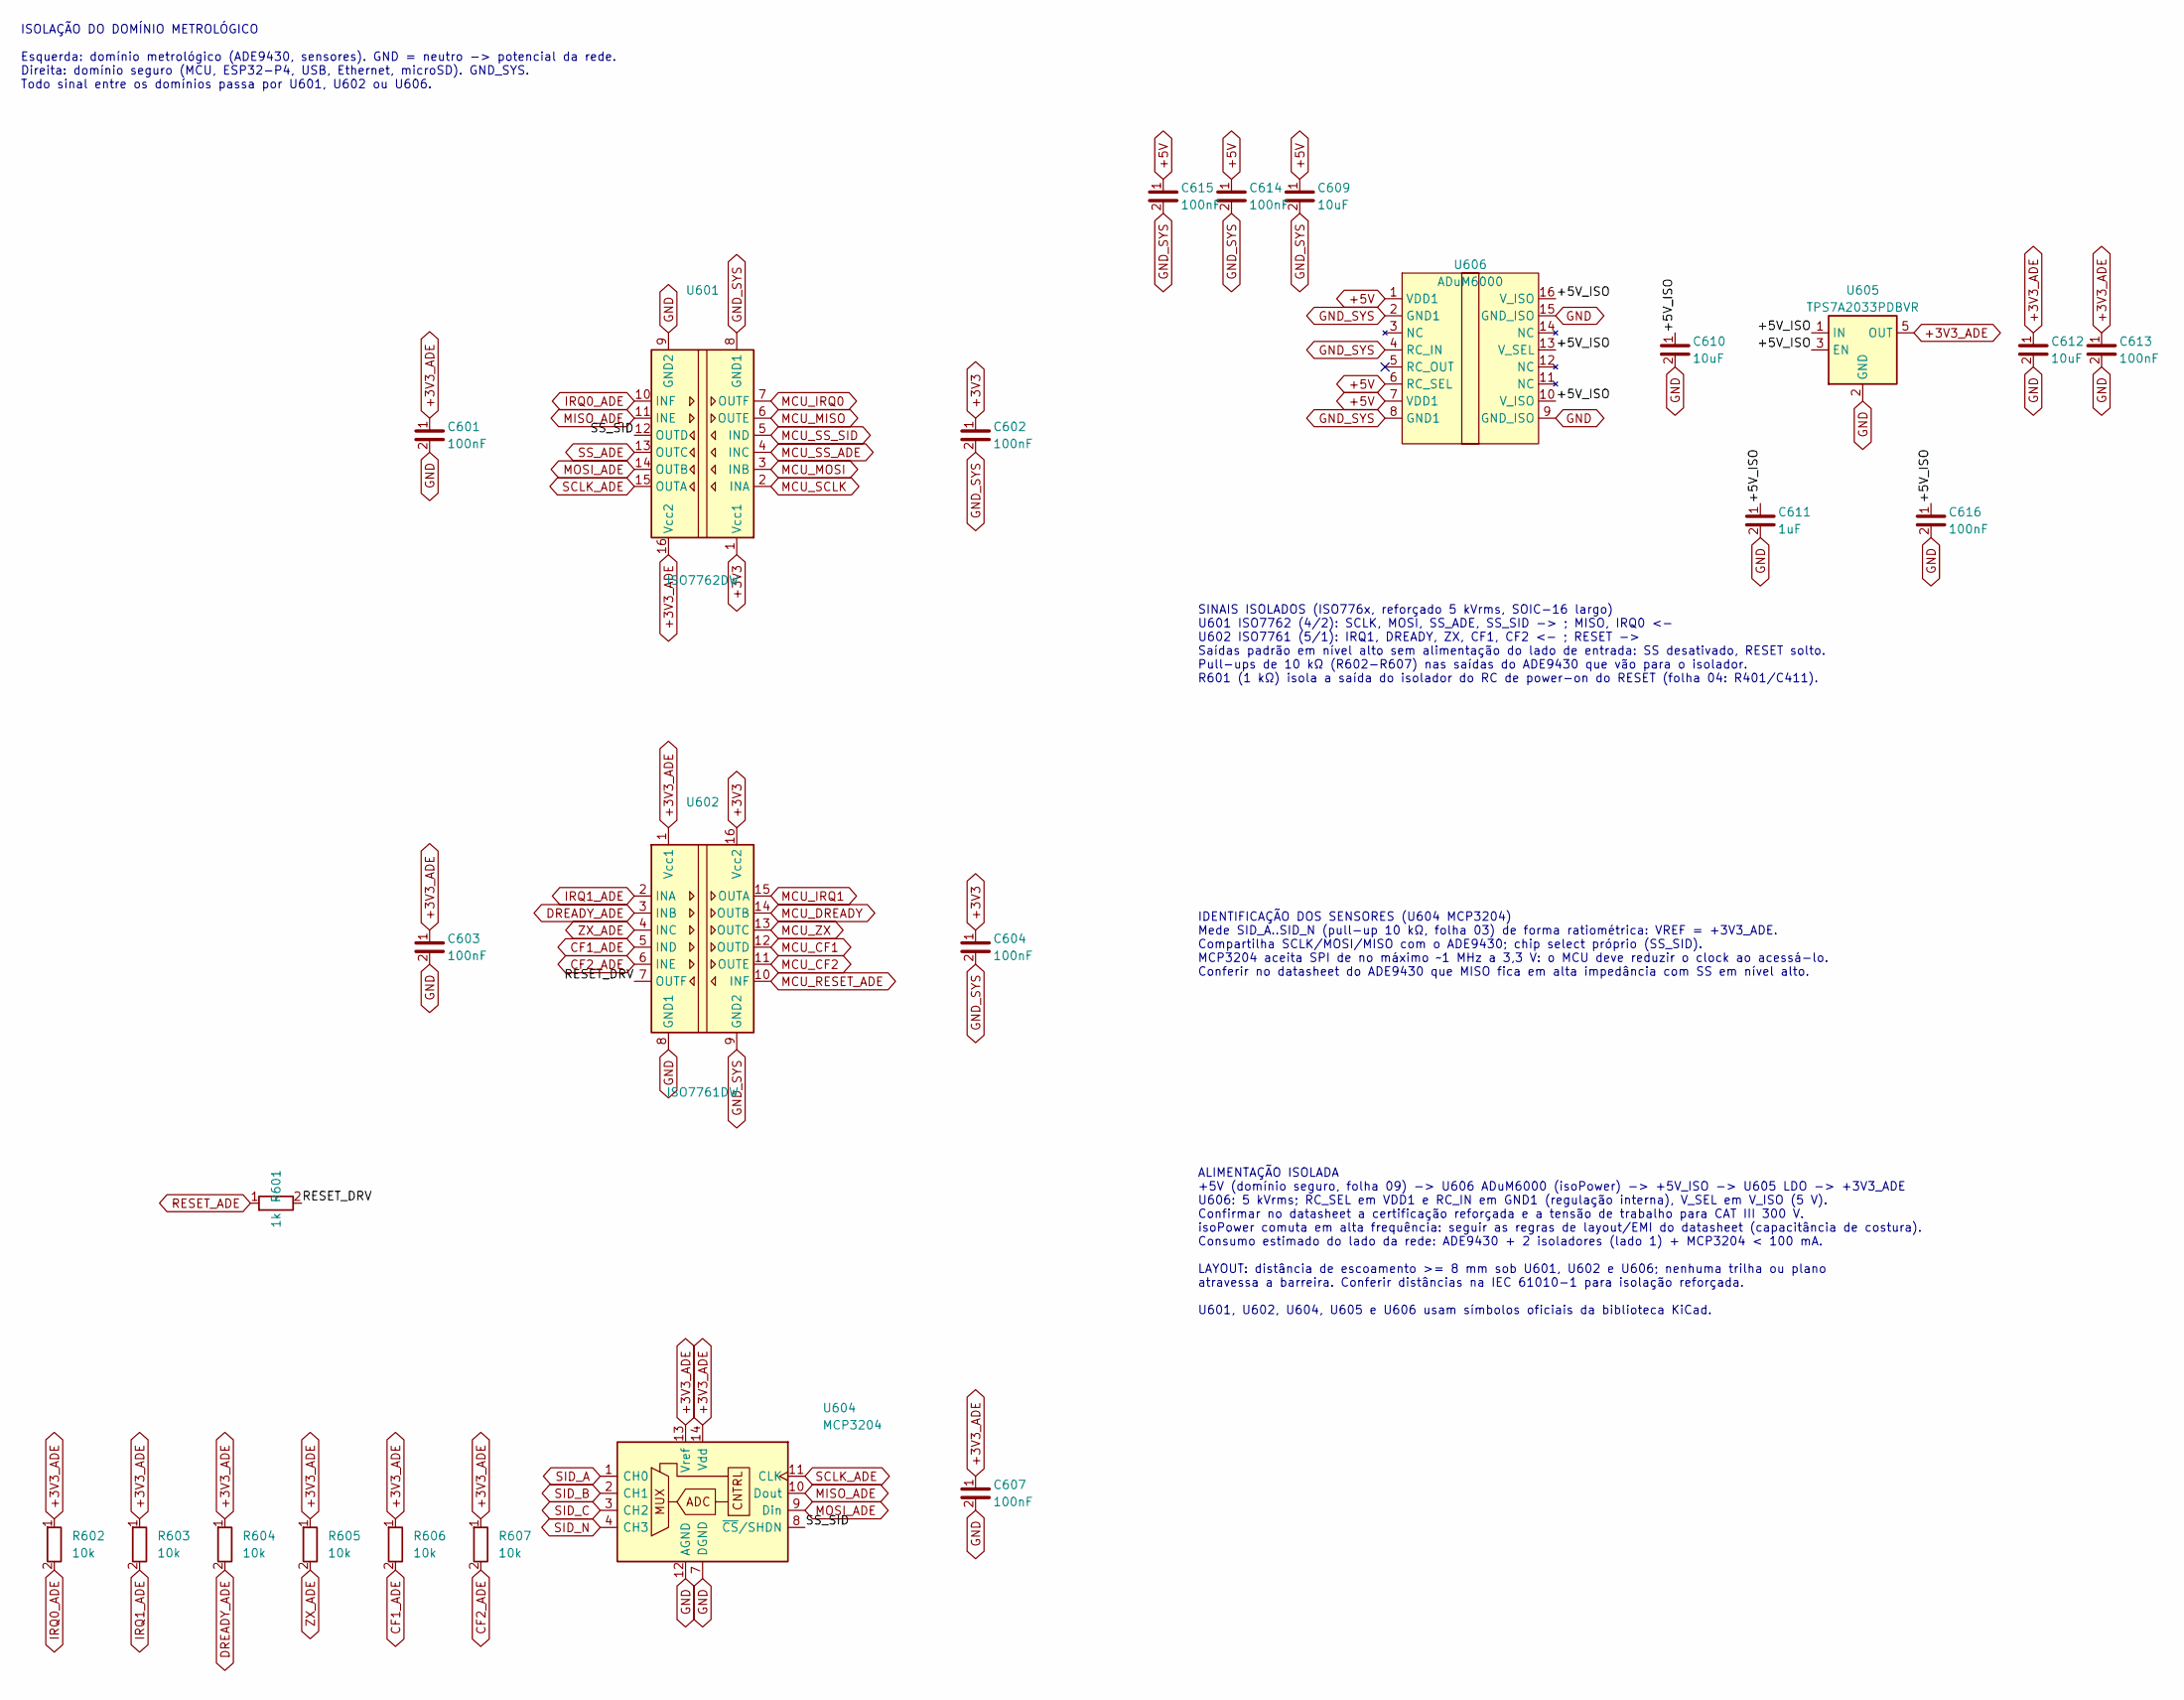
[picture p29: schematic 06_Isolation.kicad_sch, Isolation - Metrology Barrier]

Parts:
C601, C602, C603, C604, C607, C613, C614, C615, C616: 100nF; C_0603_1608Metric
C609, C610, C612: 10uF; C_0805_2012Metric
C611: 1uF; C_0603_1608Metric
R601: 1k; R_0603_1608Metric
R602, R603, R604, R605, R606, R607: 10k; R_0603_1608Metric
U601: ISO7762DW; SOIC-16W_7.5x10.3mm_P1.27mm
U602: ISO7761DW; SOIC-16W_7.5x10.3mm_P1.27mm
U604: MCP3204; SOIC-14_3.9x8.7mm_P1.27mm
U605: TPS7A2033PDBVR; SOT-23-5
U606: ADuM6000; SOIC-16W_7.5x10.3mm_P1.27mm

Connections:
+3V3: C602.1, C604.1, U601.1 (Vcc1), U602.16 (Vcc2); also elsewhere on the board
+3V3_ADE: C601.1, C603.1, C607.1, C612.1, C613.1, R602.1, R603.1, R604.1, R605.1, R606.1, R607.1, U601.16 (Vcc2), U602.1 (Vcc1), U604.13 (Vref), U604.14 (Vdd), U605.5 (OUT); also elsewhere on the board
+5V: C609.1, C614.1, C615.1, U606.1 (VDD1), U606.6 (RC_SEL), U606.7 (VDD1); also elsewhere on the board
/Isolation/+5V_ISO: C610.1, C611.1, C616.1, U605.1 (IN), U605.3 (EN), U606.10 (V_ISO), U606.13 (V_SEL), U606.16 (V_ISO)
/Isolation/RESET_DRV: R601.2, U602.7 (OUTF)
/Isolation/SS_SID: U601.12 (OUTD), U604.8 (~CS/SHDN)
CF1_ADE: R606.2, U602.5 (IND); also elsewhere on the board
CF2_ADE: R607.2, U602.6 (INE); also elsewhere on the board
DREADY_ADE: R604.2, U602.3 (INB); also elsewhere on the board
GND: C601.2, C603.2, C607.2, C610.2, C611.2, C612.2, C613.2, C616.2, U601.9 (GND2), U602.8 (GND1), U604.7 (DGND), U604.12 (AGND), U605.2 (GND), U606.9 (GND_ISO), U606.15 (GND_ISO); also elsewhere on the board
GND_SYS: C602.2, C604.2, C609.2, C614.2, C615.2, U601.8 (GND1), U602.9 (GND2), U606.2 (GND1), U606.4 (RC_IN), U606.8 (GND1); also elsewhere on the board
IRQ0_ADE: R602.2, U601.10 (INF); also elsewhere on the board
IRQ1_ADE: R603.2, U602.2 (INA); also elsewhere on the board
MCU_CF1: U602.12 (OUTD); also elsewhere on the board
MCU_CF2: U602.11 (OUTE); also elsewhere on the board
MCU_DREADY: U602.14 (OUTB); also elsewhere on the board
MCU_IRQ0: U601.7 (OUTF); also elsewhere on the board
MCU_IRQ1: U602.15 (OUTA); also elsewhere on the board
MCU_MISO: U601.6 (OUTE); also elsewhere on the board
MCU_MOSI: U601.3 (INB); also elsewhere on the board
MCU_RESET_ADE: U602.10 (INF); also elsewhere on the board
MCU_SCLK: U601.2 (INA); also elsewhere on the board
MCU_SS_ADE: U601.4 (INC); also elsewhere on the board
MCU_SS_SID: U601.5 (IND); also elsewhere on the board
MCU_ZX: U602.13 (OUTC); also elsewhere on the board
MISO_ADE: U601.11 (INE), U604.10 (Dout); also elsewhere on the board
MOSI_ADE: U601.14 (OUTB), U604.9 (Din); also elsewhere on the board
RESET_ADE: R601.1; also elsewhere on the board
SCLK_ADE: U601.15 (OUTA), U604.11 (CLK); also elsewhere on the board
SID_A: U604.1 (CH0); also elsewhere on the board
SID_B: U604.2 (CH1); also elsewhere on the board
SID_C: U604.3 (CH2); also elsewhere on the board
SID_N: U604.4 (CH3); also elsewhere on the board
SS_ADE: U601.13 (OUTC); also elsewhere on the board
ZX_ADE: R605.2, U602.4 (INC); also elsewhere on the board

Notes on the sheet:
ISOLAÇÃO DO DOMÍNIO METROLÓGICO Esquerda: domínio metrológico (ADE9430, sensores). GND = neutro -> potencial da rede. Direita: domínio seguro (MCU, ESP32-P4, USB, Ethernet, microSD). GND_SYS. Todo sinal entre os domínios passa por U601, U602 ou U606.
SINAIS ISOLADOS (ISO776x, reforçado 5 kVrms, SOIC-16 largo) U601 ISO7762 (4/2): SCLK, MOSI, SS_ADE, SS_SID -> ; MISO, IRQ0 <- U602 ISO7761 (5/1): IRQ1, DREADY, ZX, CF1, CF2 <- ; RESET -> Saídas padrão em nível alto sem alimentação do lado de entrada: SS desativado, RESET solto. Pull-ups de 10 kΩ (R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
IDENTIFICAÇÃO DOS SENSORES (U604 MCP3204) Mede SID_A..SID_N (pull-up 10 kΩ, folha 03) de forma ratiométrica: VREF = +3V3_ADE. Compartilha SCLK/MOSI/MISO com o ADE9430; chip select próprio (SS_SID). MCP3204 aceita SPI de no máximo ~1 MHz a 3,3 V: o MCU deve reduzir o clock ao acessá-lo. Conferir no 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
ALIMENTAÇÃO ISOLADA +5V (domínio seguro, folha 09) -> U606 ADuM6000 (isoPower) -> +5V_ISO -> U605 LDO -> +3V3_ADE U606: 5 kVrms; RC_SEL em VDD1 e RC_IN em GND1 (regulação interna), V_SEL em V_ISO (5 V). Confirmar no datasheet a certificação reforçada e a tensão de trabalho para CAT III 300 V. isoPo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

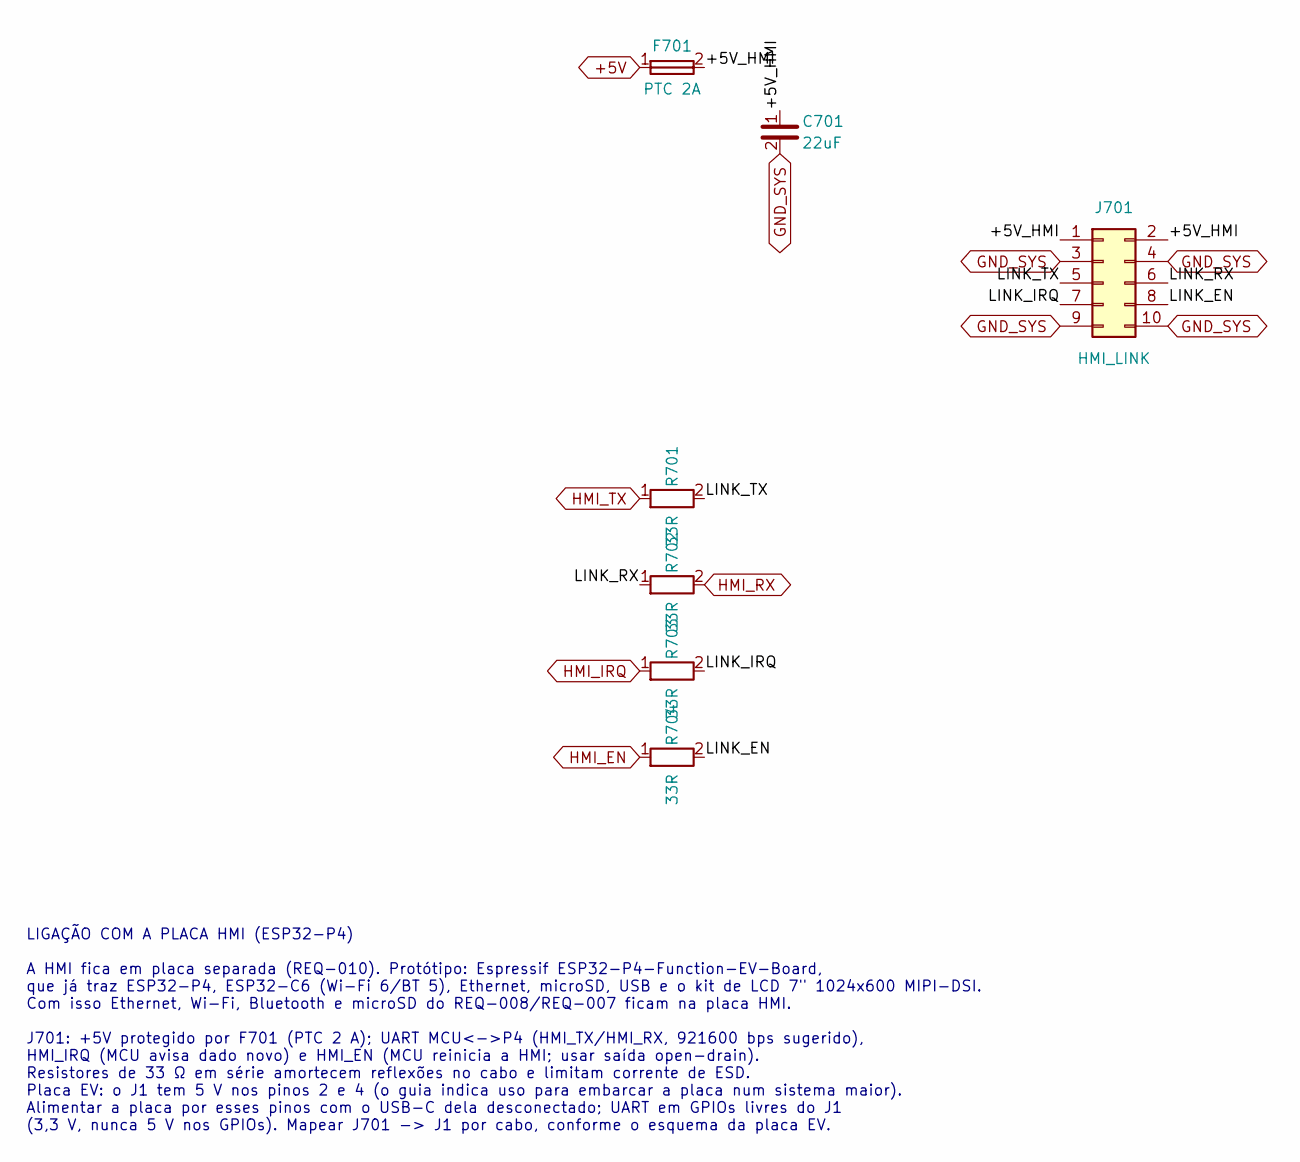
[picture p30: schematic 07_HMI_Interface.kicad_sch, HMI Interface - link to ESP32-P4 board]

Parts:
C701: 22uF; C_1206_3216Metric
F701: PTC 2A; Fuse_1812_4532Metric
J701: HMI_LINK; PinHeader_2x05_P2.54mm_Vertical
R701, R702, R703, R704: 33R; R_0603_1608Metric

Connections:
+5V: F701.1; also elsewhere on the board
/HMI Interface/+5V_HMI: C701.1, F701.2, J701.1, J701.2
/HMI Interface/LINK_EN: J701.8, R704.2
/HMI Interface/LINK_IRQ: J701.7, R703.2
/HMI Interface/LINK_RX: J701.6, R702.1
/HMI Interface/LINK_TX: J701.5, R701.2
GND_SYS: C701.2, J701.3, J701.4, J701.9, J701.10; also elsewhere on the board
HMI_EN: R704.1; also elsewhere on the board
HMI_IRQ: R703.1; also elsewhere on the board
HMI_RX: R702.2; also elsewhere on the board
HMI_TX: R701.1; also elsewhere on the board

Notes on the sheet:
LIGAÇÃO COM A PLACA HMI (ESP32-P4) A HMI fica em placa separada (REQ-010). Protótipo: Espressif ESP32-P4-Function-EV-Board, que já traz ESP32-P4, ESP32-C6 (Wi-Fi 6/BT 5), Ethernet, microSD, USB e o kit de LCD 7" 1024x600 MIPI-DSI. Com isso Ethernet, Wi-Fi, Bluetooth e microSD do REQ-008/REQ-007 fic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

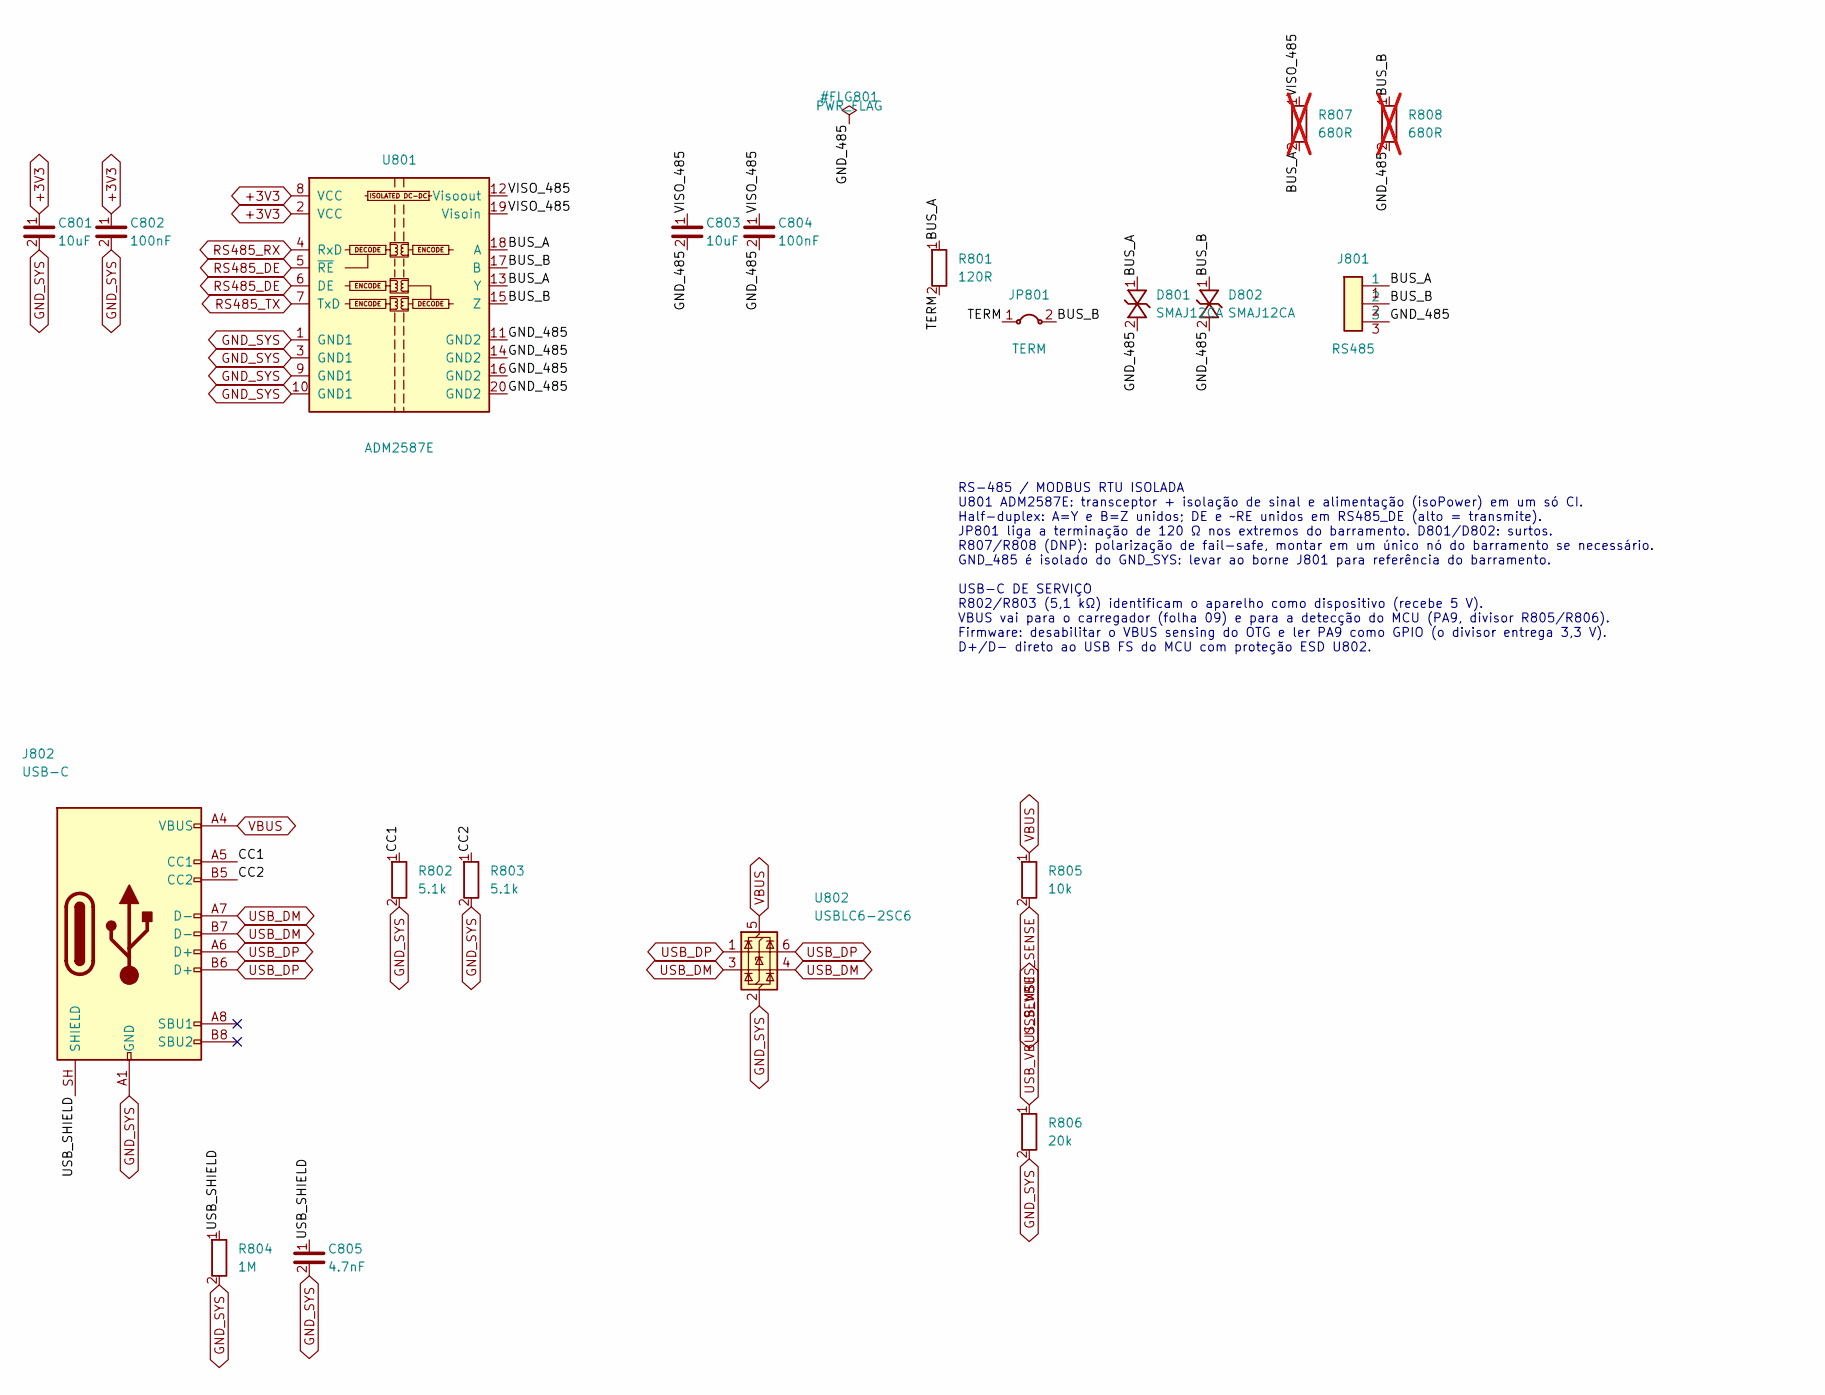
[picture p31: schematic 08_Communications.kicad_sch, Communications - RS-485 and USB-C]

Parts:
C801, C803: 10uF; C_0805_2012Metric
C802, C804: 100nF; C_0603_1608Metric
C805: 4.7nF; C_1206_3216Metric
D801, D802: SMAJ12CA; D_SMA
J801: RS485; TerminalBlock_Phoenix_MKDS-1,5-3-5.08_1x03_P5.08mm_Horizont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
J802: USB-C; USB_C_Receptacle_GCT_USB4105-xx-A_16P_TopMnt_Horizontal
JP801: TERM; PinHeader_1x02_P2.54mm_Vertical
R801: 120R; R_1206_3216Metric
R802, R803: 5.1k; R_0603_1608Metric
R804: 1M; R_0603_1608Metric
R805: 10k; R_0603_1608Metric
R806: 20k; R_0603_1608Metric
R807, R808: 680R; R_0603_1608Metric; not fitted
U801: ADM2587E; SOIC-20W_7.5x12.8mm_P1.27mm
U802: USBLC6-2SC6; SOT-23-6

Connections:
+3V3: C801.1, C802.1, U801.2 (VCC), U801.8 (VCC); also elsewhere on the board
/Communications/BUS_A: D801.1, J801.1, R801.1, R807.2, U801.13 (Y), U801.18 (A)
/Communications/BUS_B: D802.1, J801.2, JP801.2, R808.1, U801.15 (Z), U801.17 (B)
/Communications/CC1: J802.A5 (CC1), R802.1
/Communications/CC2: J802.B5 (CC2), R803.1
/Communications/GND_485: C803.2, C804.2, D801.2, D802.2, J801.3, R808.2, U801.11 (GND2), U801.14 (GND2), U801.16 (GND2), U801.20 (GND2)
/Communications/TERM: JP801.1, R801.2
/Communications/USB_SHIELD: C805.1, J802.SH (SHIELD), R804.1
/Communications/VISO_485: C803.1, C804.1, R807.1, U801.12 (Visoout), U801.19 (Visoin)
GND_SYS: C801.2, C802.2, C805.2, J802.A1 (GND), J802.A12 (GND), J802.B1 (GND), J802.B12 (GND), R802.2, R803.2, R804.2, R806.2, U801.1 (GND1), U801.3 (GND1), U801.9 (GND1), U801.10 (GND1), U802.2 (GND); also elsewhere on the board
RS485_DE: U801.5 (~RE), U801.6 (DE); also elsewhere on the board
RS485_RX: U801.4 (RxD); also elsewhere on the board
RS485_TX: U801.7 (TxD); also elsewhere on the board
USB_DM: J802.A7 (D-), J802.B7 (D-), U802.3 (I/O2), U802.4 (I/O2); also elsewhere on the board
USB_DP: J802.A6 (D+), J802.B6 (D+), U802.1 (I/O1), U802.6 (I/O1); also elsewhere on the board
USB_VBUS_SENSE: R805.2, R806.1; also elsewhere on the board
VBUS: J802.A4 (VBUS), J802.A9 (VBUS), J802.B4 (VBUS), J802.B9 (VBUS), R805.1, U802.5 (VBUS); also elsewhere on the board

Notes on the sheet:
RS-485 / MODBUS RTU ISOLADA U801 ADM2587E: transceptor + isolação de sinal e alimentação (isoPower) em um só CI. Half-duplex: A=Y e B=Z unidos; DE e ~RE unidos em RS485_DE (alto = transmite). JP801 liga a terminação de 120 Ω nos extremos do barramento. D801/D802: surtos. R807/R808 (DNP): polarizaçã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

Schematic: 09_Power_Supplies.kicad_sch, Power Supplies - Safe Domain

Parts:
C901, C902, C903, C905, C916, C917: 10uF; C_0805_2012Metric
C904: 100nF; C_0603_1608Metric
C906, C907, C908, C909, C910, C911: 22uF; C_1206_3216Metric
C914: 47nF; C_0603_1608Metric
C915: 4.7uF; C_0805_2012Metric
D901, D902: SS54; D_SMC
J901: BATTERY_1S; JST_PH_B3B-PH-K_1x03_P2.00mm_Vertical
L901: 2.2uH; L_Bourns-SRN4018
L902: 1uH; L_Bourns_SRP7028A_7.3x6.6mm
L903: 2.2uH; L_Bourns_SRP7028A_7.3x6.6mm
Q901: AO3401A; SOT-23
Q902: 2N7002; SOT-23
R901: 5.23k; R_0603_1608Metric
R902: 120R; R_0603_1608Metric
R903: 30.1k; R_0603_1608Metric
R904, R905: 10k; R_0603_1608Metric
R906, R907, R908, R910, R912: 100k; R_0603_1608Metric
R909: 732k; R_0603_1608Metric
R911, R915: 4.7k; R_0603_1608Metric
SW901: POWER; JST_PH_B2B-PH-K_1x02_P2.00mm_Vertical
U901: BQ25895RTW; Texas_RTW_WQFN-24-1EP_4x4mm_P0.5mm_EP2.7x2.7mm_ThermalVias
U902: TPS63001; Texas_DRC0010J_ThermalVias
U903: TPS61022; Texas_RWU0007A_VQFN-7_2x2mm_P0.5mm

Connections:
+3V3: C906.1, C907.1, R904.1, R905.1, R911.1, R915.1, U902.1 (VOUT), U902.10 (FB); also elsewhere on the board
+5V: C909.1, C910.1, C911.1, R909.1, U903.3 (VOUT); also elsewhere on the board
/Power Supplies/BAT_NTC: J901.2, R901.2, R903.1, U901.11 (TS)
/Power Supplies/BB_L1: L901.1, U902.4 (L1)
/Power Supplies/BB_L2: L901.2, U902.2 (L2)
/Power Supplies/CHG_BTST: C914.1, U901.21 (BTST)
/Power Supplies/CHG_DM: Q902.2 (S), U901.3 (D-)
/Power Supplies/CHG_DP: Q902.3 (D), U901.2 (D+)
/Power Supplies/CHG_SW: C914.2, L903.1, U901.19 (SW), U901.20 (SW)
/Power Supplies/FB_5V: R909.2, R910.1, U903.4 (FB)
/Power Supplies/ILIM: R902.1, U901.10 (ILIM)
/Power Supplies/PMID: C916.1, U901.23 (PMID)
/Power Supplies/PWR_EN: R908.2, SW901.1, U902.6 (EN), U903.5 (EN)
/Power Supplies/REGN: C915.1, R901.1, U901.22 (REGN)
/Power Supplies/SW_5V: L902.2, U903.2 (SW)
/Power Supplies/VBAT: C903.1, J901.1, R906.1, U901.13 (BAT), U901.14 (BAT)
/Power Supplies/VBUS_SW: D902.2 (A), Q901.3 (D)
/Power Supplies/VIN_CHG: C901.1, D901.1 (K), D902.1 (K), U901.1 (VBUS)
/Power Supplies/VSYS: C902.1, C905.1, C908.1, C917.1, L902.1, L903.2, R908.1, U901.15 (SYS), U901.16 (SYS), U902.5 (VIN), U902.7 (PS/SYNC), U902.8 (VINA), U903.6 (MODE), U903.7 (VIN)
CHG_INT_N: R904.2, U901.7 (~INT); also elsewhere on the board
CHG_N: R905.2, U901.4 (STAT); also elsewhere on the board
GND_SYS: C901.2, C902.2, C903.2, C904.2, C905.2, C906.2, C907.2, C908.2, C909.2, C910.2, C911.2, C915.2, C916.2, C917.2, J901.3, R902.2, R903.2, R907.2, R910.2, R912.2, SW901.2, U901.8 (OTG), U901.9 (~CE), U901.17 (PGND), U901.18 (PGND), U901.25 (PGND), U902.3 (PGND), U902.9 (GND), U902.11 (PGND), U903.1 (GND); also elsewhere on the board
I2C_SCL: R911.2, U901.5 (SCL); also elsewhere on the board
I2C_SDA: R915.2, U901.6 (SDA); also elsewhere on the board
VBAT_SENSE: C904.1, R906.2, R907.1; also elsewhere on the board
VBUS: Q901.2 (S); also elsewhere on the board
VIN_ACDC: D901.2 (A), Q901.1 (G), Q902.1 (G), R912.1; also elsewhere on the board

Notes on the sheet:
ALIMENTAÇÃO DO DOMÍNIO SEGURO (GND_SYS) VIN_ACDC (5 V, conversor AC/DC da folha 01) --D901--+ VBUS (USB-C de serviço, folha 08) --Q901--D902--+--> VIN_CHG -> U901 BQ25895 (chaveado) Q901 corta o VBUS quando o AC/DC está presente: a porta USB nunca supre a placa junto com o AC/DC. U901 SYS = VSYS (N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
CARREGADOR U901 — BQ25895 (chaveado, 1,5 MHz, NVDC) Limite de entrada: R902 = 120 Ω -> ≈ 3,0 A (RAC20-05SK fornece 4 A). O registrador IINLIM pode reduzir, nunca aumentar acima do ILIM. D+/D- do BQ25895: Q902 os une só com o AC/DC presente (DCP -> 3 A, limitado pelo ILIM). Só pelo USB-C: D+/D- solt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
ORÇAMENTO DE POTÊNCIA (estimativa a refinar) ESP32-P4 + ESP32-C6 + PHY Ethernet + MCU ~1,5 W Display 7" com backlight ~2,5 W Domínio metrológico via PS601 ~0,5 W Total ~5,2 W em VSYS. Com 3 A x ~4,5 V = ~13 W de entrada, sobra folga para carga de 1,0 A (definida por firmware): ~2,5 h para 2500 mAh.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
SW901: fechada desliga os conversores (PWR_EN = 0). Futuramente pode virar liga/desliga controlado pelo MCU. U901-U903 usam símbolos oficiais da biblioteca KiCad. U903 TPS61022: compensação interna; MODE em VSYS = PWM forçado (menos ruído). Layout dos conversores: seguir o layout recomendado (laço 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

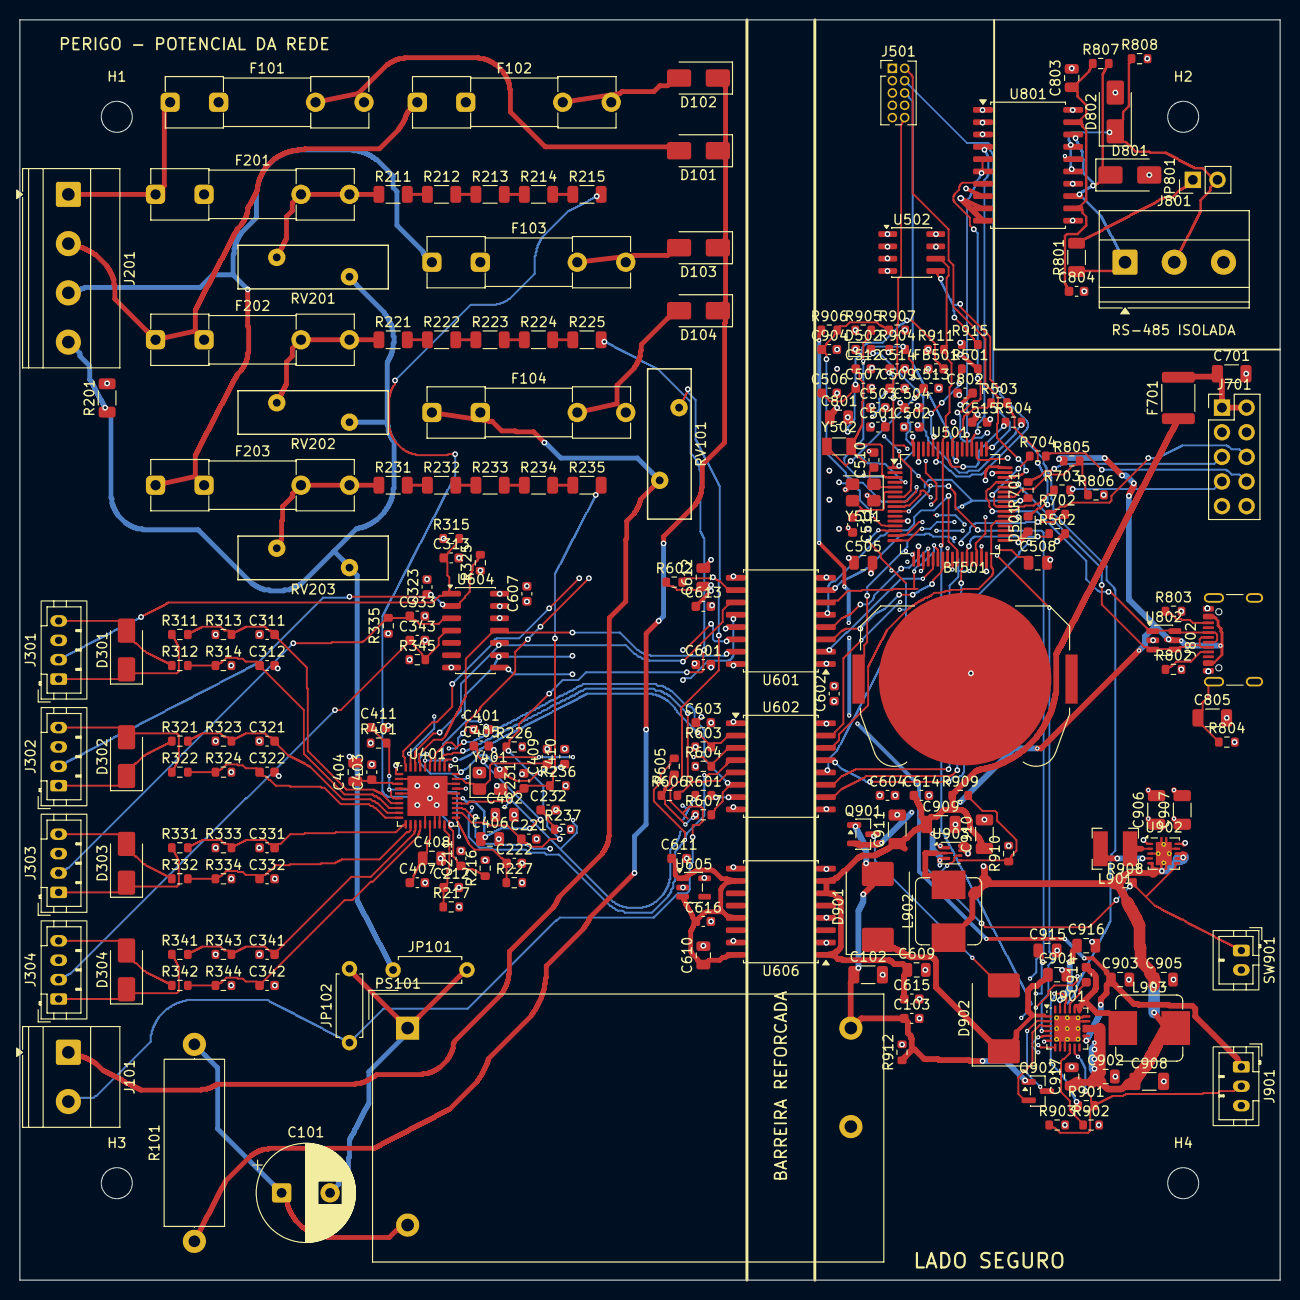
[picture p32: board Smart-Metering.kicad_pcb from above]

Board: 4 copper layers, 130.0 x 130.0 mm, 230 parts (0 on the bottom side), 154 nets.

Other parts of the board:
H1, H2, H3, H4: MountingHole_3.2mm_M3

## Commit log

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2026-10-03 Completa alimentação, clock e reset do ADE9430
    [04_ADE9430.kicad_sch]
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2026-10-03 Fix rear housing mounting pillars
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2026-10-03 Corrige eixo Y dos símbolos próprios e ligações do ADE9430
    Os símbolos de SmartMetering.kicad_sym foram escritos com o eixo Y
    para baixo, mas o formato de biblioteca do KiCad usa Y para cima.
    Com isso, na folha 04_ADE9430:
    - os pinos 1-24 e o EPAD do U1 ficavam desconectados;
    - os pinos 25-40 caíam em labels trocados (AVDDOUT em SS_ADE,
    VDD em MISO_ADE, SCLK/MOSI em GND etc.);
    - os pinos GND do cristal Y1 ficavam desconectados;
    - as pernas dos pinos verticais (R, C, cristal, EPAD) apontavam
    para fora do corpo do símbolo.
    Correção: inverter o Y de pinos, propriedades e gráficos e orientar
    os pinos verticais para o corpo, na biblioteca e na cópia embutida
    na folha. Agora o pin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
    [04_ADE9430.kicad_sch]
2026-10-03 Implementa front-ends de tensão e corrente do ADE9430
    02_Voltage_Sensing (3 fases, pseudo-diferencial):
    - borne J101 (VA/VB/VC/VN) com labels globais LINE_A/B/C e NEUTRAL;
    - fusível + varistor 320 VAC fase-neutro por fase;
    - divisor 5 x 200 kΩ + 1 kΩ (1/1001): 220 V -> 0,311 Vpk, até ~354 Vrms
    com no máximo 0,5 Vpk por pino (limite do ADE9430: ±0,6 V);
    - anti-aliasing 999 Ω // 22 nF (fc ≈ 7,2 kHz); VxN com 1 kΩ // 22 nF
    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
    [02_Voltage_Sensing.kicad_sch, 03_Current_Sensing.kicad_sch]
2026-10-03 Refaz entrada de corrente para sensores configuráveis por montagem
    A folha 03_Current_Sensing deixa de usar TC com saída em corrente
    (risco de secundário aberto ao desconectar) e passa a aceitar, na
    mesma placa, três tipos de sensor escolhidos pelos valores de Ra/Rb:
    - TC 333 mV (padrão): Ra = 1k, Rb = 1M, ADE9430 com PGA 1x;
    - bobina Rogowski: Ra = 1k, Rb = 1M, PGA 4x e integrador digital;
    - SCT-013 com saída de 1 V (protótipo): Ra = 2k49, Rb = 1k65 (x0,40).
    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
    [03_Current_Sensing.kicad_sch]
2026-10-03 Implementa folha de isolação logo após o ADE9430
    06_Isolation define a barreira reforçada entre o domínio metrológico
    (potencial da rede, GND = neutro) e o domínio seguro (GND_SYS):
    - U601 ISO7741: SCLK, MOSI, SS para o ADE9430; MISO de volta;
    - U602 ISO7742: RESET e SS_SID para o lado da rede; CF1/CF2 de volta;
    - U603 ISO7740: IRQ0, IRQ1, DREADY e ZX de volta;
    - pull-ups de 10 kΩ nas saídas do ADE9430 e 1 kΩ em série no RESET;
    - U604 MCP3204 lê SID_A..SID_N de forma ratiométrica, compartilhando o
    SPI isolado com chip select próprio;
    - PS601 DC/DC isolado reforçado (+5V -> +5V_ISO) e U605 LDO
    TPS7A2033 gerando +3V3_ADE.
    Novos símbolos: ISO7740/7741/7742, MCP3204, DCDC_I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
    [06_Isolation.kicad_sch]
2026-10-03 Implementa folha de alimentação do domínio seguro
    09_Power_Supplies (tudo referenciado a GND_SYS):
    - entrada 5 V por OU de diodos Schottky: VIN_ACDC (conversor AC/DC da
    folha 01) e VBUS (USB-C de serviço);
    - U901 BQ24074: carregador Li-ion 1S com power path; ILIM ≈ 1,48 A,
    carga ≈ 0,89 A, NTC do pack em TS, ~PGOOD/~CHG para o MCU;
    - U902 TPS63021: buck-boost de VSYS para +3V3 (opera em toda a faixa
    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
    [09_Power_Supplies.kicad_sch]
2026-10-03 Implementa folha de entrada de energia e numera referências por folha
    01_Power_Input:
    - modo padrão: LINE_A/B/C -> fusível -> diodo S1M em OU para o
    barramento HV, retorno no NEUTRAL via JP101; o instrumento segue
    alimentado com qualquer fase presente;
    - modo auxiliar (J101, 100-240 VAC, com varistor): F104/D104/JP102,
    não montados por padrão; para rede 3 fios sem neutro;
    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
    [01_Power_Input.kicad_sch, 02_Voltage_Sensing.kicad_sch, 03_Current_Sensing.kicad_sch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]
2026-10-03 Usa símbolos oficiais do KiCad nas folhas de isolação e alimentação
    Os símbolos oficiais da biblioteca KiCad 10 (gitlab.com/kicad/libraries)
    substituem os desenhados de memória:
    - 06_Isolation: ISO7762DW (4/2) e ISO7761DW (5/1) no lugar de três
    ISO774x; os 12 sinais cabem em dois isoladores reforçados. MCP3204 e
    TPS7A20xxxDBV oficiais (os pinouts anteriores conferiram).
    - 09_Power_Supplies: BQ24074RGT oficial revelou que o pino 15 é ITERM,
    não SYSOFF; agora tem R911 (3,01 kΩ, fim de carga ≈ 90 mA). +3V3 passa
    ao TPS63001 (buck-boost 3,3 V fixo) e +5V ao TPS61089, com resistores
    de frequência, limite de corrente e compensação a confirmar no WEBENCH.
    Símbolos pró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
    [06_Isolation.kicad_sch, 09_Power_Supplies.kicad_sch]
2026-10-03 Completa o esquemático: MCU, interface HMI e comunicações
    05_Metrology_MCU: STM32F413RHT6 (símbolo oficial), mesma família da
    plataforma de referência da biblioteca ADSW-PQ-CLS (NUCLEO-F413ZH).
    SPI1 isolado para ADE9430/MCP3204, IRQ/DREADY/ZX em EXTI, CF1/CF2 em
    timers, USART2 para a HMI, USART3 + DE para RS-485, USB FS, VBAT_SENSE,
    estado do carregador, HSE 8 MHz, RTC com LSE 32,768 kHz e CR2032, SWD
    de 10 pinos e LEDs de status e pulso.
    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
    [05_Metrology_MCU.kicad_sch, 07_HMI_Interface.kicad_sch, 08_Communications.kicad_sch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]
2026-10-03 Revisão completa do esquemático e correções
    Verificação automática sobre o netlist global (215 componentes, 176 nets):
    sem pinos soltos, sem nets de alimentação sem fonte, sem saídas em
    conflito e isolação íntegra (terras só se encontram nas barreiras
    PS101, PS601, U601, U602 e U801).
    Correções:
    - footprint do ADE9430 inexistente na biblioteca KiCad trocado por
    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
    [01_Power_Input.kicad_sch, 02_Voltage_Sensing.kicad_sch, 04_ADE9430.kicad_sch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]
2026-10-03 Troca o carregador linear BQ24074 pelo chaveado BQ25895
    O BQ24074 limitava a entrada a 1,48 A e, com o sistema consumindo cerca
    de 5,2 W, sobravam só ~0,3 A para carregar a bateria (mais de 8 h).
    09_Power_Supplies:
    - U901 BQ25895RTW (símbolo oficial): carregador chaveado com power path
    NVDC; limite de entrada de 2,0 A por R902 (180 Ω), o máximo do
    IRM-10-5; carga de ~0,85 A com a tela ligada;
    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
    [05_Metrology_MCU.kicad_sch, 09_Power_Supplies.kicad_sch]
2026-10-03 Resolve as pendências da revisão do esquemático
    P1 ADE9430: footprint VQFN-40 6x6 com EP de 4,15 mm, compatível com as
    variantes CP-40 de 6x6 mm (EP de 3,9 a 4,7 mm).
    P2 Confirmado no datasheet: MISO solto com SS alto (pull-up de 100 kΩ)
    e NC1/NC2 em GND, como já estava.
    P3 J301-J304: headers JST PH de 4 vias cabeados até conectores M8
    fêmea de painel (à prova de toque).
    P4 PS601 -> U606 ADuM6000 (isoPower 5 kVrms, símbolo oficial).
    P5 PS101 -> RAC20-05SK/277 (85-305 VAC, 120-430 VDC, 20 W); fusíveis
    T500mA, R101 3 W, C101 10 uF/450 V; entrada do BQ25895 a 3 A.
    P7 TPS61089 -> TPS61022 (compensação interna, sem valores a ajustar).
    P8 Placa EV alimentada pel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
    [01_Power_Input.kicad_sch, 03_Current_Sensing.kicad_sch, 04_ADE9430.kicad_sch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]
2026-10-03 Inicia o layout da placa de metrologia
    Smart-Metering.kicad_pcb (formato KiCad 10), gerado a partir do
    esquemático:
    - contorno de 130 x 130 mm, 4 camadas, 4 furos M3 (110 x 110 mm);
    - 223 componentes com footprints oficiais, nets nos pads e vínculo
    com os símbolos (path), compatível com "Update PCB from Schematic";
    todos os pinos do esquemático têm pad correspondente;
    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
    [Smart-Metering.kicad_pcb]
2026-10-03 Reorganiza o posicionamento do domínio quente para o roteamento
    - barreira principal movida para x = 75-82 mm: o lado da rede e da
    metrologia ganha 12,5 mm; isoladores e ADuM6000 acompanham;
    - entradas de tensão em linhas por fase (borne -> fusível -> varistor
    -> cadeia do divisor em linha reta), espaçadas para 3 mm entre fases;
    - entradas de corrente em linhas por canal (conector -> TVS -> Ra/Rb ->
    filtro), ao lado do ADE9430;
    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
    [Smart-Metering.kicad_pcb]
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2026-10-03 Reorganiza o entorno do ADE9430 para o roteamento
    - conjunto do ADE9430 deslocado 4 mm para a esquerda, abrindo uma coluna
    (x ~ 61 mm) para o barramento retificado D101-D104 -> R101/PS101
    passar sem atravessar os filtros das entradas de tensão;
    - U604 (MCP3204) ao lado do ADE, do mesmo lado do barramento;
    - C403/C404 (DVDDOUT) junto dos pinos 1-3 e RC do RESET acima do CI,
    liberando o lado esquerdo para as entradas de corrente (pinos 7-14);
    - C401/C405 e C409/C410 fora da saída dos pinos digitais (31-40).
    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
    [Smart-Metering.kicad_pcb]
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2026-10-03 Corrige os achados da revisão automática do PR #1
    - BQ25895: divisor do TS invertido (R901 = 5,23 kΩ REGN-TS, R903 = 30,1 kΩ
    TS-GND); antes o carregador via sobretemperatura e não carregava.
    - Detecção da fonte: Q902 une D+/D- (DCP, 3 A) só com o AC/DC presente;
    só pelo USB-C a entrada fica em 500 mA. Q901 corta o VBUS quando o AC/DC
    está presente (prioridade do AC/DC sobre a porta USB). R912 polariza os dois.
    - DRC: classes DIVIDER_A/B/C, regras entre divisores de fases diferentes
    (3,0 mm), divisor x domínio metrológico (2,0 mm), divisor x rede de outras
    fases (3,0 mm), barramento HV com clearance e creepage, creepage da
    barreira 8,0 mm (com regra própria entre as f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
    [09_Power_Supplies.kicad_sch, Smart-Metering.kicad_pcb]
2026-10-03 Roteia o lado seguro e refaz o domínio quente com creepage de 8 mm
    - domínio quente refeito com o cobre até x = 73,65 mm (eixo) e o lado
    seguro a partir de x = 83,2 mm: menor distância quente-seguro através da
    barreira de 8,02 mm (fora as fileiras de pads dos isoladores);
    - RV101 2 mm à esquerda (F104 fixado) para abrir a coluna do barramento
    retificado junto da barreira;
    - lado seguro e ilha RS-485 roteados: GND_SYS/GND_485 em In1.Cu, +3V3 em
    In2.Cu, trilhas de potência de 0,6 mm estreitadas na saída dos CIs de
    passo fino; In2.Cu usado como camada de sinal em trechos curtos;
    - verificação geométrica da placa inteira: 0 violações;
    - restam 18 pads para ligar à mão (6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
    [Smart-Metering.kicad_pcb]
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2026-10-04 Corrige dois trechos inconsistentes do LAYOUT.md (revisão do PR #2)
    - seção de estado do posicionamento agora diz que a placa inteira está
    roteada, com 10 pads a ligar à mão;
    - modelos 3D: a afirmação vale para os footprints de componentes (os furos
    de fixação H1-H4 não têm modelo).
    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
